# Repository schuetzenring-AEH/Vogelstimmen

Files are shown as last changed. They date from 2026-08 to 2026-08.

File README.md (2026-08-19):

# Vogelstimmenkasten – Waldlehrpfad (Rev 2)

Neubau der Elektronik eines Vogelstimmenkastens für den Waldlehrpfad der Kolpingfamilie.

## Überblick

Besucher können per Knopfdruck (8 beleuchtete Taster) verschiedene Vogelstimmen anhören. Die Elektronik ist auf **null Ruhestrom** optimiert (Hardware-Latch) und wird über eine 12-V-Autobatterie betrieben.

**Architektur:** DY-SV17F (IO-Trigger, integrierter Class-D-Verstärker) + Hardware-Latch (MOSFET-Selbsthaltung)

## Projektstatus

| Phase | Status |
|---|---|
| Anforderungen | ✅ fertig |
| Systemarchitektur (BDD/IBD) | ✅ fertig |
| Schaltplan-Dokumentation Rev 2 | ✅ fertig |
| BOM-Verfügbarkeit (LCSC/JLCPCB) | ✅ geprüft |
| Digitaler Zwilling (Bauteilebene) | ✅ `docs/digitaler_zwilling.md` |
| KiCad-Schaltplan (+ VGS-Zener D11/D12) | ✅ verdrahtet |
| PCB Rev 2.4 + Respin F-01…F-05 | ✅ Working-PCB DRC/ERC 0 Fehler |
| Gerber / BOM / CPL | ✅ `hardware/V2.5-final/` (FREIGABE MIT AUFLAGEN) |
| M04-Review / Adversarial | ✅ F-01…F-09 dispositioniert; Proto-Auflagen |
| Fertigung & Inbetriebnahme | ▶️ JLCPCB bestellbar; Proto messen vor Serie |
| MBSE-Showcase (USB) | ✅ `showcase/` + `dist/Vogelstimmen-MBSE-USB.zip` |

**Reviewer-Einstieg:** [docs/reviewer_handoff.md](docs/reviewer_handoff.md) · Checkliste [docs/review_checkliste_m04.md](docs/review_checkliste_m04.md)  
Details: **[docs/zwischenstand.md](docs/zwischenstand.md)**

## Projektstruktur

| Ordner | Inhalt |
|---|---|
| `docs/` | Lastenheft, Architektur, ADRs, Traceability, Zwilling, Zwischenstand |
| `hardware/V2.5-final/` | Fertigungspaket Rev 2.5 (Gerber, BOM, CPL, KiCad, PDFs) |
| `simulation/` | Interaktive Platinen-Simulation (HTML5) |
| `showcase/` | **MBSE-Präsentation** (offline Website) — `START_SHOWCASE.bat` |
| `mbse/` | Impact-Analyse, Audit, SysML/JSON-Export — URL `/mbse/` |
| `dist/` | USB-ZIP nach `tools/package_mbse_usb.ps1` |
| `rev1_archiv/` | Rev-1-Archiv (Lessons Learned) |

## Technische Eckdaten

- **Audio-Modul:** DY-SV17F (8× IO-Trigger, Mode 0, 5W Class-D, USB-Upload)
- **Versorgung:** 12V Bleiakku → TPS62163 Buck → 5V
- **Stromsparen:** Hardware-Latch — Idle ≈12 µA (R6=470 kΩ, E-RPP-01)
- **Schutz:** Verpolung SI2301+**D11 Zener 6,2 V**, Latch Q1+**D12**, TVS SMAJ15A, PTC 1A/24V
- **Zähler:** Kübler K07.90 (5V DC, elektromechanisch, Anzeige oben, zählt Aufweck-Events)
- **Taster-LEDs:** 8× beleuchtete Taster (6–24V LEDs über 12V_SW Rail)
- **Audioformat:** MP3/WAV direkt per USB auf DY-SV17F laden
- **Digitaler Zwilling:** [docs/digitaler_zwilling.md](docs/digitaler_zwilling.md)

## Rev 1 → Rev 2: Lessons Learned

Rev 1 hatte Probleme mit Spannungsfestigkeit (U4/U5 Burnout bei 12V), Bauteil-Verfügbarkeit und fehlendem Verifikationsansatz. Rev 2 verwendet:
- MBSE / V-Modell mit Traceability
- Durchgängige Spannungsprüfung aller Bauteile
- BOM-Verfügbarkeit vorab bei LCSC geprüft
- Digitaler Zwilling zur Logikverifikation

## Voraussetzungen (Entwicklung)

- [KiCad 10](https://www.kicad.org/) – Schaltplan/PCB
- Python 3 – lokale Simulation (`python simulation/serve.py`) oder `START_SHOWCASE.bat` / `START_MBSE.bat`
- [LTspice](https://www.analog.com/en/resources/design-tools-and-calculators/ltspice-simulator.html) – analoge Teilschaltungen (optional)

## Lizenz

Dieses Projekt ist für den internen Gebrauch der Kolpingfamilie bestimmt.

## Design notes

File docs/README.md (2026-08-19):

# Dokumentation – Vogelstimmenkasten Rev 2.5

Stand: **3. August 2026**

## Showcase / Team-Demo

| Dokument / Ort | Inhalt |
|---|---|
| **[../showcase/](../showcase/)** | Interaktive V-Modell-/MBSE-Website (`START_SHOWCASE.bat`) |
| **[../mbse/](../mbse/)** | Impact-Analyse, Audit, Export (`/mbse/`) |
| **[mbse_pitch.md](mbse_pitch.md)** · **[mbse_pitch_krones.md](mbse_pitch_krones.md)** | Präsentation / Vorstand-Pitch |
| **[mbse_reise.md](mbse_reise.md)** | Abdeckungskarte: vorhanden / teilweise / weggelassen / offen |

## V-Modell — Spezifikation (links)

| Dokument | Inhalt |
|---|---|
| [stakeholder.md](stakeholder.md) | Stakeholder, Needs → Requirements |
| [anforderungen.md](anforderungen.md) | Lastenheft F/E/U/H/M |
| [pflichtenheft.md](pflichtenheft.md) | Implementierungs-Baseline, SYS-* |
| [use_cases.md](use_cases.md) | UC-01…05, Szenarien |
| [funktionsstruktur.md](funktionsstruktur.md) | Blackbox, Funktionsbaum |
| [systemarchitektur.md](systemarchitektur.md) | Blöcke B1–B8, Domänen, Zustände |
| [mbse_sysml.md](mbse_sysml.md) | SysML-Diagrammrollen (Mermaid/Tabellen) |
| [pbs_icd.md](pbs_icd.md) | Product Breakdown + Interface Control |
| [entscheidungen.md](entscheidungen.md) | ADRs |
| [risiko_fmea.md](risiko_fmea.md) | Risiko / Design-FMEA light |

## Design, Twin, Trace (Mitte / Thread)

| Dokument | Inhalt |
|---|---|
| [schaltplan.md](schaltplan.md) | Schaltplan-Blöcke, Netze, BOM-Link |
| [bom_verfuegbarkeit.md](bom_verfuegbarkeit.md) | LCSC / BOM-Gate M01 |
| [digitaler_zwilling.md](digitaler_zwilling.md) | Verhaltens-Twin |
| [traceability.md](traceability.md) | RTM Req → Funktion → Physikalisch → V |
| [digital_thread.md](digital_thread.md) | End-to-End-Verknüpfungskette |
| [kicad_anleitung.md](kicad_anleitung.md) | KiCad 10 Arbeitsfluss |

## V&V, Freigabe, Fertigung (rechts)

| Dokument | Inhalt |
|---|---|
| [vv_testplan.md](vv_testplan.md) | Teststrategie, TC-U/I/T/S/A |
| [reviewer_handoff.md](reviewer_handoff.md) | Einstieg Reviewer |
| [review_checkliste_m04.md](review_checkliste_m04.md) | M04-Checkliste |
| [../hardware/V2.5-final/docs/adversarial_review_v25.md](../hardware/V2.5-final/docs/adversarial_review_v25.md) | Adversarial Review Rev 2.5 |
| [montage_ibn.md](montage_ibn.md) | Montage & Inbetriebnahme |
| [service_betrieb.md](service_betrieb.md) | Service, Wartung, Constraints |
| [konfiguration_baseline.md](konfiguration_baseline.md) | CM / Baseline light |
| [../hardware/V2.5-final/](../hardware/V2.5-final/) | Gerber, BOM, CPL, PDFs, KiCad |

## Weitere / Historie

| Dokument | Inhalt |
|---|---|
| [zwischenstand.md](zwischenstand.md) | Projektstand |
| [pcb_v2.4.md](pcb_v2.4.md) u. a. | Ältere PCB-Stände |
| [datasheets/](datasheets/) | Datenblätter |
| `../rev1_archiv/docs/` | Rev‑1-Archiv |

**Bewusst weggelassen:** Business Case/Markt/ROI, APQP/PPAP, CE-Vollakte, CAD/FEM (Gehäuse Bestand), App-SRS (Modul-Firmware).

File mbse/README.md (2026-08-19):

# Platinen-MBSE App (Impact · Audit · Export)

Eigenständige Web-App unter GitHub Pages: **`/mbse/`**  
Showcase-Teaser: `#/copilot` · Präsentation: `#/pitch` oder [`presentation.html`](presentation.html)

Der Vogelstimmenkasten ist ein **exemplarischer Referenz-Rahmen** — klein, vollständig, übertragbar auf eine Produktlinie. Der Mehrwert ist nicht die Menge der Dokumente, sondern **Konsistenz, Durchgängigkeit und ein Digital Thread**.

## Start

Lokal (Python): `START_MBSE.bat` → http://127.0.0.1:8781/

Oder Showcase-Server: `START_SHOWCASE.bat` → http://127.0.0.1:8877/mbse/

What-if-Demo: [`index.html?demo=e03`](index.html?demo=e03) (E03: 12 → 18 Monate)

## Struktur

| Pfad | Rolle |
|---|---|
| `data/mbse-model.json` | Zentrale Quelle (Knoten + Kanten) |
| `data/impact-rules.json` | What-if-Regeln (battery_life, idle_current) |
| `js/graph-engine.js` | Traversal, Impact-Farben, Zyklen |
| `js/impact.js` | UI Graph + Listenansicht |
| `js/audit.js` | Traceability-Prüfungen |
| `js/export.js` | JSON / PlantUML / SysML v2 Text |
| `tools/build-model.mjs` | Regeneriert das JSON aus strukturierten Artefakten |

```bash
node mbse/tools/build-model.mjs
```

**IDs:** `F01` = Lastenheft-Requirement; `FIND-F-01` = adversarial Finding.

## Export-Grenze (ehrlich)

Phase 1 liefert textuellen SysML-v2-Subset + JSON. Kein zertifizierter Cameo/MagicDraw/Capella-Roundtrip. Modellverluste stehen im Export-Tab.

---

## Roadmap Phase 2–4 (nicht in Phase 1)

### Priorität 3 — KI Requirements Engineer

Eingabe: Freitext-Anforderung. Die KI erzeugt Stakeholder Need, System Requirement, Akzeptanzkriterien, Funktionszuordnung, Verifikationsmethode, Risiken und Traceability-Links — alle mit stabilen IDs.

- Statische App + optional API-Key (OpenAI/Anthropic) **oder** Offline: JSON exportieren → Cursor/CI → re-import
- Geplant: `js/ai-review.js` — Eindeutigkeit, Testbarkeit, Konflikte mit dem bestehenden Graph
- Kein Server auf GitHub Pages nötig für Demo v1 (Key im Browser, Nutzer-Hinweis)
- Human-in-the-loop: keine Auto-Freigabe

### Priorität 4 — Digital Twin + Änderungs-Simulation

„Was passiert wenn …“ (z. B. Batterie halbieren): Laufzeit, Risiko, Kosten, Testauswirkungen.

- Parameter aus Requirements (E03, E02) koppeln an [`../simulation/js/model.js`](../simulation/js/model.js)
- Impact-Graph markiert, welche Tests/Risiken neu bewertet werden
- Dashboard: Laufzeit, Risiko-Ampel, Kosten-Schätzung, Test-Invalidierung

### Priorität 5 — Review- und Freigabe-Cockpit

Governance-Dashboard (`/mbse/#/governance` oder Showcase-Teaser):

- Traceability Coverage, Testabdeckung, Risikoabdeckung
- Offene ADRs / Reviews
- Ampelsystem + Auditbericht (Erweiterung von `audit.js`)
- Management-KPIs: Time-to-Impact, Change-Rework — nicht Folienzahl

---

## Abnahme Phase 1

- [x] Präsentation 7 Folien, Demo-Sprung E03, druckbar (`presentation.html`, `@media print`)
- [x] Kernbotschaft: Mehrwert = Konsistenz/Digital Thread, nicht Dokumentenmenge
- [x] E03 12→18 Monate färbt Wirkungskette
- [x] Audit mit Findings (u. a. Unit-Tests ohne verifies)
- [x] JSON-Export = Modell; SysML/PlantUML enthalten IDs und Trace-Kanten
- [x] Showcase `#/pitch` + `#/copilot` → `/mbse/`

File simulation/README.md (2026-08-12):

# Platinen-Simulation (HTML5 + JS)

Interaktive **Rev-3.0**-Simulation: Taster drücken → Phasenablauf (inkl. Zähler-One-Shot) → Spannungen/Ströme pro Bauteil auf dem Platinen-Abbild.

## Start

**Empfohlen (frische Adresse, kein Cache von alter Session):**

```bash
simulation/start_rev25.bat
```

Öffnet **http://127.0.0.1:8766/**

Alternativ (Port 8765):

```bash
python simulation/serve.py
```

Port wählen: `python simulation/serve.py --port 8766`

## Aufbau

| Datei | Rolle |
|---|---|
| `index.html` | UI (Platine SVG, Taster, Tabelle) |
| `js/parts.js` | Datenblatt-Parameter (Rev 3.0, Laufzeit) |
| `js/model.js` | Verhaltensmodell inkl. One-Shot / Hengstler |
| `js/catalog.js` / `diagrams.js` | Baugruppen-Texte + SVG-Hilfsdiagramme |
| `src/parts.ts` / `src/model.ts` | TypeScript-Spiegel (Pflege parallel zu `js/`) |
| `pcb_layout.json` | Footprint-Positionen aus KiCad **V3.0** |
| `pcb_tracks.json` | Leiterbahnen + Vias |
| `tools/export_layout.py` | Neu-Export Footprints (KiCad-Python) |
| `tools/export_tracks.py` | Neu-Export Tracks/Vias (KiCad-Python) |

Nach PCB-Änderungen beide Exports mit KiCad-Python neu laufen lassen:

```bash
& "C:\Program Files\KiCad\10.0\bin\python.exe" simulation/tools/export_layout.py
& "C:\Program Files\KiCad\10.0\bin\python.exe" simulation/tools/export_tracks.py
```

## Rev 3.0 — Zähler-One-Shot (E-CNT-03/04)

| Ref | Rolle für den Hengstler |
|-----|---|
| **J5** | Hengstler **0.635.128** (12 V, Spule 1860 Ω): Pad1 = `12V_SW`, Pad2 = `CNT_LO` |
| **C20** | 1 µF: koppelt nur die Rising-Edge von `12V_SW` → `CNT_PULSE` |
| **R20** | 100 kΩ: Entladung / Pulsbreite (~R·C ≈ 100 ms, effektiv ~80 ms) |
| **R21** | 100 Ω: Serie zum Gate von Q7 |
| **D23** | Clamp: hält `CNT_PULSE` ≥ −Vf gegen GND |
| **Q7** | AO3400 Low-Side: zieht `CNT_LO` kurz nach GND → Spule zählt +1 |
| **D10** | Freilauf parallel zur Spule (K→`12V_SW`, A→`CNT_LO`) |

Phase `cnt_pulse`: Latch gerade AN, Spulenstrom ≈6,5 mA für ~80 ms, danach Spule aus für den Rest der Session. Idle: `12V_SW` tot → 0 mA.

## Respin (weiterhin gültig)

| Fix | Simulation |
|-----|---|
| F-01 D15–D22 | Serie-Dioden U2↔IOx |
| F-02 R5=0 Ω | VOS direkt 5 V |
| F-03 R13+C4 | RC-Blanking Q3_GATE (~470 ms) |
| F-04 R12 | LED-Strombegrenzung 12V_LED |

## Modellierung

- **Diskret (Ohm/Kirchhoff):** R1–R13, R20/R21, Dioden, Zener-Clamp, FET als Schalter mit Rds(on)/VGS
- **Blöcke:** TPS62163 (η + IQ), DY-SV17F (Boot/BUSY/Play-Strom), Hengstler (Rcoil 1860 Ω @12 V, nur während One-Shot)
- **Kein** SPICE-Transient — DC-Arbeitspunkte pro Phase; RC-Blanking + One-Shot als Timer

## Datenblätter

Siehe `docs/datasheets/`, `hardware/V3.0/docs/` und Parameter in `js/parts.js`.

| Bauteil | Parameter | Quelle |
|---|---|---|
| SI2301CDS | VGS max ±8 V, RDS(on) typ 90 mΩ | Vishay |
| AO3400 (Q7) | Low-Side CNT_LO | AOS / LCSC C20917 |
| Hengstler 0.635.128 | 12 V, 1860 Ω ≈80 mW, min. Impuls 50 ms | Hengstler 634/635 |
| DY-SV17F | Idle **14 mA**; Betrieb **≤60 mA**; V33 max 80 mA | Messung / Spec |
| R6 | 470 kΩ → Idle ≈12 µA | E-RPP-01 |

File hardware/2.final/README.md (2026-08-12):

# Fertigungspaket Rev 2.4 — `2.final`

**Datum:** 3. August 2026  
**Projekt:** Soundplatine Waldlehrpfad / Kolping Alteglofsheim  
**KiCad Working:** `hardware/vogelstimmen_v2.4.*`

> **Hinweis:** Dieses Paket ist **Pre-Respin** (Stand 01.08.2026).  
> Vor JLCPCB-Bestellung aus dem **aktuellen Working-PCB** (Respin F-01…F-05) neu exportieren: Gerber, BOM, CPL, PDFs.

## Respin F-01…F-05 (Working-PCB)

| Änderung | Bauteile |
|---|---|
| Modul-IO-Schutz | D15–D22 |
| VOS direkt | R5 = 0 Ω |
| BUSY-Blanking | R13, C4 |
| LED-Serie | R12, Netz 12V_LED |
| SPK-Breite | ≥ 0,4 mm |

DRC/ERC Working: **0 Fehler** (Stand 03.08.2026).

## Inhalt (Stand Paket)

| Datei / Ordner | Zweck |
|---|---|
| `vogelstimmen_v2.4.kicad_sch` | Schaltplan (KiCad) — **ggf. veraltet** |
| `vogelstimmen_v2.4.kicad_pcb` | Layout — **Pre-Respin** |
| `vogelstimmen_v2.4-Gerber.zip` | Gerber — **Pre-Respin** |
| `JLCPCB_BOM.csv` | SMD-BOM — **Respin-Zahlen aktualisiert** |
| `docs/` | Review-Dokumente |

Aktuelle Quellen: `../vogelstimmen_v2.4.kicad_pcb`, `../../docs/schaltplan.md`

## Manuell (nicht JLCPCB-SMD)

- **U2** DY-SV17F  
- **J5** Kübler `1.130.900.008`  
- **J3/J4/J1/J2/J6** Phoenix MPT  

## Design-Review

[`../../docs/reviewer_handoff.md`](../../docs/reviewer_handoff.md) · [`../../docs/review_checkliste_m04.md`](../../docs/review_checkliste_m04.md)

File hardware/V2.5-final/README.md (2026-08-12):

# Fertigungspaket Rev 2.5 — `V2.5-final`

**Datum:** 3. August 2026  
**Projekt:** Soundplatine Waldlehrpfad · Kolping Alteglofsheim · Konrad Senn  
**KiCad:** 10.0.4 · Quelle: `vogelstimmen_v2.5.kicad_*` (Respin F-01…F-05 + GND-Vias)

## Freigabe-Stand

| Check | Ergebnis |
|---|---|
| **DRC** | **0 Fehler**, 0 unverbunden — 1 Warnung U2 Footprint-Lib (`DRC_v2.5_final.rpt`) |
| **ERC** | **0 Fehler** — 1 Warnung Label `SET_DRV` (`ERC_v2.5_final.rpt`) |
| **F-01…F-09** | Behoben / dispositioniert — `docs/adversarial_review_v25.md` |

## JLCPCB — Upload (nur SMD)

| Datei | Zweck |
|---|---|
| **`vogelstimmen_v2.5-Gerber.zip`** | Gerber + Drill (Ordner `Gerber/`) |
| **`JLCPCB_BOM.csv`** | **nur SMT** — Spalte `Mount=SMT` · kein Modul/Klemmen/Zähler |
| **`JLCPCB_CPL.csv`** | Pick-and-Place **JLCPCB-Format** (Designator/Mid X/Mid Y) — **diese** hochladen |
| `vogelstimmen_v2.5-cpl.csv` | KiCad-Roh-CPL (nicht für Upload — falsche Spaltennamen) |

**Nicht** an JLCPCB hochladen: `HAND_BESTUECKUNG.csv`, `vogelstimmen_v2.5-bom.csv` (KiCad-Voll-BOM mit THT).

**Platinen-Parameter (empfohlen):** 2 Layer · 1,6 mm · HASL oder ENIG · Design-Regeln wie im Projekt (0,2 mm Clearance, Via 0,6/0,3 mm).

## Handbestückung (nicht in JLCPCB-BOM)

Datei: **`HAND_BESTUECKUNG.csv`** — Spalte `Assembly=HAND` bzw. `DNP` (Testpads).

| Ref | Teil | Assembly |
|-----|---|---|
| **U2** | DY-SV17F (optional 2×9-Pin-Sockel) | HAND |
| **J5** | Kübler `1.130.900.008` | HAND |
| **J1, J2, J6** | Phoenix MPT 0,5/2-2,54 (×3) | HAND |
| **J3, J4** | Phoenix MPT 0,5/8-2,54 (×2, z. B. 1725711) | HAND |
| **TP1–TP5** | Testpads | DNP (kein Bauteil) |

## Paketinhalt

| Datei / Ordner | Inhalt |
|---|---|
| `Gerber/` | Einzel-Gerber + `.drl` + `.gbrjob` |
| `vogelstimmen_v2.5-Gerber.zip` | Upload-Paket |
| `JLCPCB_BOM.csv` | **SMT-only** für JLCPCB Assembly |
| `JLCPCB_CPL.csv` | **CPL Upload** (JLCPCB-Spaltennamen) |
| `JLCPCB_CPL_minimal.csv` | Fallback-CPL (nur 5 Spalten), falls volles Format scheitert |
| `HAND_BESTUECKUNG.csv` | **Handteile** + DNP-Testpads (nicht JLCPCB) |
| `vogelstimmen_v2.5-bom.csv` | KiCad-Voll-BOM (SMT+THT — nicht für SMT-Upload) |
| `vogelstimmen_v2.5-cpl.csv` | KiCad-Roh-CPL (nicht hochladen) |
| `vogelstimmen_v2.5-all-pos.csv` | Alle Positionen |
| `vogelstimmen_v2.5-schematic.pdf` | Schaltplan-PDF |
| `vogelstimmen_v2.5-pcb.pdf` | Layout-PDF |
| `vogelstimmen_v2.5.kicad_sch/pcb/pro` | KiCad-Quellen (Stand Export) |
| `docs/` | DRC/ERC, Review, Schaltplan-Doku |
| `simulation/` | HTML5-Platinen-Simulation Rev 2.5 (siehe unten) |

## Simulation

**Empfohlen:** Doppelklick auf `simulation/start_rev25.bat`  
→ **http://127.0.0.1:8766/** (eigener Port, umgeht Browser-Cache von :8765)

Alternativ: `python simulation/serve.py` → http://127.0.0.1:8765/

## Änderungen Rev 2.5 (gegenüber Erstlayout vor Respin, archiviert)

| ID | Änderung |
|----|---|
| F-01 | D15–D22 Serie U2↔IOx |
| F-02 | R5 = 0 Ω |
| F-03 | R13 + C4 BUSY-Blanking |
| F-04 | R12 = 10 Ω → 12V_LED |
| F-05 | SPK ≥ 0,4 mm (Haupt 0,8 mm) |
| Layout | +13 GND-Vias (Stitching U1/C1–C4) |

## IBN-Hinweise

- **USB:** nur Modul abgezogen oder Latch aus (F-09)  
- **Proto optional:** F-03 Oszi, F-04 LED-Strom, F-08 5 V unter Last  

Review: `docs/reviewer_handoff.md` · Checkliste: `docs/review_checkliste_m04.md`

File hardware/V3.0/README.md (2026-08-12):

# Fertigungspaket Rev 3.0

**Datum:** 11. August 2026  
**Projekt:** Soundplatine Waldlehrpfad · Kolping Alteglofsheim  
**KiCad:** 10.0.4 · `vogelstimmen_v3.0.kicad_*`

## Freigabe-Stand

| Check | Ergebnis |
|---|---|
| **DRC** | **0 Fehler**, 0 unverbunden — 1 Warnung U2 Footprint-Lib (`DRC_v3.0_final.rpt`) |
| **ERC** | siehe `ERC_v3.0_final.rpt` |
| **Widerstände** | alle **15×** `R_0603_1608Metric`, Pad-Pitch **1,65 mm** (kein 0402) |
| **Zähler** | Hengstler 0.635.128 + One-Shot (C20/R20/R21/D23/Q7/D10) |

## JLCPCB — Upload (nur SMD)

| Datei | Zweck |
|---|---|
| **`vogelstimmen_v3.0-Gerber.zip`** | Gerber + Drill (auch Ordner `Gerber/`) |
| **`JLCPCB_BOM.csv`** | SMT-BOM inkl. One-Shot + 0603 Basic LCSC |
| **`JLCPCB_CPL.csv`** | Pick-and-Place (52 SMT-Teile) — **diese** hochladen |
| `JLCPCB_CPL_minimal.csv` | Fallback (5 Spalten), falls volles Format scheitert |

**Nicht** an JLCPCB hochladen: `HAND_BESTUECKUNG.csv`, KiCad-Roh-CPL mit Handteilen.

**Platinen-Parameter (empfohlen):** 2 Layer · 1,6 mm · HASL oder ENIG · Clearance 0,2 mm · **Min. Bahnbreite 0,3 mm** · Via 0,6/0,3 mm.

## Handbestückung (nicht in JLCPCB-BOM)

Datei: **`HAND_BESTUECKUNG.csv`**

| Ref | Teil | Assembly |
|-----|---|---|
| **U2** | DY-SV17F | HAND |
| **J5** | Hengstler **0.635.128** (nicht 0.635.132) | HAND |
| **J1, J2, J6** | Phoenix MPT 0,5/2 | HAND |
| **J3, J4** | Phoenix MPT 0,5/8 | HAND |
| **TP1–TP5** | Testpads | DNP |

## Widerstände — Package-Check (E-R0603)

| Refs | Wert | Footprint PCB | LCSC | Package |
|---|---|---|---|---|
| R1,R2,R13,R20 | 100k | R_0603_1608Metric | C25803 | 0603 Basic |
| R3,R4,R9 | 10k | R_0603_1608Metric | C25804 | 0603 Basic |
| R5 | 0R | R_0603_1608Metric | C21189 | 0603 Basic |
| R6 | 470k | R_0603_1608Metric | C23178 | 0603 Basic |
| R7,R8,R11 | 4.7k | R_0603_1608Metric | C23162 | 0603 Basic |
| R10 | 1k | R_0603_1608Metric | C21190 | 0603 Basic |
| R12 | 10R | R_0603_1608Metric | C22859 | 0603 Basic |
| R21 | 100R | R_0603_1608Metric | C25796 | 0603 Basic |

Pads gemessen: **0,80×0,95 mm**, Mittenabstand **1,65 mm** → passt zu 0603 (0402 wäre ~1,0 mm).

## Änderungen gegenüber 2.5

| Thema | 2.5 | 3.0 |
|---|-----|-----|
| Widerstände | Pads oft 0402 / LCSC 0603 → Reject | **0603 Pads + 0603 Basic LCSC** |
| Zähler J5 | Kübler K07.90 | **Hengstler 0.635.128** + One-Shot ~80 ms |
| Form | Panel / groß | Body **25,2×31 mm**, 4 Pins 15,24×25,4 mm |

## Paketinhalt

| Datei / Ordner | Inhalt |
|---|---|
| `Gerber/` | Einzel-Gerber + PTH/NPTH Drill |
| `vogelstimmen_v3.0-Gerber.zip` | **Upload-Paket** |
| `JLCPCB_BOM.csv` / `JLCPCB_CPL.csv` | SMT Assembly |
| `HAND_BESTUECKUNG.csv` | Handteile |
| `vogelstimmen_v3.0-schematic.pdf` | Schaltplan |
| `vogelstimmen_v3.0-pcb.pdf` | Layout |
| `docs/` | ADRs, Schaltplan, BOM-Checkliste |
| `tools/export_fab.py` | Re-Export Gerber/CPL/PDF |

## Re-Export

```powershell
& "C:\Program Files\KiCad\10.0\bin\python.exe" hardware\V3.0\tools\export_fab.py
```

## Parallel bestellen

1. JLCPCB: Gerber.zip + BOM + CPL (SMD Assembly)
2. Hengstler 0.635.128 (Mercateo/RS/Farnell) — Lieferzeit oft Wochen
3. DY-SV17F + Phoenix MPT-Klemmen

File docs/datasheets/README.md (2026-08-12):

# Datenblätter

Lokal gespeicherte PDFs (Stand 01.08.2026) + Simulationsparameter in `simulation/js/parts.js`.

| Datei | Bauteil | Status |
|---|---|---|
| [Si2301CDS.pdf](Si2301CDS.pdf) | Vishay SI2301CDS P-FET | OK |
| [TPS62163.pdf](TPS62163.pdf) | TI TPS62163 Buck 5 V | OK |
| [BZX84C6V2_Nexperia.pdf](BZX84C6V2_Nexperia.pdf) | BZX84 Serie (6,2 V) | OK |
| [SMAJ15A.pdf](SMAJ15A.pdf) | Vishay/SMAJ TVS 15 V | OK |
| [DY-SV17F.pdf](DY-SV17F.pdf) | Audio-Modul Functions (kein Iq; V33 max 80 mA) | OK |
| [Kuebler_K04-K07.pdf](Kuebler_K04-K07.pdf) | Kübler K04–K07 (historisch, E-CNT-01) | Archiv |
| [Kuebler_K04-K07_AK07.pdf](Kuebler_K04-K07_AK07.pdf) | Kübler (älterer Stand) | Archiv |

**Zähler Rev 3.0:** Hengstler **0.635.128** — PDF unter `hardware/V3.0/docs/Hengstler_634_635.pdf` (bzw. Impulse-Automation Datasheet). Kübler gestrichen (E-CNT-02).

**Nicht lokal (CDN-Block):** onsemi 2N7002L / 1N4148WS — Parameter aus Hersteller-Datenblatt übernommen (siehe `simulation/js/parts.js`).

### DY-SV17F — Strom (extern belegt)

| | Wert | Quelle |
|--|---|---|
| Idle | **14 mA** @5 V | Messung (Amp LTK5128 + Flash) — [GitHub arduino12](https://github.com/arduino12/mp3_player_module_wire) |
| Betrieb | **≤60 mA** @5 V | Spec „Потребление тока: до 60мА“ — [compacttool.ru](https://compacttool.ru/mp3wav-pleer-dy-sv17f-s-mono-audiousilitelem-5vt) |
| V33 | max 80 mA | Modul-PDF (**Ausgang**, nicht Modul-Iq) |
| Lautsprecher | zusätzlich | Class-D; Spitzen je nach Pegel höher |

### Bestellhinweis Zähler (Rev 3.0)

**Hengstler 0.635.128** (Typ 635.1, 12 V, 6 Stellen, Spule 1860 Ω ≈80 mW, 4 PCB-Pins). Ansteuerung: One-Shot an `12V_SW` (nicht dauerhaft an 5 V). Details: `hardware/V3.0/docs/entscheidungen_v30.md`.

~~K07.90 1.130.900.008~~ — nicht mehr beschaffbar / ersetzt.

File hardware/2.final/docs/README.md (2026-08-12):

# Dokumentation – Vogelstimmenkasten Rev 2

Stand: **3. August 2026**

## Review vor Fertigung (Start hier)

| Dokument | Inhalt |
|---|---|
| **[reviewer_handoff.md](reviewer_handoff.md)** | **Einstieg für Reviewer** — Lesereihenfolge, Scope, Artefakte |
| **[review_checkliste_m04.md](review_checkliste_m04.md)** | **M04-Checkliste** — abhaken + Signatur Freigabe/Sperre |
| **[adversarial_review_v24.md](adversarial_review_v24.md)** | **Adversarial Review** — F-01…F-09 geschlossen (Respin + Restrisiko) |
| [zwischenstand.md](zwischenstand.md) | Aktueller Projektstand |
| `../hardware/2.final/` | Gerber, BOM, CPL, PDFs |

Canvas (Cursor, neben Chat): `fertigung-readiness-v24.canvas.tsx`

## Dokumente

| Dokument | Inhalt |
|---|---|
| [anforderungen.md](anforderungen.md) | Lastenheft — Muss- und Kann-Anforderungen |
| [systemarchitektur.md](systemarchitektur.md) | BDD, IBD, Zustandsdiagramm, Timing, Spannungsebenen |
| [digitaler_zwilling.md](digitaler_zwilling.md) | Digitaler Zwilling System→Block→**Bauteil** (inkl. VGS-Zener) |
| [schaltplan.md](schaltplan.md) | Schaltplan Rev 2 — Blöcke B1–B8, Netzliste, BOM |
| [bom_verfuegbarkeit.md](bom_verfuegbarkeit.md) | LCSC-Verfügbarkeit aller SMD-Bauteile |
| [traceability.md](traceability.md) | Traceability-Matrix und Verifikationsplan |
| [kicad_anleitung.md](kicad_anleitung.md) | KiCad 10 — Labels, ERC, Footprints, VGS-Verdrahtung |
| [entscheidungen.md](entscheidungen.md) | Designentscheidungen (Latch, VGS, Zähler, MPT) |
| [pcb_v2.4.md](pcb_v2.4.md) | PCB Rev 2.4 |
| [datasheets/](datasheets/) | Datenblätter (Kübler u. a.) |

## Archiv

Rev-1-Dokumentation liegt in `../rev1_archiv/docs/`.

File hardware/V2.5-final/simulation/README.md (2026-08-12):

# Platinen-Simulation (HTML5 + TypeScript/JS)

Interaktive Rev-2.5-Simulation: Taster drücken → Phasenablauf → Spannungen/Ströme pro Bauteil auf dem Platinen-Abbild.

## Start

**Empfohlen (frische Adresse, kein Cache von alter Session):**

```bash
simulation/start_rev25.bat
```

Öffnet **http://127.0.0.1:8766/**

Alternativ (Port 8765):

```bash
python simulation/serve.py
```

Öffnet `http://127.0.0.1:8765/`.

Port wählen: `python simulation/serve.py --port 8766`

## Aufbau

| Datei | Rolle |
|---|---|
| `index.html` | UI (Platine SVG, Taster, Tabelle) |
| `src/parts.ts` | Datenblatt-Parameter (TypeScript-Quelle) |
| `src/model.ts` | Verhaltensmodell (TypeScript-Quelle) |
| `js/parts.js` / `js/model.js` / `js/app.js` | Lauffähige ESM-Module |
| `pcb_layout.json` | Footprint-Positionen aus KiCad v2.5 (63 Bauteile, 32 Vias) |
| `pcb_tracks.json` | Leiterbahnen + Vias |
| `tools/export_layout.py` | Neu-Export Footprints (KiCad-Python) |
| `tools/export_tracks.py` | Neu-Export Tracks/Vias (KiCad-Python) |

Nach PCB-Änderungen beide Exports mit KiCad-Python neu laufen lassen:

```bash
& "C:\Program Files\KiCad\10.0\bin\python.exe" simulation/tools/export_layout.py
& "C:\Program Files\KiCad\10.0\bin\python.exe" simulation/tools/export_tracks.py
```

## Rev 2.5 (Respin)

| Fix | Simulation |
|-----|---|
| F-01 D15–D22 | Serie-Dioden U2↔IOx in `parts.js` / `catalog.js` |
| F-02 R5=0 Ω | VOS direkt 5 V |
| F-03 R13+C4 | RC-Blanking Q3_GATE (~470 ms) in `model.js` |
| F-04 R12 | LED-Strombegrenzung 12V_LED |
| Layout | 32 GND-Vias in `pcb_tracks.json` |

## Modellierung

- **Diskret (Ohm/Kirchhoff):** R1–R13, Dioden, Zener-Clamp, FET als Schalter mit Rds(on)/VGS
- **Blöcke:** TPS62163 (η + IQ), DY-SV17F (Boot/BUSY/Play-Strom), Kübler (Rcoil aus 50 mW @ 4,5 V)
- **Kein** SPICE-Transient — DC-Arbeitspunkte pro Phase; RC-Blanking als einfacher Tiefpass

## Datenblätter

Siehe `docs/datasheets/` und Parameter-Kommentare in `js/parts.js`.

### Wichtige verifizierte Werte

| Bauteil | Parameter | Quelle |
|---|---|---|
| SI2301CDS | VGS max ±8 V, RDS(on) typ 90 mΩ @−4,5 V | Vishay |
| BZX84C6V2 | Vz 6,2 V | Nexperia/Good-Ark |
| 2N7002L | VGS(th) 1–2,5 V, RDS max 7,5 Ω | onsemi |
| TPS62163 | VOUT 5 V fest, IQ typ 17 µA | TI SLVSAM2E |
| SMAJ15A | VRWM 15 V, VBR 16,7–18,5 V | Littelfuse |
| K07.90 | ~50 mW @ Unenn (10 Hz) → @5 V ≈12 mA | Kübler |
| DY-SV17F | Idle **14 mA** (Messung); Betrieb **≤60 mA** (Spec); V33 max 80 mA | siehe unten |
| R6 | 470 kΩ → Idle ≈12 µA | E-RPP-01 |

### DY-SV17F Ströme (Quellen)

| Zustand | Strom | Quelle |
|---|---|---|
| Idle (powered, kein Play) | **14 mA** | Messung inkl. LTK5128 + 32 Mbit Flash; Sleep-Befehl wirkungslos — [arduino12/mp3_player_module_wire](https://github.com/arduino12/mp3_player_module_wire) |
| Betrieb (рабочий режим) | **bis 60 mA** | Händler-Spec — [compacttool.ru](https://compacttool.ru/mp3wav-pleer-dy-sv17f-s-mono-audiousilitelem-5vt) |
| Lautsprecher | extra (Sim: `Ispk_avg`) | Class-D; Spitzen je nach Lautstärke deutlich höher (Foren: ~110 mA … Angaben bis 500 mA) |
| V33-Ausgang | max **80 mA** | Modul-PDF — *Ausgang*, nicht Modul-Iq |

Im Hersteller-Functions-PDF steht **kein** Versorgungsstrom — nur V33-Limit.

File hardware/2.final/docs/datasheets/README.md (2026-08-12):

# Datenblätter

Lokal gespeicherte PDFs (Stand 01.08.2026) + Simulationsparameter in `simulation/js/parts.js`.

| Datei | Bauteil | Status |
|---|---|---|
| [Si2301CDS.pdf](Si2301CDS.pdf) | Vishay SI2301CDS P-FET | OK |
| [TPS62163.pdf](TPS62163.pdf) | TI TPS62163 Buck 5 V | OK |
| [BZX84C6V2_Nexperia.pdf](BZX84C6V2_Nexperia.pdf) | BZX84 Serie (6,2 V) | OK |
| [SMAJ15A.pdf](SMAJ15A.pdf) | Vishay/SMAJ TVS 15 V | OK |
| [DY-SV17F.pdf](DY-SV17F.pdf) | Audio-Modul Functions (kein Iq; V33 max 80 mA) | OK |
| [Kuebler_K04-K07.pdf](Kuebler_K04-K07.pdf) | Kübler K04–K07 / K07.90 | OK |
| [Kuebler_K04-K07_AK07.pdf](Kuebler_K04-K07_AK07.pdf) | Kübler (älterer Stand) | OK |

**Nicht lokal (CDN-Block):** onsemi 2N7002L / 1N4148WS — Parameter aus Hersteller-Datenblatt übernommen (siehe `simulation/js/parts.js`).

### DY-SV17F — Strom (extern belegt)

| | Wert | Quelle |
|--|---|---|
| Idle | **14 mA** @5 V | Messung (Amp LTK5128 + Flash) — [GitHub arduino12](https://github.com/arduino12/mp3_player_module_wire) |
| Betrieb | **≤60 mA** @5 V | Spec „Потребление тока: до 60мА“ — [compacttool.ru](https://compacttool.ru/mp3wav-pleer-dy-sv17f-s-mono-audiousilitelem-5vt) |
| V33 | max 80 mA | Modul-PDF (**Ausgang**, nicht Modul-Iq) |
| Lautsprecher | zusätzlich | Class-D; Spitzen je nach Pegel höher |

### Bestellhinweis K07.90

7-stellig, PCB liegend, Anzeige oben. Bestellnr. **1.130.900.008** (4,5 V DC / 10 Hz). Leistung ≈50 mW → bei 5 V-Rail ≈12 mA.

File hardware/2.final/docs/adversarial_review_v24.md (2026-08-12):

# Adversarial Hardware Review — Rev 2.4

**Rolle:** Senior Hardware / PCB Reviewer (Widerlegung, nicht Bestätigung)  
**Datum:** 1. August 2026  
**Quellen:** `vogelstimmen_v2.4.kicad_sch/pcb`, `docs/schaltplan.md`, TI SLVSAM2, Kübler/SI2301-Annahmen, `hardware/2.final/`

**Gesamtverdict (01.08.): SPERRE vor Fertigung** — mindestens zwei blockierende Schaltungs-/Datenblattfehler.

**Disposition F-01…F-09 (03.08.2026):** Alle Punkte **behoben** oder **Restrisiko bewusst akzeptiert** — siehe Tabelle unten. F-10…F-13 unverändert offen (Moderate/Minor).

| ID | Status | Maßnahme / Begründung |
|----|---|---|
| **F-01** | ✅ **Behoben** | D15–D22 Serie U2↔IOx (Respin) |
| **F-02** | ✅ **Behoben** | R5 = 0 Ω (VOS direkt) |
| **F-03** | ✅ **Behoben** | R13 + C4 BUSY-Blanking; Proto-Oszi empfohlen, nicht blockierend |
| **F-04** | ✅ **Behoben** | R12 = 10 Ω → 12V_LED; Strom/R12-Temp. im Betrieb messen |
| **F-05** | ✅ **Behoben** | SPK-Hauptpfad 0,8 mm; Stubs ≥ 0,4 mm (TP/J2) |
| **F-06** | ✅ **Akzeptiert** | Tasterleitungen **≤ 30 cm im Schrank** — Feld-ESD entfällt praktisch |
| **F-07** | ✅ **Akzeptiert** | SI2301 20 V vs. SMAJ15A ~24 V; Batteriebetrieb, kein Jumpstart |
| **F-08** | ✅ **Akzeptiert** | Hauptpfad 12V 0,5–0,7 mm; U1-Pad-Stubs 0,2–0,3 mm (Platzzwang); 0,2 mm nur Latch-Zweig |
| **F-09** | ✅ **Akzeptiert** | IBN: USB nur Modul abgezogen / Latch aus (Sockel) |

**Respin-Status:** F-01…F-05 im Working-PCB (`hardware/vogelstimmen_v2.4.*`). DRC **0** Fehler / **0** unverbunden; ERC **0** Fehler; Schaltplan-Parität OK. Fertigungspaket `2.final/` noch neu exportieren.

---

## F-01 · BLOCKER — 12 V-Domain an DY-SV17F-IOs (D1–D8) · **FIXED (Respin)**

**Befund (PCB verifiziert):** D1…D8: Pad1 (Kathode) = `/IOx`, Pad2 (Anode) = `/BTN_OR`; R9 = 10 kΩ von `/12V_PROT` → `/BTN_OR`. IOx liegen parallel an U2 und J3.

### 1. Warum Risiko?
Im Idle liegt `BTN_OR` ≈ 12 V. Die Dioden leiten vorwärts in die IO-Pins. Unversorgtes Modul: IO-Spannung / Phantom-Supply über ESD-Dioden → AbsMax verletzt, Latch-up, Zerstörung.  
Bei 5 V an: interne Pull-ups ≈ 3,3 V → Dioden leiten dauernd → `BTN_OR` wird auf ≈ 4 V geklemmt → Q6 bleibt ein → Doku „Idle BTN_OR=12 V, kein Strom“ ist falsch. Zusätzlich ~0,8–1 mA Idle-Pfad möglich → E02 (<100 µA) gebrochen.

### 2. Wahrscheinlichkeit
**Hoch** (Topologie zwingend; nicht spekulativ).

### 3. Schaden
**Kritisch** — Modul tot / unzuverlässig; Idle-Strom-Ziel verfehlt; möglicherweise Dauer-SET über Q6.

### 4. Korrektur
12 V-OR und Modul-IO galvanisch trennen, z. B.:
- Taster-Knoten nur über Transistor/Open-Collector → Q6-Gate/`BTN_OR`, **ohne** Diode von 12 V in IOx, **oder**
- getrennte Leitungen (IO nur 5 V-Domain; Latch-SET eigener Pfad),  
- plus IO-Serien-R + Clamp an 5 V nach Neudesign.  
**Respin Schaltplan+PCB nötig.** Nicht durch BOM-Tausch heilbar.

---

## F-02 · BLOCKER — R5 = 100 kΩ in VOS (TPS62163) · **FIXED (R5→0R)**

**Befund:** R5 zwischen `/5V` und `/VOS` (U1 Pin 6). TI: *„VOS pin should connect in the shortest way to VOUT at the output capacitor.“*

### 1. Warum Risiko?
VOS ist Regelkreis-Sense. 100 kΩ + Rauschen/kapazitive Kopplung → falsche Ausgangsspannung, Jitter, im Extrem IC-Stress. Datenblatt verlangt **kurze direkte** Verbindung, keinen 100 k-Vorwiderstand.

### 2. Wahrscheinlichkeit
**Hoch**, dass Regulation außerhalb Spec oder instabil (Layout+100 k).

### 3. Schaden
**Hoch** — 5 V falsch → Kübler/Modul außerhalb Fenster; Buck kann fehlverhalten.

### 4. Korrektur
R5 → **0 Ω** oder R5 entfernen und VOS direkt an C3/`5V` legen (kurze Trace). Vor Order patchen (Handlöten 0 Ω auf Proto möglich, besser Layout-Fix).

---

## F-03 · MAJOR — Kaltstart / BUSY-Race (Mode 0 Flanke) · **FIXED (R13+C4; Proto-Oszi empfohlen)**

### 1. Warum Risiko?
Latch weckt erst die 5 V-Schiene. Mode 0 braucht **fallende Flanke** an IOx *nachdem* das Modul lebt. Kurzer Tastendruck vor Boot-Ende (~150 ms + CON3-Fenster 30 ms) → kein Play. Danach BUSY=HIGH → Q3 → Latch aus → „tot beim ersten Druck“.  
Zusätzlich: sobald BUSY als Ausgang HIGH ist und noch kein Play läuft, killt Q3 die Versorgung.

### 2. Wahrscheinlichkeit
**Mittel–hoch** (abhängig Tastendauer / Modul-Firmware; in Feld oft reproduzierbar).

### 3. Schaden
**Hoch funktional** (wirkt „defekt“), selten Hardwareschaden.

### 4. Korrektur
BUSY-Release verzögern/qualifizieren (RC + Schmitt, oder Release erst nach BUSY Low→High *nach* Play); oder Level-Trigger-Mode; oder monostabile Verlängerung des IO-Lows über Boot; Prototyp **oszi** Pflicht vor Serie.

---

## F-04 · MAJOR — Keine Strombegrenzung Taster-LEDs (J6) · **FIXED (R12=10Ω; Messung im Betrieb)**

**Verifikation:** Strom am LED-Ring + R12-Temperatur bei Dauerplay messen (Ziel ~50–120 mA gesamt).

### 1. Warum Risiko?
J6 = Roh-`12V_SW` + GND. Annahme „6–24 V LEDs mit Vorwiderstand“ ist **feldabhängig**. Ohne interne R: LED-/Kabelkurzschluss → hoher Strom über Q1 (SI2301), Thermik, PTC erst spät.

### 2. Wahrscheinlichkeit
**Mittel** (hängt von verbauten Tastern).

### 3. Schaden
**Mittel–hoch** — LED kaputt, Q1/Leiterbahn stress, entladene Batterie.

### 4. Korrektur
Serienwiderstand oder Konstantstrom auf Platine; max. LED-Strom spezifizieren; Kurzschlussfestigkeit prüfen; Annahme in Lastenheft verbindlich machen.

---

## F-05 · MAJOR — SPK-Bahnen stellenweise nur 0,2 mm · **FIXED (Hauptpfad 0,8 mm)**

**PCB:** U2→Lautsprecher **0,8 mm**; kurze Stubs zu TP5/J2 **≥ 0,4 mm**.

### 1. Warum Risiko?
Class-D-Peaks ≫ Mittelstrom. 0,2 mm auf `SPK+` (PCB-Auswertung) → I²R, Spannungsabfall, lokal Hitze, EMI durch hohe dI/dt in schmalen Spuren.

### 2. Wahrscheinlichkeit
**Mittel** bei 4 Ω / hoher Lautstärke.

### 3. Schaden
**Mittel** — Verzerrung, Warmstellen, im Extrem Pad-Stress.

### 4. Korrektur
SPK± auf ≥0,5–0,8 mm (besser Kupferfläche); kurze Wege U2→J2.

---

## F-06 · MAJOR — ESD / lange Tasterleitungen ohne Schutz · **AKZEPTIERT (Einsatzkontext)**

**Disposition (03.08.2026):** Review ging von Meter-Kabeln im Wald aus. **Tatsächlicher Aufbau:** Tasterleitungen **max. 30 cm**, **im Schrank** — ESD/EFT-Risiko praktisch vernachlässigbar. D15–D22 schützen Modul vor 12-V-Domain. **Keine TVS an J3.**

### 1. Warum Risiko? (ursprünglich)
Wald/außen, Meter Kabel an IOx → ESD/EFT direkt an Modul-Pins (und Latch-OR). Keine TVS/RC an J3.

### 2. Wahrscheinlichkeit
**Mittel** über Lebensdauer.

### 3. Schaden
**Hoch** — sporadische Resets/Defekte.

### 4. Korrektur
Nach Domain-Trennung (F-01): TVS-Array oder ≥1 kΩ Serie + Clamp 5 V/GND je IO; ggf. Common-Mode-Ferrit am Kabelbund.

---

## F-07 · MAJOR — SI2301 VDS 20 V vs. SMAJ15A Clamp ~24 V · **AKZEPTIERT**

**Disposition (03.08.2026):** 12-V-Batteriebetrieb im Schrank, kein Jumpstart/Lichtmaschine. Transienten-Risiko **bewusst eingegangen**; PTC + TVS bleiben Erstlinie.

### 1. Warum Risiko?
TVS Vc ≈ 24,4 V @ IPP. Q5/Q1 absolut max VDS = 20 V. Bei hartem Transient kann FET vor/mit TVS über VDS gehen.

### 2. Wahrscheinlichkeit
**Niedrig–mittel** (ohne Lichtmaschine selten; Jumpstart/induktive Spikes möglich).

### 3. Schaden
**Hoch** — FET kurz → Folgeschäden.

### 4. Korrektur
40 V P-FET (z. B. höhere VDS-Familie) **oder** TVS mit niedrigerem Vc / SMAJ12A prüfen (vs. Ladespannung); Transienten-Test.

---

## F-08 · MODERAT — Power-Integrität 12V_SW / GND · **AKZEPTIERT**

**Disposition (03.08.2026):** Hauptlastpfad F1→Q1→12V_SW **0,5–0,7 mm**. U1 VIN: Pad-Stubs **0,2–0,3 mm** (WSON-Platzzwang, &lt;1 mm). Lange **0,2-mm-Stellen** nur am Latch-Zweig (R9/Q6), **kein Lastpfad**. Verifikation: 5 V stabil unter Volllast.

### 1. Warum Risiko?
`12V_SW` enthält 0,2 mm-Segmente; Buck-Inrush + LEDs. Nur 12 Vias; GND primär Zone — OK wenn Fill solide, aber Engstellen bleiben.

### 2. Wahrscheinlichkeit
**Mittel** bei LED-Last + Audio-Peak.

### 3. Schaden
**Mittel** — Browout, Reset, EMI.

### 4. Korrektur
Mindestbreite Power ≥0,5 mm durchgängig; Via-Stitching unter U1 CIN/COUT; Inrush auf Scope.

---

## F-09 · MODERAT — USB-Programmierung vs. Board-5 V · **AKZEPTIERT**

**Disposition (03.08.2026):** Modul auf **Sockel** — IBN-Regel: *USB nur zum Programmieren, Modul abgezogen oder Latch aus (kein 12V_SW)*.

### 1. Warum Risiko?
DY-SV17F USB speist Modul. Gleichzeitig Latch/Buck 5 V → zwei Quellen auf V5 möglich Backfeed in Buck-Ausgang.

### 2. Wahrscheinlichkeit
**Mittel** (wenn USB bei eingebautem Modul + Batterie).

### 3. Schaden
**Mittel** — Buck-Ausgang reverse, Modul-Oddities.

### 4. Korrektur
Programmierung nur Modul abgezogen (Sockel — gut) **oder** Schottky/Lastschalter; Arbeitsanweisung „USB nur ohne 12V_SW“.

---

## F-10 · MODERAT — Thermik Kübler dauernd an 5 V während Play

### 1. Warum Risiko?
Spule ~50 mW @4,5 V, hier 5 V für 10–20 s. Spec erlaubt Dauer — thermisch meist OK, aber Gehäuse/Sommer.

### 2. Wahrscheinlichkeit
**Niedrig** für Defekt; Komfort/Drift möglich.

### 3. Schaden
**Niedrig–mittel**.

### 4. Korrektur
Optional Impuls nur auf Power-Up-Edge; Temperaturrauchtest.

---

## F-11 · MODERAT — DFM/DFA Outdoor

### 1. Warum Risiko?
Viele **0402**, steckbares Modul, MPT-Schrauben, Vibration/Feuchte. Silk/Footprint-Warnung U2. Bestückungsreihenfolge THT nach Reflow.

### 2. Wahrscheinlichkeit
**Mittel** für Montage-/Feldprobleme.

### 3. Schaden
**Mittel** — Premature opens, Schraubklemm-Lockering.

### 4. Korrektur
Kritische R auf 0603; Conformal Coating; Schrauben sichern; U2-Lib sync; Montageanweisung.

---

## F-12 · MINOR — BOM / Prozess

| Punkt | Risiko |
|---|---|
| Q6/D13 ohne LCSC im KiCad-Feld | falsche Bestückung wenn nur Roh-BOM |
| `JLCPCB_BOM.csv` patched manuell | Drift zu Schaltplan |
| TPS62163 knapper Stock | Lieferverzögerung |
| Symbol Q teils „BSS84“ in Lib-Text | Verwechslung trotz Value SI2301 |

**Korrektur:** LCSC-Felder in Schaltplan pflegen; eine kanonische BOM; Q6=C10487, D13=C118873.

---

## F-13 · MINOR — Annahmen Datenblatt / Doku

| Annahme | Problem |
|---|---|
| „BTN_OR Idle kein Strom“ | durch **F-01-Fix** behoben (D15–D22) |
| E03 Real case | OK als Analyse; Worst case kommunizieren |
| Kübler 4,5 V @5 V | Spec-mäßig OK (E-CNT-01); Buck-Fehler >5,4 V tödlich → hängt an F-02 |
| LTspice übersprungen | kein Ersatz für F-01/F-02 |

---

## Was relativ robust wirkt (kurz)

- VGS-Zener Q5/Q1/Q6 + Serie-R (Konzept richtig, Polarität PCB plausibel)
- Verpolung Q5-Topologie üblich
- D13 Steering + R10 gegen Q3-Kampf (Verlust begrenzt)
- D10 Freilauf 5 V↔GND für Kübler sinnvoll
- PTC 24 V-Typ (nicht 6 V) richtig gewählt
- DRC 0 open nets

---

## Freigabe-Stand (03.08.2026)

1. ~~F-01…F-05 Respin~~ ✅  
2. ~~F-06…F-09 disposition~~ ✅ (akzeptiert / dokumentiert)  
3. **Proto:** F-03 Oszi optional; F-04 LED-Strom messen; F-08 5 V unter Last  
4. Gerber aus Working-PCB neu exportieren → M04 → Bestellung  
5. F-10…F-13: Moderate/Minor — bei Gelegenheit (DFM, BOM-LCSC, Kübler-Thermik)

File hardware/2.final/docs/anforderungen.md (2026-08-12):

# Lastenheft: Vogelstimmenkasten (Rev 2)

## 1. Projektbezeichnung

Neubau der Elektronik eines Vogelstimmenkastens für den Waldlehrpfad der Kolpingfamilie.

## 2. Ausgangssituation

Auf dem Waldlehrpfad befindet sich ein Vogelstimmenkasten, an dem Besucher per Knopfdruck verschiedene Vogelstimmen anhören können. Der vorhandene Kasten ist technisch veraltet und defekt. Das Gehäuse, die acht Taster und der Lautsprecher sind weiterhin verwendbar.

### Bestandskomponenten

| Komponente | Zustand | Weiterverwendung |
|---|---|---|
| Gehäuse (Holz/Metall) | intakt | ja |
| 8 Taster | intakt | ja, Einzelleitungen (je 2 Adern pro Taster) |
| 2 Lautsprecher (je ca. 2W) | zu prüfen | 1 Lautsprecher genügt, ggf. neuen kaufen |
| Verkabelung Taster | zu prüfen | ggf. neu verlegen |
| 12V Autobatterie (~30 Ah) | vorhanden | ja |

### Lessons Learned aus Rev 1

| # | Fehler in Rev 1 | Maßnahme Rev 2 |
|---|---|---|
| 1 | U4 (TPS62203) und U5 (SGM809) verbrannt — nur bis 6V spezifiziert, aber an 12V angeschlossen | Buck-Converter mit VIN bis 17V (TPS62160); UVLO per Spannungsteiler statt separatem IC |
| 2 | WT588D-16P als Standalone-Chip nicht beschaffbar, WT588DM02 (28-Pin) abgekündigt | DY-SV17F Modul: 8 IO-Trigger, USB Drag&Drop, 5W Amp eingebaut, überall verfügbar |
| 3 | U2 Footprint falsch (SOIC-8 208mil statt 150mil) | Footprint-Verifikation gegen Datenblatt vor Layout (M01) |
| 4 | Keine Montagelöcher auf der Platine | 4x M3 Montagelöcher vorsehen |
| 5 | Bauteilbeschaffbarkeit nicht vorab geprüft | Alle Bauteile bei LCSC/JLCPCB verifizieren vor Layout (M01) |

## 3. Projektziel

Entwicklung einer robusten, energieeffizienten Elektronik, die dauerhaft im Außenbereich betrieben werden kann und Besuchern zuverlässig verschiedene Vogelstimmen wiedergibt.

## 4. Funktionale Anforderungen

| ID | Anforderung | Priorität |
|----|---|---|
| F01 | 8 externe Taster anschließbar (Einzelleitungen, je 2 Adern) | Muss |
| F02 | Jeder Taster startet eine fest zugeordnete Vogelstimme | Muss |
| F03 | Wiedergabebeginn innerhalb 0,5 Sekunden nach Tastendruck | Muss |
| F04 | Jede Tonsequenz dauert ca. 10 Sekunden | Muss |
| F05 | Lautstärke: im Umkreis von 2–3 m gut wahrnehmbar (3W Class-D Verstärker) | Muss |
| F06 | Vogelstimmen austauschbar per USB (Drag & Drop, Modul wird als USB-Stick erkannt) | Muss |
| F07 | Tastendruck während Wiedergabe bricht aktuelle Stimme ab und startet neue | Muss |
| F08 | Keine gleichzeitige Wiedergabe mehrerer Stimmen | Muss |
| F09 | Ein einzelner Lautsprecher wird angesteuert (Mono) | Muss |
| F10 | Elektromechanischer Impulszähler (Printzähler auf PCB) zählt jede Wiedergabe-Session (Aufweck-Event) | Muss |
| F11 | Taster-LEDs (6–24V) leuchten während Wiedergabe — alle LEDs gemeinsam über Latch-12V gespeist | Wunsch |

## 5. Anforderungen an den Energieverbrauch

| ID | Anforderung | Priorität |
|----|---|---|
| E01 | Betrieb über 12V-Autobatterie (Bleiakku, ~30 Ah) | Muss |
| E02 | Ruhestrom unter 100 µA (Ziel ≈0 µA via Latch; siehe E-LATCH-01/02) | Muss |
| E03 | Batterielebensdauer mindestens 1 Jahr ohne Laden (Real case: 12 V-Autobatterie ~30 Ah; Analyse `traceability.md`) | Muss |
| E04 | Aufwachen aus Ruhezustand per Tastendruck (Latch-Schaltung schaltet Modul ein) | Muss |
| E05 | Automatischer Übergang in Ruhezustand nach Wiedergabe-Ende (BUSY-Pin steuert Latch-Abschaltung) | Muss |
| E06 | Audio-Verstärker ist im Modul integriert (DY-SV17F, 5W Class-D) — kein separater PAM8403 nötig | Muss |

## 6. Einsatzbedingungen

| ID | Anforderung | Priorität |
|----|---|---|
| U01 | Betriebstemperatur: -10 °C bis +60 °C | Muss |
| U02 | Hohe Luftfeuchtigkeit / Kondenswasser tolerieren | Muss |
| U03 | Wartungsfreier Betrieb über mindestens 1 Jahr | Muss |
| U04 | Keine beweglichen Teile (keine SD-Karte im Normalbetrieb) | Muss |
| U05 | Keine externe Netzversorgung erforderlich | Muss |

## 7. Hardware-Anforderungen

| ID | Anforderung | Priorität |
|----|---|---|
| H01 | Elektromechanischer Impulszähler (Printzähler, 5V DC, 7-stellig, von vorne ablesbar) direkt auf der Platine montiert | Muss |
| H02 | Alle SMD-Bauteile werden vom Platinen-Lieferanten (JLCPCB) bestückt — kein manuelles SMD-Löten | Muss |
| H03 | Manuell bestückt werden nur: THT-Schraubklemmen (MPT), DY-SV17F-Modul, Printzähler | Muss |
| H04 | 4x M3 Montagelöcher in den Ecken der Platine | Muss |
| H05 | Testpunkte für: 12V (geschützt), 5V, GND, BUSY, Audio | Soll |
| H06 | Zähler von oben ablesbar (K07.90, Anzeige oben; Sichtfenster im Gehäuse) | Muss |
| H07 | Gate-Source-Schutz der P-FETs Q5/Q1: Zener 6,2 V (BZX84C6V2) + Serie-Widerstand, weil SI2301 VGS max ±8 V | Muss |

## 8. Methodik-Anforderungen (Prozess)

| ID | Anforderung | Priorität |
|----|---|---|
| M01 | Bauteilbeschaffbarkeit (LCSC-Verfügbarkeit, korrekter Footprint, JLCPCB DFM-Prüfung) muss VOR dem PCB-Layout vollständig verifiziert und dokumentiert sein | Muss |
| M02 | Jeder IC muss vor Schaltplan-Abschluss eine dokumentierte Spannungsprüfung haben (anliegende Spannung vs. Datenblatt-Maximum) | Muss |
| M03 | LTspice-Simulation der Stromversorgung vor Fertigung | Muss |
| M04 | Review-Checkliste muss vor Bestellung vollständig abgearbeitet sein | Muss |

## 9. Schnittstellen

| Schnittstelle | Beschreibung | Steckverbinder |
|---|---|---|
| Taster (8×) | Einzelleitungen (2 Adern pro Taster), Schließer gegen GND | 2× 8-pol Schraubklemme Phoenix MPT 0,5/8-2,54 (J3/J4) |
| Lautsprecher (1×) | Mono, ca. 2–3 W, 4–8 Ω, BTL-Ausgang | 2-pol Schraubklemme MPT 0,5/2-2,54 (J2) |
| Stromversorgung | 12V Autobatterie (Bleiakku), verpolungsgeschützt | 2-pol Schraubklemme MPT 0,5/2-2,54 (J1) |
| Taster-LEDs | parallel an **12V_LED** (via **R12 10 Ω** von 12V_SW) | 2-pol Schraubklemme MPT 0,5/2-2,54 (J6) |
| Impulszähler | 5V DC Printzähler, direkt auf PCB gelötet | Lötstifte (integriert) |
| Audio-Upload | USB Micro am DY-SV17F — Drag & Drop wie USB-Stick (kein Programmer nötig) | Micro-USB-Buchse am Modul |

## 10. Qualitätsanforderungen

- Alle Bauteile für Temperaturbereich -10 °C bis +60 °C spezifiziert
- Leiterplatte mit Schutzlackierung (Conformal Coating) empfohlen
- TVS-Diode (SMAJ15A) am Batterie-Eingang als Überspannungsschutz
- Verpolungsschutz an der Batterie-Eingangsklemme (P-MOSFET SI2301 **mit VGS-Zener D11**)
- Latch-Leistungsschalter Q1 ebenfalls mit VGS-Zener D12
- Tiefentladeschutz: bewusst entfallen (0 µA-Standby; internes UVLO des Buck reicht als Notfall)

## 11. Abnahmekriterien

1. Alle 8 Taster lösen korrekt die zugeordnete Vogelstimme aus
2. Wiedergabe startet innerhalb 500 ms nach Tastendruck
3. Ruhestrom unter 100 µA (gemessen an der Batterie)
4. Wiedergabelautstärke in 2 m Abstand gut wahrnehmbar
5. Funktion bei -10 °C und +60 °C nachgewiesen
6. 1000 Betätigungszyklen ohne Fehler
7. Tastendruck während Wiedergabe wechselt korrekt zur neuen Stimme
8. Impulszähler auf PCB zählt bei jedem Tastendruck zuverlässig hoch

## 12. Offene Punkte (zu prüfen vor Hardware-Design)

| # | Offener Punkt | Auswirkung auf Design |
|---|---|---|
| O1 | Impedanz der vorhandenen Lautsprecher messen (4 Ω oder 8 Ω?) | Verstärker-Dimensionierung, ggf. neuen Lautsprecher kaufen |
| O2 | Verfügbarer Einbauraum im Gehäuse ausmessen (L × B × H) | Maximale Platinengröße |
| O3 | Batterietyp identifizieren (Nass/Gel/AGM?) und Kapazität ablesen | Spannungsbereich |
| O4 | Gehäuse-Dichtigkeit beurteilen: dringt Feuchtigkeit ein? | Notwendigkeit von Conformal Coating / Verguss |
| O5 | Kabellänge von Tastern zur Platine messen | Entprellung |
| O6 | Vorhandene Befestigungspunkte / Montagelöcher im Gehäuse | Platinenform und Befestigung |
| O7 | Position für Zähler-Sichtfenster im Gehäuse klären | PCB-Ausrichtung |

## 13. Projektfortschritt (Stand 01.08.2026)

| Meilenstein | Status |
|---|---|
| Lastenheft Rev 2 (dieses Dokument) | **erledigt** |
| Systemarchitektur (BDD/IBD) | **erledigt** (`docs/systemarchitektur.md`) |
| Bauteilbeschaffbarkeit verifizieren (M01) | **erledigt** (`bom_verfuegbarkeit.md`) |
| Schaltplan KiCad Rev 2 (ERC 0 Fehler) | **erledigt** (1 Warnung SET_DRV optional) |
| PCB Rev 2.4 Routing / DRC 0 Fehler | **erledigt** (1 Footprint-Warnung U2) |
| HTML-Platinen-Simulation | **erledigt** (`simulation/`) |
| LTspice-Simulation Stromversorgung (M03) | optional — Reviewer entscheidet (G4 in M04) |
| Review-Checkliste (M04) | **Vorlage bereit** — Signatur ausstehend (`review_checkliste_m04.md`) |
| JLCPCB-Bestellung | nach M04-Freigabe |
| DY-SV17F bestücken & Audio laden | ausstehend |

Details: [zwischenstand.md](zwischenstand.md) · Traceability: [traceability.md](traceability.md)

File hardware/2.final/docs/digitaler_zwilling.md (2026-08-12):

# Digitaler Zwilling — Vogelstimmenkasten Rev 2

**Stand:** 3. August 2026  
**Ebenen:** System → Block (B1–B8) → Bauteil  
**PCB:** `hardware/vogelstimmen_v2.4.kicad_pcb` (Respin F-01…F-05)

---

## 1. Systemebene

```mermaid
graph LR
    BAT[12V Batterie] --> B1
    B1 -->|12V_PROT| B2
    B2 -->|12V_SW| B3
    B2 -->|12V_SW| B8
    B3 -->|5V| B4
    B3 -->|5V| B5
    BTN[8 Taster] --> B6
    B6 -->|IOx| B4
    B6 -->|IOx via D1-D8| B2
    B4 -->|IOx_M| B4
    B4 -->|BUSY| B2
    B4 --> B7
    B7 --> SPK[Lautsprecher]
    B8 --> LED[Taster-LEDs via R12]
    B5 --> ANZ[Zähleranzeige]
```

| Rail | Wann aktiv | Verbraucher |
|---|---|---|
| BAT+ | immer (Batterie) | nur Q5 |
| 12V_PROT | bei richtiger Polung | Latch-Logik, TVS, C1 |
| 12V_SW | nur Latch AN | Buck, R4 |
| **12V_LED** | nur Latch AN | R12 → J6 → 8× Taster-LEDs |
| 5V | nur Latch AN | DY-SV17F, K07.90, D10 |
| GND | immer | alles |

**Ruhestrom Ziel:** Latch AUS → ≈0 µA (E-LATCH-01/02). Kein dauerhafter Widerstand 12 V→GND; Zeners nur Leckage.

---

## 2. Blockebene (Kurz)

| Block | Aufgabe | Kritische Bauteile |
|---|---|---|
| B1 | Verpolung, Überstrom, Transient | Q5, D11, R6, R7, F1, D9, C1 |
| B2 | Ein/Aus, Hold, Release | Q1, D12, R1, R8, Q2, Q3, **R13, C4**, D1–D8, R2–R4 |
| B3 | 12V→5V | U1, L1, C2, C3, **R5=0R** |
| B4 | Audio | U2 DY-SV17F, **D15–D22** |
| B5 | Zählen | J5 K07.90, D10 |
| B6 | Taster | J3, J4 |
| B7 | Lautsprecher | J2 |
| B8 | LEDs | J6, **R12** |

---

## 3. Bauteilebene (einzeln)

### B1 — Eingangsschutz

#### Q5 — SI2301CDS (P-MOSFET)
| | |
|--|--|
| **Ref** | Q5 |
| **Funktion** | Verpolungsschutz High-Side |
| **VDS** | 20 V max — 12 V Betrieb OK |
| **VGS** | ±8 V max — **ohne Clamp unzulässig** (Gate→GND wäre −12 V) |
| **LCSC** | C10487 |
| **Paket** | SOT-23 |

#### D11 — BZX84C6V2 (Zener 6,2 V)
| | |
|--|--|
| **Ref** | D11 |
| **Funktion** | VGS-Clamp an Q5: begrenzt \|VGS\| auf ~6,2 V |
| **Polarität** | **Kathode → Q5.Source (BAT+)**, **Anode → Q5.Gate** |
| **LCSC** | C179522 (Suzhou Good-Ark), Bestand >1000, ~$0,03 |
| **JLCPCB** | auch C2832549 / C5155258 u. a. |
| **Paket** | SOT-23 |
| **Bestellbar** | **ja** |

#### R7 — 4,7 kΩ (Serie Gate Q5)
| | |
|--|--|
| **Ref** | R7 |
| **Funktion** | Strombegrenzung für D11 beim Einschalten (~1 mA) |
| **Lage** | zwischen Q5.Gate und R6 (R6 weiter nach GND) |
| **Paket** | 0402 |

#### R6 — 470 kΩ
| | |
|--|--|
| **Ref** | R6 |
| **Funktion** | Gate nach GND (Q5 einschalten bei korrekter Polung); Idle ≈12 µA |
| **Paket** | 0402 |

#### F1 — PTC 1 A / 24 V
| | |
|--|--|
| **Ref** | F1 |
| **LCSC** | C2760272 |
| **Hinweis** | Nicht C20800 (nur 6 V)! |

#### D9 — SMAJ15A (TVS)
| | |
|--|--|
| **Ref** | D9 |
| **Funktion** | Klemmt Spitzen auf ~24 V |
| **LCSC** | C113958 |
| **Hinweis** | Uni-TVS; Kathode an 12V_PROT |

#### C1 — 10 µF / 25 V
Puffer an 12V_PROT.

---

### B2 — Latch

#### Q1 — SI2301CDS
| | |
|--|--|
| **Ref** | Q1 |
| **Funktion** | Leistungsschalter 12V_PROT → 12V_SW |
| **VGS** | wie Q5 — **Clamp D12 Pflicht** |
| **LCSC** | C10487 |

#### D12 — BZX84C6V2
| | |
|--|--|
| **Ref** | D12 |
| **Funktion** | VGS-Clamp an Q1 |
| **Polarität** | **Kathode → Q1.Source (12V_PROT)**, **Anode → Q1.Gate** |
| **LCSC** | C179522 |
| **Bestellbar** | **ja** |

#### R8 — 4,7 kΩ
| | |
|--|--|
| **Ref** | R8 |
| **Funktion** | Serie zwischen Q2.Drain und Q1.Gate (Zenerstrom begrenzen) |
| **Paket** | 0402 |

#### R1 — 100 kΩ
Pull-up Q1.Gate → 12V_PROT (Default AUS).

#### Q2 — 2N7002
SET/Hold-Logik; Gate = LATCH_SET.

#### Q3 — 2N7002
BUSY (über **R13 100 kΩ + C4 4,7 µF** an **Q3_GATE**) HIGH → Latch lösen. RC-Blanking ~470 ms (F-03).

#### R13 / C4 — BUSY-Blanking (Respin F-03)
| | |
|--|--|
| **R13** | 100 kΩ: BUSY → Q3_GATE |
| **C4** | 4,7 µF/16 V: Q3_GATE → GND |
| **Zweck** | Q3-Gate-Anstieg verzögern (Kaltstart/BUSY-Race) |

#### R2, R3, R4
100k Pull-down Q2, 10k BUSY, 10k Selbsthaltung.

#### D1–D8 — 1N4148WS
Latch-OR: **K = IOx** (Kabel/J3), **A = BTN_OR**.

#### D15–D22 — 1N4148WS (Respin F-01)
Modul-Schutz: **A = IOx_M** (U2), **K = IOx** (Kabel). Blockiert 12-V-Rückspeisung ins Modul.

#### Q6 / R9–R11 / D13–D14 — Kaltstart (v2.4, ≈0 µA)
- R9: 12V_PROT → BTN_OR (10 kΩ); Idle: BTN_OR≈12 V, **kein Strom**
- Q6 SI2301 (P): Idle VGS=0 → **aus**; Taster → ein → SET
- R11 + D14: Gate-Serie + VGS-Clamp (wie Q1/Q5)
- R10 1 kΩ + D13: SET nur HIGH; begrenzt Konflikt mit Q3-Release
- Q3.Drain an **LATCH_SET** — Details: `docs/entscheidungen.md` E-LATCH-02

---

### B3 — Buck

| Ref | Bauteil | Rolle |
|-----|---|---|
| U1 | TPS62163DSGR | 12V_SW → 5 V fest, EN=12V_SW |
| L1 | 2,2 µH | SW → 5 V |
| C2 | 10 µF/25 V | VIN |
| C3 | 22 µF/10 V | VOUT |
| R5 | **0 Ω** | VOS → 5 V direkt (TI, F-02) |
| **C4** | **4,7 µF/16 V** | Q3_GATE → GND (F-03) |
| **R13** | **100 kΩ** | BUSY → Q3_GATE (F-03) |

---

### B4 — Audio

| Ref | Bauteil | Rolle |
|-----|---|---|
| U2 | DY-SV17F | Wiedergabe, BUSY, **IOx_M**, SPK |
| **D15–D22** | 1N4148WS | Serie IOx_M ↔ IOx |
| | 5 V an Pin 13 | nur bei Latch AN |
| | Strom @5 V | Idle **14 mA** (Messung); Betrieb **≤60 mA** (Spec); SPK extra; V33 max 80 mA |

---

### B5 — Zähler

| Ref | Bauteil | Rolle |
|-----|---|---|
| J5 | Kübler K07.90 | Anzeige oben, Spule an 5 V |
| D10 | 1N4148WS | Freilauf (K→5 V, A→GND) |

---

### B6–B8 — Schnittstellen

| Ref | Funktion |
|-----|---|
| J1 | Batterie |
| J2 | Lautsprecher BTL |
| J3 / J4 | Taster IO / GND (MPT 0,5/8) |
| J1 / J2 / J6 | BAT / SPK / LED (MPT 0,5/2) |
| J6 | LED **12V_LED** via **R12 10 Ω** |
| TP1–TP5 | 12V_PROT, 5V, GND, BUSY, SPK+ |

---

## 4. VGS-Schutz — Warum Zeners

```
Source = 12V ●── P-FET ── Drain
             │
           Gate ── R_serie ──→ Pull-down nach GND
             │
           Zener 6,2V (K an Source, A an Gate)

Ohne Zener: VGS = −12 V  >  |8 V| Limit SI2301
Mit Zener:  VGS ≈ −6,2 V  → sicher
```

Lastspannungen bleiben **12 V / 5 V** — die Zeners begrenzen nur die Gate-Ansteuerung.

---

## 5. Traceability (neu)

| ID | Aussage | Bauteile |
|----|---|---|
| H07 | VGS-Schutz P-FETs | D11, D12, R7, R8 |
| SF-10 | Eingangsschutz | Q5, D11, R6, R7, F1, D9, C1 |
| SF-02 | Einschalten | Q1, D12, R1, R8, Q2, … |

---

## 6. Offene Punkte

1. ~~PCB v2.4 routen → DRC = 0~~ ✅
2. ~~Respin F-01…F-05~~ ✅ (02.08.2026; DRC/ERC/Parität OK)
3. ~~F-06…F-09 Restrisiko~~ ✅ dispositioniert (03.08.2026)
4. Proto optional: F-03 Oszi; F-04 LED-Strom; F-08 5 V unter Last
5. Gerber/`2.final/` **neu exportieren** aus Working-PCB
6. M04 Review → Bestellung

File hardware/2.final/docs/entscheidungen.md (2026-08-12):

# Designentscheidungen — Vogelstimmenkasten Rev 2

Versionierte Architektur- und Schaltungsentscheidungen. Ältere Einträge bleiben stehen (Historie).

---

## E-LATCH-01 — Hardware-Latch für ≈0 µA Ruhestrom (unverändert gültig)

**Datum:** Rev‑2 Architektur  
**Status:** gültig  

**Kontext:** Batteriebetrieb (Bleiakku), lange Standzeiten, Anforderung E02 (&lt; 100 µA, Ziel ≈0 µA).

**Entscheidung:** Komplette Abschaltung von Buck + DY-SV17F über P-FET-Latch (Q1), der nur bei Tastendruck einschaltet und über BUSY wieder ausfällt. Kein MCU-Sleep, kein Quiescent des Audio-Moduls im Idle.

**Konsequenz:** Im Idle liegt nur `12V_PROT` an (Schutz/TVS/C). `12V_SW` / `5V` sind tot → Ruhestrom ≈ Leckage.

---

## E-LATCH-02 — Kaltstart-SET mit P-FET (v2.4), nicht N-FET-Inverter

**Datum:** 31.07.2026  
**Status:** gültig (ab PCB **v2.4** / Doku Rev 2.4)  
**Ersetzt:** Kurzzeitige v2.3-Lösung mit Q4+R10 (verworfen)

### Problem

- DY-SV17F Mode 0: Taster **Active-Low** (IOx → GND).
- Alter Dioden-OR (Anode=IOx → LATCH_SET) braucht IO=HIGH → **setzt im Kaltstart nicht**.
- Zusätzlich hing Q3.Drain fälschlich an `LATCH_GATE` → Release über BUSY wirkte nicht zuverlässig.

### Verworfene Variante (v2.3 kurz)

Active-Low-OR → N-FET-Inverter Q4 + Pull-up **R10 = 47 kΩ** nach GND am Drain.

| | |
|--|--|
| Vorteil | Kaltstart funktioniert |
| Nachteil | Im Idle leitet Q4 dauernd → **I ≈ 12 V/47 kΩ ≈ 255 µA** |
| Verstoß | Gegen **E-LATCH-01** und E02 (&lt; 100 µA) |

### Gewählte Variante (v2.4)

```
Taster→GND → D1–D8 (K=IOx, A=BTN_OR) → R9 Pull-up an 12V_PROT
BTN_OR → R11 → Q6_GATE
Q6 = SI2301 (P): Source=12V_PROT, Drain→R10(1k)→D13→LATCH_SET
D14 = BZX84C6V2 VGS-Clamp an Q6
Q3.Drain = LATCH_SET (Release)
R4 = Hold von 12V_SW
```

| Zustand | Verhalten | Ruhestrom |
|---|---|---|
| Idle, kein Taster | BTN_OR≈12 V → VGS(Q6)=0 → Q6 **aus** | **≈0 µA** (+Leckage) |
| Taster | BTN_OR low → Q6 **ein** → LATCH_SET high | kurzzeitig |
| Wiedergabe | R4 hält; Q6 ggf. noch „ein“ unkritisch | aktiv |
| Ende (BUSY HIGH) | Q3 zieht LATCH_SET auf GND; R10 begrenzt Konfliktstrom | → Idle |

**Warum P-FET statt Inverter:** Im Ruhezustand darf **kein Widerstand dauerhaft 12 V nach GND** verbinden. Ein P-FET mit Gate=12 V ist einfach aus.

**PCB:** `vogelstimmen_v2.4.kicad_pcb`  
**Siehe:** `docs/pcb_v2.4.md`, `docs/schaltplan.md` B2, `docs/digitaler_zwilling.md`

---

## E-RPP-01 — R6 = 470 kΩ für Idle &lt; 100 µA

**Datum:** 31.07.2026  
**Status:** gültig  

**Problem:** R6 = 10 kΩ am Verpolungs-Gate (Q5) zog ~580 µA Dauerstrom → E02 verletzt, obwohl Latch ≈0 µA.

**Entscheidung:** R6 = **470 kΩ** → Idle ≈ **12 µA** (+ Leckage). Latch unverändert.

**Trade-off:** Q5 schaltet beim Batterieanschluss etwas träger — irrelevant.

---

## E-VGS-01 — Zener-Clamp an SI2301 (Q5, Q1, Q6)

**Status:** gültig  

BZX84C6V2 (6,2 V) + Serie 4,7 kΩ, LCSC **C179522**.  
K=Source, A=Gate. Ohne Clamp wäre \|VGS\|≈12 V &gt; Limit.

---

## E-CNT-01 — Kübler K07.90 Bestellnummer

**Status:** gültig  

| | |
|--|--|
| Typ | K07.90 liegend, Anzeige oben |
| Bestellnr. | **1.130.900.008** (4,5 V DC / 10 Hz, Typ 0) an 5 V-Rail |
| Alternative | 1.130.900.012 (12 V) an 12V_SW |

### Datenblatt — Spannungstoleranz (Typ 0 / 10 Hz)

Kübler K04–K07: **Rated voltage type 0: −10 % / +20 %** der Nennspannung.

| | |
|--|--|
| Nenn | 4,5 V |
| Erlaubt | **4,05 V … 5,4 V** (4,5 × 0,9 … 4,5 × 1,2) |
| Unsere Rail | **5,0 V** fest (TPS62163) → **+11 %** → **innerhalb +20 %** |

Zusätzlich: **Cycle duration factor 100 %** (Dauerbetrieb der Spule bei Nennspannung erlaubt).  
Im Betrieb liegt 5 V nur während Latch AN (~10–20 s pro Play) an — thermisch unkritisch; ohnehin Spec-konform.

**Gefahr bei 5 V?** Keine Spec-Überschreitung. Risiko wäre erst &gt; 5,4 V (Buck-Fehler) oder dauerhaft stark erhöhte Verlustleistung — beides hier nicht gegeben.  
Optional robuster: 12 V-Typ an 12V_SW.

---

## E-CONN-01 — Phoenix MPT-0,5 Schraubklemmen statt Stiftleisten

**Datum:** 01.08.2026  
**Status:** gültig  

**Kontext:** Taster mit Einzelleitungen (2 Adern), Feldverkabelung ohne Crimpgehäuse.

**Entscheidung:** Leiterplatten-Schraubklemmen Phoenix **MPT 0,5** (Raster 2,54 mm, max. 0,5 mm², 6 A / 160 V).

| Stecker | Polzahl | Artikel (Beispiel) | Footprint (KiCad) |
|---|---|---|---|
| J3 (IO), J4 (GND) | 8-pol | **1725711** MPT 0,5/8-2,54 | `TerminalBlock_Phoenix_MPT-0,5-8-2.54_…` |
| J1 Batterie | 2-pol | MPT 0,5/2-2,54 | `…MPT-0,5-2-2.54_…` |
| J2 Lautsprecher | 2-pol | MPT 0,5/2-2,54 | dito |
| J6 Taster-LEDs | 2-pol | MPT 0,5/2-2,54 | dito |

**Hinweis:** „0,5“ = Aderquerschnitt, nicht Pitch. Routing nach Footprint-Wechsel manuell.

---

## E-RESPIN-01 — Adversarial-Review-Fixes F-01…F-05 (02.08.2026)

**Status:** gültig (Working-PCB + Schaltplan Rev 2.4r)

| ID | Änderung | Bauteile / Netze |
|----|---|---|
| F-01 | 12-V-Domain von DY-SV17F-IOs trennen | **D15–D22**: A=IOx_M (U2), K=IOx (J3); D1–D8 bleiben für Latch-OR |
| F-02 | TPS62163 VOS direkt | **R5 → 0 Ω** (5V↔VOS) |
| F-03 | BUSY/Kaltstart-Blanking | **R13 100 kΩ** BUSY→**Q3_GATE**; **C4 4,7 µF** Q3_GATE→GND |
| F-04 | LED-Strombegrenzung | **R12 10 Ω**; Netz **12V_LED** → J6 |
| F-05 | SPK-Leiterbahnen | Hauptpfad **0,8 mm**; Stubs ≥ **0,4 mm** |

**Konsequenz:** Modul-IOs nur über Serie-Diode an Feld-IOx; Latch-SET weiter über D1–D8/BTN_OR. F-03 Oszi am Proto **empfohlen**, nicht blockierend.

**Referenz:** `docs/adversarial_review_v24.md`, `hardware/apply_f01_f05.py`

---

## E-RESPIN-02 — Restrisiko F-06…F-09 (03.08.2026)

**Status:** gültig — **bewusst akzeptiert**, keine PCB-Änderung

| ID | Disposition |
|----|---|
| **F-06** | Tasterleitungen **≤ 30 cm im Schrank** — kein praktisches ESD-Risiko im Feld |
| **F-07** | SI2301 VDS 20 V vs. SMAJ15A ~24 V — Batteriebetrieb, kein Jumpstart |
| **F-08** | Hauptpfad 12V 0,5–0,7 mm ausreichend; 0,2 mm nur Pad-Stubs / Latch-Zweig |
| **F-09** | IBN-Regel: USB nur bei **abgezogenem Modul** oder **Latch aus** |

**Referenz:** `docs/adversarial_review_v24.md` Dispositionstabelle

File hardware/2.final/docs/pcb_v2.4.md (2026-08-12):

# KiCad PCB Rev 2.4 — Latch Kaltstart ≈0 µA

**Projekt:** `hardware/vogelstimmen_v2.4.kicad_pro`  
**Schaltplan:** `hardware/vogelstimmen_v2.4.kicad_sch`  
**PCB:** `hardware/vogelstimmen_v2.4.kicad_pcb`  
**Basis:** `vogelstimmen_v2.3.kicad_pcb`  
**Designentscheidung:** `docs/entscheidungen.md` → E-LATCH-02  
**Stand:** 3. August 2026 — Respin F-01…F-05 im Working-PCB; `2.final/` noch Pre-Respin

## Respin F-01…F-05 (02.08.2026)

| Ref | Wert | Funktion |
|-----|---|---|
| **D15–D22** | 1N4148WS | Serie U2 IOx_M ↔ IOx (F-01) |
| **R5** | **0 Ω** | VOS direkt an 5 V (F-02) |
| **R13** | 100 kΩ | BUSY → Q3_GATE (F-03) |
| **C4** | 4,7 µF/16 V | Q3_GATE → GND (F-03) |
| **R12** | 10 Ω | 12V_SW → 12V_LED → J6 (F-04) |
| — | SPK ≥ 0,4 mm | Leiterbahnbreite (F-05) |

### Netze (neu/geändert)

```
IOx_M: U2 Pin 1–8 ← D15–D22 Anode
IOx:   J3 ← D15–D22 Kathode; D1–D8 Kathode; BTN_OR über D1–D8
Q3_GATE: Q3.G ← R13 ← BUSY; C4 nach GND
12V_LED: R12 → J6.1; 12V_SW → R12
VOS: R5 (0R) zwischen 5V und U1.VOS
```

## Änderung gegenüber v2.3

| Weg | v2.3 (verworfen) | v2.4 |
|-----|---|---|
| Kaltstart | Q4 N-FET-Inverter + R10 47 kΩ nach GND | **Q6 P-FET** von 12V_PROT |
| Ruhestrom | ~255 µA dauernd durch R10 | **≈0 µA** (P-FET aus, kein Lastwiderstand) |

## Neue / geänderte Bauteile

| Ref | Wert | Funktion |
|-----|---|---|
| Q6 | SI2301 | P-FET SET: Source=12V_PROT, Gate über R11, Drain→R10 |
| R11 | 4,7 kΩ | Serie Gate Q6 |
| D14 | BZX84C6V2 | VGS-Clamp Q6 (K=Source, A=Gate) |
| R10 | 1 kΩ | Serie SET_DRV→SET_PULSE (begrenzt Kurzschluss vs. Q3) |
| D13 | 1N4148WS | Steering SET_PULSE→LATCH_SET |
| R9 | 10 kΩ | Pull-up BTN_OR an 12V_PROT |
| — | Q4 entfernt | war 2N7002-Inverter |

## Netze

```
IOx --button-- GND
D1–D8: K=IOx, A=BTN_OR
R9: 12V_PROT → BTN_OR
R11: BTN_OR → Q6_GATE
D14: K=12V_PROT, A=Q6_GATE
Q6: S=12V_PROT, G=Q6_GATE, D=SET_DRV
R10: SET_DRV → SET_PULSE
D13: A=SET_PULSE, K=LATCH_SET
Q3: G=**Q3_GATE** (R13/C4), S=GND, D=LATCH_SET (Release bei BUSY HIGH)
```

## Layout-Feinschliff (01.08.2026)

Bauteile/Bahnen leicht verschoben (keine BOM-/Netzänderung):

| Ref | Anpassung |
|-----|---|
| Q6, R9, R10, R11, D14 | Cluster ~0,5 mm / +1,5 mm |
| C3, R5, D10 | 5 V-Bereich / Freilauf neu ausgerichtet |
| TP2, TP3 | 5 V / GND Testpunkte nachgezogen |

## Steckverbinder → MPT-Schraubklemmen (E-CONN-01)

| Ref | Alt | Neu (Footprint) |
|-----|-----|---|
| J1, J2, J6 | PinHeader 1×02 | `TerminalBlock_Phoenix_MPT-0,5-2-2.54_1x02_…` |
| J3, J4 | PinHeader 1×08 | `TerminalBlock_Phoenix_MPT-0,5-8-2.54_1x08_…` |

Pad-1-Position und Netze beibehalten (Körper größer als Stiftleiste).  
Script: `hardware/replace_connectors_mpt.py`

### Kabelrichtung (Drahtöffnung)

| Ref | Rotation | Kabeleinführung |
|-----|---|---|
| J1, J2, J4, J6 | 0° | von **unten** (Platinenrand +Y) |
| **J3** | **180°** | von **oben** (weg von U2); Netze IO0…IO7 an gleicher XY-Position; Pinnummern im Schaltplan gespiegelt |

Script: `hardware/orient_mpt_j3.py`

Simulation: `simulation/pcb_layout.json` / `pcb_tracks.json`.  
DRC: **0 Fehler / 0 unverbunden** (Respin); Warnungen: U2 lib_mismatch, Silkscreen.

## Fertigungspaket

`hardware/2.final/` — **noch Pre-Respin**; vor Bestellung Gerber/BOM/PDF aus aktuellem Working-PCB neu exportieren.

## Silkscreen-Titel (über Kübler J5)

Drei Zeilen auf **F.SilkS**, zentriert oberhalb J5:

```
Soundplatine Waldlehrpfad
Kolping Alteglofsheim
Konrad Senn 2026
```

Script: `hardware/add_silk_title.py`

## Öffnen / Export

1. Projekt öffnen → `vogelstimmen_v2.4.kicad_pro` (Schaltplan + PCB)
2. Nach Layout-Änderungen Simulation aktualisieren:
   - `python simulation/tools/export_layout.py` (KiCad-Python)
   - `python simulation/tools/export_tracks.py`

## Script

`hardware/make_v24_latch_pfet.py` (initialer Q6-Cluster)

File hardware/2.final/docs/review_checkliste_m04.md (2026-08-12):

# M04 — Review-Checkliste vor Bestellung

**Anforderung:** M04 (`anforderungen.md`)  
**Bezug:** D10 in `traceability.md`  
**Stand Vorlage:** 1. August 2026 · Rev **2.4**  
**Fertigungsdaten:** `hardware/2.final/`

> Reviewer: Kästchen abhaken. Offene Punkte in die Spalte „Notiz“. Am Ende Signatur.  
> **Adversarial Review:** F-01…F-09 geschlossen (03.08.2026) — Respin F-01…F-05 + F-06…F-09 dispositioniert; siehe [`adversarial_review_v24.md`](adversarial_review_v24.md). Vor FREIGABE: Gerber neu exportieren; Proto optional (F-03/F-04/F-08).

---

## A · Dokumente & Scope

| # | Prüfpunkt | OK | Notiz |
|---|---|:--:|---|
| A1 | Lastenheft Rev 2 gelesen (`anforderungen.md`) | ☐ | |
| A2 | Designentscheidungen E-LATCH-01/02, E-RPP-01, E-VGS-01, E-CNT-01, E-CONN-01 akzeptiert | ☐ | |
| A3 | Traceability Phase-1 (D01–D09) nachvollziehbar | ☐ | |
| A4 | Reviewer-Handoff (`reviewer_handoff.md`) als Einstieg genutzt | ☐ | |

## B · Architektur & Sicherheit

| # | Prüfpunkt | OK | Notiz |
|---|---|:--:|---|
| B1 | Idle: Latch aus, Buck/Modul tot; Idle-Pfad ~R6 ≈12 µA &lt; 100 µA (E02) | ☐ | |
| B2 | Kaltstart: Active-Low → BTN_OR → **Q6 P-FET** → SET (nicht N-Inverter) | ☐ | |
| B3 | Release: BUSY → Q3 zieht LATCH_SET; R10 begrenzt Konflikt vs. Q6 | ☐ | |
| B4 | VGS-Clamp BZX84C6V2 an Q5, Q1, Q6 + 4,7 kΩ Serie (H07 / E-VGS-01) | ☐ | |
| B5 | Verpolung Q5 + TVS SMAJ15A + PTC **24 V**-Typ (nicht 6 V) | ☐ | |
| B6 | Kübler `1.130.900.008` an 5 V: Datenblatt −10/+20 % → bis 5,4 V OK (E-CNT-01) | ☐ | |
| B7 | E03 Real-case-Analyse ≥1 Jahr nachvollzogen; Worst-case-Sensitivität bekannt | ☐ | |

## C · Schaltplan / PCB

| # | Prüfpunkt | OK | Notiz |
|---|---|:--:|---|
| C1 | KiCad-Projekt `vogelstimmen_v2.4.kicad_pro` öffnet Schaltplan + PCB | ☐ | |
| C2 | ERC: 0 Fehler; Warnung `SET_DRV` bewertet (akzeptiert / nachziehen) | ☐ | |
| C3 | DRC: 0 unverbunden; U2 Footprint-Warnung bewertet | ☐ | |
| C4 | MPT-Klemmen: J3 180° (Kabel oben), übrige von unten — sinnvoll | ☐ | |
| C5 | DY-SV17F USB / Kübler Anzeige oben / M3-Löcher / Testpunkte vorhanden | ☐ | |
| C6 | Silkscreen-Titel / Polarität Zeners / Pin-1-Markierungen plausibel | ☐ | |

## D · BOM & Beschaffung

| # | Prüfpunkt | OK | Notiz |
|---|---|:--:|---|
| D1 | LCSC-Kernteile laut `bom_verfuegbarkeit.md` (01.08.2026) akzeptiert | ☐ | |
| D2 | TPS62163: begrenzter Bestand → Reserve geplant | ☐ | |
| D3 | Manuelle Teile: DY-SV17F, Kübler, MPT 8×2 + 2×3, optional Sockel U2 | ☐ | |
| D4 | `JLCPCB_BOM.csv` vs. Schaltplan stimmig (Q6/D13 LCSC ergänzt) | ☐ | |

## E · Fertigungsdaten

| # | Prüfpunkt | OK | Notiz |
|---|---|:--:|---|
| E1 | Gerber-ZIP vorhanden und Lagen vollständig (Cu, Mask, Silk, Paste, Edge, Drill) | ☐ | |
| E2 | CPL / Pos für SMD vorhanden | ☐ | |
| E3 | Schaltplan-PDF + PCB-PDF im Paket | ☐ | |
| E4 | Bestellparameter 2-layer / 1,6 mm akzeptiert (Finish nach Wahl) | ☐ | |

## F · Simulation & Rest-Risiken

| # | Prüfpunkt | OK | Notiz |
|---|---|:--:|---|
| F1 | HTML-Sim / digitaler Zwilling für Phasen Idle→Play→Release verstanden | ☐ | |
| F2 | Grenzen der Sim akzeptiert (kein SPICE-Ripple, keine Faults) | ☐ | |
| F3 | M03 LTspice: **entweder** als Auflage nachziehen **oder** bewusst verschieben | ☐ | |
| F4 | Feld O1–O7: nicht PCB-blockierend; Parallelplan OK | ☐ | |

## G · Freigabe-Entscheidungen (explizit)

| # | Entscheidung | Wahl | Notiz |
|---|---|---|---|
| G1 | E03: Real case ≥1 Jahr als Planungsbasis | ☐ akzeptiert / ☐ Nacharbeit | |
| G2 | Kübler 4,5 V-Typ an 5 V-Rail | ☐ akzeptiert / ☐ auf 12 V-Typ wechseln | |
| G3 | ERC/DRC-Warnungen | ☐ akzeptiert / ☐ vor Bestellung fixen | |
| G4 | LTspice M03 | ☐ vor Bestellung / ☐ parallel Prototyp / ☐ entfallen mit Begründung | |

---

## Signatur

| | |
|--|--|
| Reviewer (Name) | |
| Datum | |
| Rolle | (z. B. Elektronik / Projektleitung) |
| **Ergebnis** | ☐ **FREIGABE** · ☐ **FREIGABE MIT AUFLAGEN** · ☐ **SPERRE** |

### Auflagen / Sperrgründe

```
(frei formulieren)

```

### Nächster Schritt nach Freigabe

1. JLCPCB: `hardware/2.final/vogelstimmen_v2.4-Gerber.zip` (+ optional BOM/CPL)  
2. LCSC / manuelle Teile laut `bom_verfuegbarkeit.md`  
3. Bring-up nach Traceability Phase 2/3 (`A01`…)

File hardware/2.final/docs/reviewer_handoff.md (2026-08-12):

# Reviewer-Handoff — vor Fertigung (Rev 2.4)

**Datum:** 3. August 2026  
**Projekt:** Soundplatine Waldlehrpfad · Kolping Alteglofsheim · Konrad Senn  
**Ziel dieses Pakets:** Design-Review und Freigabe **vor** JLCPCB-/Teilebestellung (Anforderung **M04**).

---

## 1. Auftrag an den Reviewer

Bitte prüfen und mit Signatur in [`review_checkliste_m04.md`](review_checkliste_m04.md) abschließen:

1. Architektur und Strompfade (Latch Idle ≈0 µA, Kaltstart Q6, BUSY-Release)
2. Spannungsfestigkeit / VGS-Schutz / Kübler an 5 V
3. BOM + Verfügbarkeit + manuelle Teile
4. PCB/DRC/ERC und Fertigungsdaten in `hardware/2.final/`
5. Offene Risiken akzeptieren oder Nacharbeit fordern

**Gewünschtes Ergebnis:** Freigabe „Bestellung erlaubt“ **oder** Liste blockierender Nacharbeiten.

> **Adversarial Review:** [`adversarial_review_v24.md`](adversarial_review_v24.md) — **F-01…F-09 geschlossen** (03.08.2026): Respin F-01…F-05 + F-06…F-09 dispositioniert. Proto optional (F-03/F-04/F-08).  
> **Fertigung:** `hardware/2.final/` ist **Pre-Respin** — vor Bestellung neu exportieren.

---

## 2. Lesereihenfolge (ca. 45–90 min)

| # | Dokument / Artefakt | Warum |
|---|---|---|
| 1 | **Dieses Dokument** | Überblick + Scope |
| 2 | Cursor-Canvas **fertigung-readiness-v24** (neben Chat öffnen) | Gate-Status, Risiken, Sign-off-Überblick |
| 3 | [`zwischenstand.md`](zwischenstand.md) | Aktueller Projektstatus |
| 4 | [`anforderungen.md`](anforderungen.md) | Lastenheft F/E/H/U/M |
| 5 | [`entscheidungen.md`](entscheidungen.md) | E-LATCH-01/02, E-RPP-01, E-VGS-01, E-CNT-01, E-CONN-01 |
| 6 | [`systemarchitektur.md`](systemarchitektur.md) | BDD / IBD / Timing |
| 7 | [`schaltplan.md`](schaltplan.md) + PDF in `hardware/2.final/` | Blöcke B1–B8 |
| 8 | [`pcb_v2.4.md`](pcb_v2.4.md) + PCB-PDF | Layout-Constraints |
| 9 | [`bom_verfuegbarkeit.md`](bom_verfuegbarkeit.md) | LCSC Stand 01.08.2026 |
| 10 | [`traceability.md`](traceability.md) | Req→Block→Verifikation; E03-Analyse |
| 11 | [`digitaler_zwilling.md`](digitaler_zwilling.md) + `simulation/` | Verhaltensmodell |
| 12 | [`review_checkliste_m04.md`](review_checkliste_m04.md) | Abhaken + Signatur |
| 13 | `hardware/2.final/` | Gerber, BOM, CPL, DRC/ERC |

KiCad öffnen: `hardware/vogelstimmen_v2.4.kicad_pro`  
Simulation: `python simulation/serve.py` → http://127.0.0.1:8765/

---

## 3. System in einem Satz

8 beleuchtete Taster → Hardware-Latch weckt 12 V-Schiene → Buck 5 V → DY-SV17F spielt Vogelstimme → BUSY schaltet Latch ab; Idle-Elektronik ~12 µA (R6); Kübler zählt Sessions.

---

## 4. Fertigungsartefakte

| Artefakt | Pfad |
|---|---|
| Gerber-ZIP (Upload) | `hardware/2.final/vogelstimmen_v2.4-Gerber.zip` |
| SMD-BOM LCSC | `hardware/2.final/JLCPCB_BOM.csv` |
| CPL | `hardware/2.final/vogelstimmen_v2.4-cpl.csv` |
| Schaltplan/PCB PDF | `hardware/2.final/*-schematic.pdf`, `*-pcb.pdf` |
| Gesamtpaket | `hardware/2.final.zip` |
| Anleitung Paket | `hardware/2.final/README.md` |

### Manuell (nicht JLCPCB-SMD)

- DY-SV17F (+ optional 2×9 Sockel)
- Kübler **1.130.900.008**
- Phoenix MPT 0,5/8 ×2 (z. B. 1725711), MPT 0,5/2 ×3

---

## 5. Bekannte Restpunkte (nicht verschweigen)

| Punkt | Schwere | Empfehlung |
|---|---|---|
| DRC: U2 Footprint vs. Lib-Mismatch | Warnung | Akzeptieren oder Lib synchronisieren — kein Open-Net |
| ERC: Label `SET_DRV` isolated | Warnung | Kosmetik; Netz ist verdrahtet |
| M03 LTspice D06/D07 | Prozess offen | HTML-Sim + Analyse vorhanden; LTspice optional vor/parallel Prototyp |
| Feld O1–O7 (Gehäuse, LS-Z, …) | System, nicht PCB | Parallel zur PCB-Bestellung klären |
| TPS62163 Bestand ~510 | Beschaffung | +1 Reserve |
| E03 Worst-case ~9 Monate | Sensitivität | Real case ≥1 Jahr dokumentiert; Worst case akzeptieren oder größere Batterie |

---

## 6. Was der Reviewer *nicht* leisten muss

- Bring-up / Idle-µA-Messung (erst nach Bestückung, Phase A/T in Traceability)
- Gehäuse-CAD oder Audio-Content laden
- Rev-1-Archiv bewerten (nur Historie unter `rev1_archiv/`)

---

## 7. Rückmeldung

Bitte Ergebnis in `review_checkliste_m04.md` § Signatur eintragen:

- **FREIGABE** — Bestellung Gerber + Teile erlaubt  
- **FREIGABE MIT AUFLAGEN** — Bestellung ja, Auflagen dokumentieren  
- **SPERRE** — blockierende Punkte auflisten  

Optional: kurzes Review-Protokoll (1 Seite) zusätzlich ablegen.

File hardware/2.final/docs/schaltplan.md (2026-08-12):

# Schaltplan: Vogelstimmenkasten Rev 2.4 (Respin)

**Architektur:** DY-SV17F + Latch-Schaltung + TPS62163 Buck  
**Basis:** `docs/systemarchitektur.md`, `docs/anforderungen.md`  
**KiCad:** `hardware/vogelstimmen_v2.4.kicad_sch` / `.kicad_pcb`  
**Datum:** 3. August 2026 (Respin F-01…F-05)

---

## Blockschaltbild

```
                           12V_PROT (immer an)
  12V Batterie                │
  ┌──┐   ┌───┐   ┌───┐       │
  │J_BAT│→│Q_RPP│→│PTC│→──────┤
  └──┘   │P-FET│  │1A │       │
         └───┘   └───┘       │
         D_TVS ──┤            │
                 GND          │
                              │
              ┌───────────────▼────────────────┐
              │       B2: LATCH-SCHALTUNG      │
              │  SET ← D1–D8 OR (BTN_OR)       │
              │  HOLD ← R4 Selbsthaltung       │
              │  RELEASE ← BUSY via Q3+RC      │
              └───────┬────────────┬───────────┘
                      │            │
                   12V_SW    12V_SW→R12→12V_LED
                      │            │
              ┌───────▼───┐    ┌───▼───┐
              │ TPS62163  │    │ J_LED │→ 8× Taster-LEDs
              │ Buck 5V   │    └───────┘
              └─────┬─────┘
                    │ 5V
          ┌─────────┼──────────┐
          │         │          │
    ┌─────▼─────┐ ┌─▼────────┐│
    │ DY-SV17F  │ │ Kübler   ││
    │ U2        │ │ K07.90   ││
    │ IOx_M←D15+│ └──────────┘│
    │ BUSY→RC→Q3│              │
    │ SPK→J2    │              │
    └──────────────────────────┘
```

---

## B1: Batterie-Eingangsschutz

(unverändert — siehe Rev 2.4)

```
J_BAT / J1 (Phoenix MPT 0,5/2-2,54)
  Pin 1 (+12V) → Q5 Source (BAT+)
  Pin 2 (GND)  → GND

Q5 (SI2301CDS) — Verpolungsschutz, D11 VGS-Clamp, R7/R6 Gate
F1 PTC 1A/24V → 12V_PROT
D9 SMAJ15A, C1 10µF/25V
```

---

## B2: Latch-Schaltung

```
Taster → GND (IOx LOW, Mode 0)
   D1–D8: K=IOx, A=BTN_OR          (Latch-OR, 12V-Domain)
   R9 10k: 12V_PROT → BTN_OR
   R11 4k7 + D14: BTN_OR → Q6_GATE
   Q6 SI2301 (P): S=12V_PROT, D=SET_DRV
   R10 1k + D13: SET_DRV → LATCH_SET

LATCH_SET → Q2.Gate; R2→GND; R4←12V_SW (Hold)
Q3: G=Q3_GATE, S=GND, D=LATCH_SET (Release bei BUSY HIGH)
   R13 100k: BUSY → Q3_GATE
   C4 4,7µF: Q3_GATE → GND           (Blanking ~470 ms, F-03)

Q2.Drain = LATCH_GATE → R8 → Q1_GATE → Q1 → 12V_SW
```

### Bauteil-Liste Latch

| Ref | Bauteil | Paket | Funktion |
|-----|---|---|---|
| Q1 | SI2301CDS | SOT-23 | P-FET Leistungsschalter (12V_SW) |
| D12 | BZX84C6V2 | SOT-23 | VGS-Clamp Q1 |
| R8 | 4,7 kΩ | 0402 | Serie Q2→Q1.Gate |
| Q2 | 2N7002 | SOT-23 | N-FET Latch-Logik |
| Q3 | 2N7002 | SOT-23 | BUSY → LATCH_SET (Release) |
| **R13** | **100 kΩ** | **0402** | **BUSY → Q3_GATE (Serie, F-03)** |
| **C4** | **4,7 µF/16 V** | **0805** | **Q3_GATE → GND (Blanking, F-03)** |
| Q6 | SI2301 | SOT-23 | P-FET Kaltstart-SET |
| D14 | BZX84C6V2 | SOT-23 | VGS-Clamp Q6 |
| R1 | 100 kΩ | 0402 | Q1 Gate Pull-up |
| R2 | 100 kΩ | 0402 | Q2 Gate Pull-down |
| R3 | 10 kΩ | 0402 | BUSY Pull-down |
| R4 | 10 kΩ | 0402 | Selbsthaltung von 12V_SW |
| R6 | 470 kΩ | 0402 | Q5 Gate→GND |
| R9 | 10 kΩ | 0402 | Pull-up BTN_OR |
| R10 | 1 kΩ | 0402 | Serie SET (vs. Q3) |
| R11 | 4,7 kΩ | 0402 | Serie Gate Q6 |
| D1–D8 | 1N4148WS | SOD-323 | Active-Low OR → BTN_OR |
| D13 | 1N4148WS | SOD-323 | SET_PULSE → LATCH_SET |

### Ablauf

1. **Kaltstart:** IOx→GND → BTN_OR LOW → Q6 ein → D13 → Latch AN (ohne 5 V)
2. **12V_SW da:** R4 hält LATCH_SET
3. **BUSY = LOW:** Q3 sperrt → Hold bleibt
4. **BUSY = HIGH:** Q3 zieht LATCH_SET → Latch AUS (verzögert durch R13/C4)

---

## B3: Buck-Converter (12V → 5V)

```
U1 (TPS62163DSGR, feste 5.0 V)
  VIN/EN → 12V_SW
  FB     → AGND (Fixed-5V-Version)
  VOS    → 5V über R5 = 0 Ω (F-02, direkt an C3)
  SW     → L1 → 5V

C2 10µF/25V (VIN), C3 22µF/10V (VOUT), L1 2,2 µH
```

**Hinweis TI:** VOS direkt und kurz an VOUT/COUT — **kein** Vorwiderstand.

---

## B4: DY-SV17F Audio-Modul (U2)

Modul auf 2× Stiftleisten (je 1×9), **nicht verlötet**.

```
Pin  1–8 (IO0–IO7)  ← IO0_M…IO7_M ← D15–D22 (Serie, F-01)
Pin  9, 10 (GND)    → GND
Pin 11 (CON2)       → V33 (Mode 0)
Pin 12 (BUSY)       → R3 (10k→GND), R13 (→ Q3_GATE)
Pin 13 (V5)         ← 5V
Pin 14 (V33)        → CON2
Pin 17/18 (SPK±)    → J2 (BTL, ≥0,4 mm Leiterbahn)
```

### IO-Domain-Trennung (F-01)

Pro Kanal **zwei Dioden**:

| Diode | Pfad | Funktion |
|---|---|---|
| D1–D8 | K=**IOx**, A=**BTN_OR** | Latch-SET über 12-V-OR |
| D15–D22 | A=**IOx_M**, K=**IOx** | Modul vor 12 V auf Kabelseite schützen |

```
U2.IOx_M ──A── D15+ ──K── IOx ── J3 ── Taster ── GND
                              └── D1 ── BTN_OR (Latch)
```

Tasterdruck: IOx→GND → fallende Flanke an U2 über D15–D22.

### Mode 0

| Pin | Verbindung |
|-----|---|
| CON1 (10) | GND |
| CON2 (11) | V33 |
| CON3 (12) | R3→GND; danach BUSY-Ausgang |

---

## B5: Impulszähler

```
J5 Kübler K07.90 (1.130.900.008, 4,5 V Typ 0 @ 5 V)
  + → 5V,  − → GND
D10 1N4148WS: K=5V, A=GND (Freilauf)
```

Kein Q4 — Zähler direkt an 5-V-Schiene (nur bei Latch AN).

---

## B6: Taster-Interface

```
J3 (IO) / J4 (GND) — Phoenix MPT 0,5/8-2,54

J3 Pin 8…1 → IO0…IO7 (Kabelseite, 12-V-Domain über D1–D8/R9)
J4 Pin 9…16 → GND

D1–D8: Latch-OR (s. o.)
D15–D22: Modul-Schutz (s. B4)

Extern: Metzler P19-TF-W o.ä. (5-pol: C, NO, NC, LED+, LED−)
  IO + GND → J3/J4
  LED+ / LED− → J6 (über R12)
```

---

## B7: Lautsprecher

```
J2: Pin1=SPK+, Pin2=SPK− (BTL — keine Seite an GND!)
SPK-Bahnen PCB: ≥ 0,4 mm (F-05)
```

---

## B8: Taster-LED-Versorgung

```
12V_SW → R12 (10 Ω, 0402) → 12V_LED → J6 Pin 1
J6 Pin 2 → GND

Extern: alle 8 LED+ parallel an Pin 1, LED− an Pin 2.
Leuchten gemeinsam während Wiedergabe (F11).
```

**Annahme:** Metzler-LEDs 6–24 V mit internem Vorwiderstand. R12 begrenzt Kurzschlussstrom.

---

## Steckverbinder

| Ref | Typ | Funktion |
|-----|-----|---|
| J1 | MPT 0,5/2 | Batterie |
| J2 | MPT 0,5/2 | Lautsprecher |
| J3/J4 | MPT 0,5/8 | Taster IO / GND |
| J5 | K07.90 | Impulszähler |
| J6 | MPT 0,5/2 | Taster-LEDs |

---

## Netzliste (aus PCB, Stand 03.08.2026)

| Netz | Verbundene Punkte |
|---|---|
| GND | J1.2, J4.*, J6.2, C1–C4.2, D9.1, D10.2, Q2.S, Q3.S, Q5.1, R3.2, R6.2, TP3, U1 AGND/PGND, U2.9/10, … |
| BAT+ | J1.1, Q5.2, D11.1 |
| 12V_PROT | F1.2, D9.2, D12.1, D14.1, Q1.2, Q6.2, R1.2, R9.1, TP1 |
| 12V_SW | Q1.3, R4.1, R12.1, U1 VIN/EN, C2.1 |
| **12V_LED** | **R12.2, J6.1** |
| 5V | C3.1, L1.2, R5.1, D10.1, J5.1, TP2, U2.13 |
| VOS | R5.2, U1.6 |
| V33 | U2.11, U2.14 |
| BUSY | U2.12, R3.1, R13.1, TP4 |
| **Q3_GATE** | **Q3.1, R13.2, C4.1** |
| IO0…IO7 | J3, D1–D8.1, D15–D22.1 (Kathode) |
| **IO0_M…IO7_M** | **U2.1–8, D15–D22.2 (Anode)** |
| BTN_OR | D1–D8.2, R9.2, R11.1 |
| LATCH_SET | D13.1, Q2.1, Q3.3, R2.1, R4.2 |
| SPK+/SPK− | U2.18/17, J2, TP5 |

---

## Testpunkte

| TP | Netz |
|----|---|
| TP1 | 12V_PROT |
| TP2 | 5V |
| TP3 | GND |
| TP4 | BUSY |
| TP5 | SPK+ |

---

## BOM-Übersicht (SMD + manuell)

| Ref | Wert | LCSC | Anmerkung |
|-----|---|---|---|
| D1–D8, D10, D13 | 1N4148WS | C118873 | Latch-OR / Freilauf |
| **D15–D22** | **1N4148WS** | **C118873** | **Serie U2 IO (F-01)** |
| D11, D12, D14 | BZX84C6V2 | C179522 | VGS-Clamp |
| D9 | SMAJ15A | C113958 | TVS |
| Q1, Q5, Q6 | SI2301 | C10487 | P-FET |
| Q2, Q3 | 2N7002 | C16338 | N-FET |
| U1 | TPS62163 | C97534 | Buck |
| L1 | 2,2 µH | C88527 | |
| C1, C2 | 10 µF/25 V | — | |
| C3 | 22 µF/10 V | — | VOUT |
| **C4** | **4,7 µF/16 V** | — | **Q3 Blanking** |
| R1, R2, **R13** | 100 kΩ | — | |
| **R5** | **0 Ω** | — | **VOS sense (F-02)** |
| R3, R4, R9 | 10 kΩ | — | |
| R6 | 470 kΩ | — | |
| R7, R8, R11 | 4,7 kΩ | — | |
| R10 | 1 kΩ | — | |
| **R12** | **10 Ω** | — | **LED-Serie (F-04)** |
| F1 | PTC 1A/24 V | C2760272 | |
| U2 | DY-SV17F | — | manuell |
| J5 | K07.90 | — | manuell |
| J1–J4, J6 | MPT Phoenix | — | manuell |

**SMD:** ~39 Stück (inkl. Respin) → JLCPCB  
**THT:** Modul, Zähler, Klemmen

---

## Respin F-01…F-05 (02.08.2026)

| ID | Änderung |
|----|---|
| F-01 | D15–D22 Serie U2↔IOx |
| F-02 | R5 → 0 Ω (VOS) |
| F-03 | R13 + C4 BUSY-Blanking → Q3_GATE |
| F-04 | R12 10 Ω, Netz 12V_LED |
| F-05 | SPK ≥ 0,4 mm |

Details: `docs/adversarial_review_v24.md`, `docs/entscheidungen.md` E-RESPIN-01.

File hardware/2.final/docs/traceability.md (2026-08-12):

# Traceability-Matrix & Verifikationsplan

**Datum:** 29. Juli 2026
**Projekt:** Vogelstimmenkasten Rev 2

---

## 1. Direkte Traceability (R → P)

| Req-ID | Anforderung (Kurzform) | Block(s) | Schaltplan-Ref | Verifikation |
|---|---|---|---|---|
| F01 | 8 Taster anschließbar | B6 | J3, J4 (2×8-pol) | V-INS |
| F02 | Feste Zuordnung Taster→Stimme | B4, B6 | IO1–IO8 → DY-SV17F | V-FUN |
| F03 | Wiedergabe < 500ms nach Druck | B2, B3, B4 | Latch + Buck + Boot | V-FUN |
| F04 | Tonsequenz ~10s | B4 | DY-SV17F Audio-Datei | V-FUN |
| F05 | Lautstärke 2–3m, 3W | B4, B7 | SPK+/SPK- (BTL) | V-FUN |
| F06 | Audio per USB austauschbar | B4 | Micro-USB am Modul | V-FUN |
| F07 | Retrigger: neue Stimme ersetzt alte | B4 | Mode 0 (Flanken-Trigger) | V-FUN |
| F08 | Keine gleichzeitige Wiedergabe | B4 | Mode 0 Eigenschaft | V-FUN |
| F09 | Mono-Lautsprecher | B7 | 1× SPK, BTL | V-INS |
| F10 | Impulszähler zählt Sessions | B5 | Kübler K07 an 5V | V-FUN |
| F11 | Taster-LEDs während Wiedergabe | B8 | 12V_SW → LEDs | V-FUN |
| E01 | Betrieb über 12V Batterie | B1, B3 | J1, TPS62163 | V-INS |
| E02 | Ruhestrom < 100 µA | B2 | Latch AUS → 0 µA | V-MES |
| E03 | Batterie ≥ 1 Jahr | B2 | Berechnung | V-ANA |
| E04 | Aufwachen per Taster | B2, B6 | Dioden-OR → Latch SET | V-FUN |
| E05 | Auto-Abschaltung nach Wiedergabe | B2, B4 | BUSY HIGH → Q3 → Latch AUS | V-FUN |
| E06 | Verstärker im Modul integriert | B4 | DY-SV17F intern | V-INS |
| U01 | -10°C bis +60°C | alle | Datenblatt-Prüfung | V-ANA |
| U02 | Feuchtigkeit tolerieren | — | Conformal Coating | V-INS |
| U03 | Wartungsfrei ≥ 1 Jahr | alle | Design-Review | V-REV |
| U04 | Keine beweglichen Teile | B4 | Flash intern, kein SD | V-INS |
| U05 | Kein Netzanschluss | B1 | Nur Batterie | V-INS |
| H01 | Printzähler 5V DC auf PCB | B5 | Kübler K07.90 (5V) | V-INS |
| H02 | SMD durch JLCPCB bestückt | alle SMD | BOM + CPL | V-REV |
| H03 | Manuell: THT + DY-SV17F + Zähler | B4, B5, B6 | THT MPT-Klemmen J1–J4,J6 | V-INS |
| H04 | 4× M3 Montagelöcher | PCB | Layout | V-INS |
| H05 | Testpunkte: 12V, 5V, GND, BUSY, Audio | PCB | TP1–TP5 | V-INS |
| H06 | Zähler von oben ablesbar (K07.90) | B5, PCB | Layout-Constraint | V-INS |
| H07 | VGS-Schutz SI2301 (Q5/Q1) per Zener 6,2 V | B1, B2 | D11, D12, R7, R8 | V-INS |
| M01 | BOM vorab bei LCSC verifiziert | — | `bom_verfuegbarkeit.md` | V-REV |
| M02 | Spannungsprüfung aller ICs | alle | Datenblatt vs. Schaltplan | V-REV |
| M03 | LTspice Simulation Stromversorgung | B3 | Simulation | V-SIM |
| M04 | Review-Checkliste vor Bestellung | — | Review-Dokument | V-REV |

---

## 1a. Funktionale Architektur (RFP-Kette)

MBSE-Referenzbeispiel: vollständige Kette **Requirement → Function → Physical**.

### Tabelle A: Systemfunktionen (F-Ebene)

| SF-ID | Systemfunktion | Beschreibung |
|---|---|---|
| SF-01 | Benutzereingabe erfassen | Tastendruck erkennen und dem zugehörigen Kanal zuordnen |
| SF-02 | System einschalten | Latch aktivieren und Versorgung freigeben |
| SF-03 | Versorgungsspannung bereitstellen | 12 V auf 5 V wandeln für Modul und Zähler |
| SF-04 | Vogelstimme abspielen | Eine zugewiesene Audio-Datei wiedergeben |
| SF-05 | Wiedergabe wechseln | Laufende Stimme beenden und neue starten (Retrigger) |
| SF-06 | System automatisch abschalten | Nach Wiedergabe-Ende Latch lösen und stromlos werden |
| SF-07 | Nutzung zählen | Aufweck-/Wiedergabe-Session am Impulszähler erfassen |
| SF-08 | Betriebszustand anzeigen | Taster-LEDs während aktiver Wiedergabe beleuchten |
| SF-09 | Audiodateien verwalten | MP3/WAV per USB auf das Modul laden |
| SF-10 | Eingangsschutz gewährleisten | Verpolung und Überspannung am Batterieeingang abfangen |
| SF-11 | Ruhestrom minimieren | Im Idle den Verbraucherpfad vollständig trennen |
| SF-12 | Schallwandlung | Mono-Audio über Lautsprecher ausgeben |

### Tabelle B: R → F (Anforderung → Funktion)

| Req-ID | Anforderung | SF-ID(s) |
|---|---|---|
| F01 | 8 Taster anschließbar | SF-01 |
| F02 | Feste Zuordnung Taster→Stimme | SF-01, SF-04 |
| F03 | Wiedergabe < 500ms nach Druck | SF-02, SF-03, SF-04 |
| F04 | Tonsequenz ~10s | SF-04 |
| F05 | Lautstärke 2–3m, 3W | SF-04, SF-12 |
| F06 | Audio per USB austauschbar | SF-09 |
| F07 | Retrigger: neue Stimme ersetzt alte | SF-05 |
| F08 | Keine gleichzeitige Wiedergabe | SF-04, SF-05 |
| F09 | Mono-Lautsprecher | SF-12 |
| F10 | Impulszähler zählt Sessions | SF-07 |
| F11 | Taster-LEDs während Wiedergabe | SF-08 |
| E01 | Betrieb über 12V Batterie | SF-03, SF-10 |
| E02 | Ruhestrom < 100 µA | SF-11 |
| E03 | Batterie ≥ 1 Jahr | SF-11 |
| E04 | Aufwachen per Taster | SF-01, SF-02 |
| E05 | Auto-Abschaltung nach Wiedergabe | SF-06 |
| E06 | Verstärker im Modul integriert | SF-04, SF-12 |
| U01 | -10°C bis +60°C | SF-03, SF-04, SF-10, SF-11 |
| U02 | Feuchtigkeit tolerieren | SF-10 |
| U03 | Wartungsfrei ≥ 1 Jahr | SF-09, SF-11 |
| U04 | Keine beweglichen Teile | SF-04, SF-09 |
| U05 | Kein Netzanschluss | SF-03, SF-10 |
| H01 | Printzähler 5V DC auf PCB | SF-07 |
| H02 | SMD durch JLCPCB bestückt | SF-03, SF-10, SF-11 |
| H03 | Manuell: THT + DY-SV17F + Zähler | SF-01, SF-04, SF-07 |
| H04 | 4× M3 Montagelöcher | SF-07 |
| H05 | Testpunkte: 12V, 5V, GND, BUSY, Audio | SF-03, SF-04, SF-06 |
| H06 | Zähler von oben ablesbar (K07.90) | SF-07 |
| H07 | VGS-Schutz P-FETs (D11/D12) | SF-02, SF-10 |
| M01 | BOM vorab bei LCSC verifiziert | SF-03, SF-10, SF-11 |
| M02 | Spannungsprüfung aller ICs | SF-03, SF-10 |
| M03 | LTspice Simulation Stromversorgung | SF-03, SF-11 |
| M04 | Review-Checkliste vor Bestellung | SF-01–SF-12 |

### Tabelle C: F → P (Funktion → Physisch)

| SF-ID | Systemfunktion | Block(s) | Schlüsselkomponente |
|---|---|---|---|
| SF-01 | Benutzereingabe erfassen | B6, B4 | J3/J4 → IOx → **D15–D22** → **IOx_M** → U2 |
| SF-02 | System einschalten | B2, B6 | D1–D8 → BTN_OR → Q6 → Latch SET |
| SF-03 | Versorgungsspannung bereitstellen | B1, B3 | TPS62163, L1, C2/C3 |
| SF-04 | Vogelstimme abspielen | B4 | DY-SV17F Mode 0 |
| SF-05 | Wiedergabe wechseln | B4 | DY-SV17F Flanken-Trigger |
| SF-06 | System automatisch abschalten | B2, B4 | BUSY → **R13/C4** → Q3 → Latch AUS |
| SF-07 | Nutzung zählen | B5 | Kübler K07.90 an 5V |
| SF-08 | Betriebszustand anzeigen | B8 | 12V_SW → **R12** → 12V_LED → J6 |
| SF-09 | Audiodateien verwalten | B4 | Micro-USB am DY-SV17F |
| SF-10 | Eingangsschutz gewährleisten | B1 | Q5, D11, R6/R7, SMAJ15A, PTC |
| SF-11 | Ruhestrom minimieren | B2 | Q1/Q2 Latch (0 µA Idle) |
| SF-12 | Schallwandlung | B4, B7 | SPK+/SPK− (BTL) |

### Exemplarische RFP-Ketten (Mermaid)

```mermaid
flowchart LR
  subgraph R["Requirement"]
    F07["F07 Retrigger"]
    E02["E02 Ruhestrom &lt; 100 µA"]
    F10["F10 Sessions zählen"]
  end

  subgraph F["Function"]
    SF05["SF-05 Wiedergabe wechseln"]
    SF11["SF-11 Ruhestrom minimieren"]
    SF07["SF-07 Nutzung zählen"]
  end

  subgraph P["Physical"]
    B4["B4 DY-SV17F Mode 0"]
    B2["B2 Latch Q1/Q2"]
    B5["B5 Kübler K07.90"]
  end

  F07 --> SF05 --> B4
  E02 --> SF11 --> B2
  F10 --> SF07 --> B5
```

### Legende Verifikationsmethoden

| Kürzel | Methode | Beschreibung |
|---|---|---|
| V-FUN | Funktionstest | Praktischer Test am aufgebauten Prototyp |
| V-MES | Messung | Messwert mit Multimeter/Oszilloskop erfassen |
| V-INS | Inspektion | Visuelle Prüfung / Augenscheinnahme |
| V-ANA | Analyse | Rechnerischer Nachweis / Datenblatt-Vergleich |
| V-REV | Review | Dokumentenprüfung / Checkliste |
| V-SIM | Simulation | LTspice / Digitaler Zwilling |

---

## 2. Verifikationsplan

### Phase 1: Design-Verifikation (vor Fertigung)

| # | Prüfpunkt | Methode | Referenz | Status |
|---|---|---|---|---|
| D01 | Alle IC-Spannungen vs. Datenblatt-Max | V-REV | M02 | ✅ erledigt |
| D02 | BOM bei LCSC verfügbar + korrekte Footprints | V-REV | M01, `bom_verfuegbarkeit.md` | ✅ erledigt |
| D03 | Systemarchitektur dokumentiert (BDD/IBD) | V-REV | `systemarchitektur.md` | ✅ erledigt |
| D04 | Schaltplan-Dokumentation vollständig | V-REV | `schaltplan.md` | ✅ erledigt |
| D05 | Digitaler Zwilling: Logikfluss korrekt | V-SIM | Canvas Simulation | ✅ erledigt |
| D06 | LTspice: Buck-Converter Ripple < 50mV | V-SIM | M03 | ⏳ offen |
| D07 | LTspice: Latch-Schaltung funktional | V-SIM | M03 | ⏳ offen |
| D08 | KiCad ERC = 0 Fehler | V-REV | KiCad | ✅ erledigt (`ERC_v2_check.rpt`; 1 Warnung SET_DRV) |
| D09 | KiCad DRC = 0 Fehler | V-REV | KiCad | ✅ erledigt (`DRC_v2.4_check.rpt`; 1 Footprint-Warnung U2) |
| D10 | Review-Checkliste komplett | V-REV | M04 | ⏳ Vorlage bereit (`review_checkliste_m04.md`) — Signatur offen |

### Phase 2: Aufbau-Verifikation (nach Bestückung)

| # | Prüfpunkt | Methode | Req-IDs | Akzeptanzkriterium |
|---|---|---|---|---|
| A01 | Visuelle Inspektion Lötqualität | V-INS | H02, H03 | Keine Brücken, alle Teile korrekt |
| A02 | Kurzschlusstest vor Einschalten | V-MES | — | >1 MΩ zwischen 12V und GND |
| A03 | 12V anlegen, 5V messen | V-MES | E01 | 4,9V – 5,1V an TP_5V |
| A04 | Ruhestrom messen (kein Taster) | V-MES | E02 | < 100 µA (Ziel: 0 µA) |
| A05 | Verpolungsschutz testen | V-MES | — | Kein Strom bei falscher Polung |

### Phase 3: Funktionstest (am Prototyp)

| # | Prüfpunkt | Methode | Req-IDs | Akzeptanzkriterium |
|---|---|---|---|---|
| T01 | Taster 1–8 einzeln drücken | V-FUN | F01, F02 | Jeder spielt korrekte Stimme |
| T02 | Wiedergabe-Latenz messen | V-MES | F03 | < 500ms (Oszilloskop: Taster-Flanke → Audio-Ausgang) |
| T03 | Sound-Dauer prüfen | V-FUN | F04 | ~10s pro Stimme |
| T04 | Lautstärke in 2m Abstand | V-FUN | F05 | Gut wahrnehmbar |
| T05 | Retrigger: Taster während Wiedergabe | V-FUN | F07 | Alte Stimme stoppt, neue startet |
| T06 | Keine Doppelwiedergabe | V-FUN | F08 | Nur 1 Stimme gleichzeitig |
| T07 | Zähler inkrementiert bei Aufweck-Event | V-FUN | F10 | +1 pro Latch-AN |
| T08 | LEDs leuchten während Wiedergabe | V-FUN | F11 | Alle 8 LEDs an |
| T09 | Auto-Abschaltung nach Sound-Ende | V-FUN | E05 | System geht in Idle (0 µA) |
| T10 | USB Audio-Upload | V-FUN | F06 | PC erkennt USB-Stick, Dateien kopierbar |
| T11 | 1000-Zyklen Dauertest | V-FUN | — | Kein Fehler nach 1000 Betätigungen |

### Phase 4: Umwelt-Verifikation (optional)

| # | Prüfpunkt | Methode | Req-IDs | Akzeptanzkriterium |
|---|---|---|---|---|
| U01 | Kältetest -10°C | V-FUN | U01 | Funktion OK |
| U02 | Hitzetest +60°C | V-FUN | U01 | Funktion OK |
| U03 | Feuchtigkeitstest (Betauung) | V-FUN | U02 | Kein Ausfall |

---

## 3. Batterie-Lebensdauer (Analyse V-ANA für E03)

**Batterie:** herkömmliche 12 V-Autobatterie (Blei), ~30 Ah.  
**Elektronik-Idle:** ~12 µA (R6 Verpolungsschutz); Latch/Buck/Modul aus — für Jahresbilanz vernachlässigbar (~0,1 mAh/a).

### Real case (Basis für E03 ≥ 1 Jahr) — Stand 01.08.2026

| Annahme | Wert |
|---|---|
| Selbstentladung | ~1,5 %/Monat (gesunde Batterie, gemäßigte Temperatur) |
| Nutzung | ~10×/Tag × ~15 s |
| Aktivstrom Mittel | ~250 mA |
| Nutzbare Kapazität | 50 % DoD → 15 Ah |

- Aktiv/Tag: 10 × 15 s × 250 mA ≈ **10 mAh/Tag**
- Selbstentladung/Tag: 30 000 × 1,5 % / 30 ≈ **15 mAh/Tag**
- Summe ≈ **25 mAh/Tag** → 15 000 / 25 ≈ **600 Tage ≈ 1,5–2 Jahre**
- Mit Puffer (Wetter/Alter): **ca. 1 Jahr+** → **E03 Real case erfüllt**

### Konservativ / Worst case (nur zur Einordnung)

Selbstentladung 3 %/Monat, 20 Plays/Tag, 300 mA → ~55 mAh/Tag → **~9 Monate**.  
Nicht die Planungsbasis; zeigt Sensitivität auf Hitze/hohe Nutzung.

---

## 4. Zusammenfassung

| Kategorie | Gesamt | Erledigt | Offen |
|---|---|---|---|
| Design-Verifikation (D01–D10) | 10 | 6 | 4 |
| Aufbau-Verifikation (A01–A05) | 5 | 0 | 5 |
| Funktionstest (T01–T11) | 11 | 0 | 11 |
| Umwelttest (U01–U03) | 3 | 0 | 3 |
| **Gesamt** | **29** | **6** | **23** |

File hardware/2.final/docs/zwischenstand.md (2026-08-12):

# Zwischenstand: Vogelstimmenkasten Rev 2

**Datum:** 3. August 2026  
**Status:** **F-01…F-09 geschlossen** (Respin + Restrisiko dokumentiert) — DRC/ERC/Parität OK; **Proto + Gerber-Export** vor Serie  
**Reviewer:** [`reviewer_handoff.md`](reviewer_handoff.md) · [`adversarial_review_v24.md`](adversarial_review_v24.md) · [`review_checkliste_m04.md`](review_checkliste_m04.md)

---

## Erledigte Meilensteine

| # | Meilenstein | Dokument |
|---|---|---|
| 1 | Lastenheft Rev 2 | `docs/anforderungen.md` |
| 2 | Systemarchitektur (BDD/IBD/Zustandsdiagramm) | `docs/systemarchitektur.md` |
| 3 | Schaltplan Rev 2 (Block B1–B8) | `docs/schaltplan.md` |
| 4 | BOM-Verfügbarkeit bei LCSC geprüft | `docs/bom_verfuegbarkeit.md` |
| 5 | Traceability-Matrix + Verifikationsplan | `docs/traceability.md` |
| 6 | Digitaler Zwilling (System→Block→Bauteil) | `docs/digitaler_zwilling.md` |
| 7 | Rev-1-Dateien archiviert | `rev1_archiv/` |
| 8 | KiCad-Schaltplan (+ VGS-Teile D11/D12/R7/R8) | `hardware/vogelstimmen_v2.4.kicad_sch` |
| 9 | PCB-Platzierung Rev 2.2 | `hardware/vogelstimmen_v2.2.kicad_pcb` |
| 10 | PCB Rev 2.3 VGS-Zeners platziert | `hardware/vogelstimmen_v2.3.kicad_pcb` |
| 11 | PCB Rev 2.4 Latch Kaltstart ≈0 µA | `hardware/vogelstimmen_v2.4.kicad_pcb` |
| 12 | PCB Rev 2.4 Routing + DRC | `hardware/DRC_v2.4_check.rpt` — 0 Fehler, 0 unverbunden; 1 Footprint-Warnung U2 |
| 13 | Layout-Feinschliff + Sim-Export | `simulation/pcb_layout.json`, `pcb_tracks.json` (01.08.2026) |
| 14 | Steckverbinder → Phoenix MPT 0,5 (E-CONN-01) | J3/J4 = 8-pol; J1/J2/J6 = 2-pol |
| 15 | J3 Klemme 180° (Kabel oben), übrige von unten | Netze XY unverändert |
| 16 | Schaltplan als `vogelstimmen_v2.4.kicad_sch` | passt zu `.kicad_pro` / PCB 2.4 |
| 17 | Fertigungspaket `hardware/2.final/` | Gerber, BOM, CPL, Schaltplan/PCB PDF |
| 19 | **Respin F-01…F-05** (Adversarial Review) | D15–D22, R5=0R, R13/C4, R12, SPK≥0,4 mm |
| 20 | DRC/ERC/Parität nach Respin | `DRC_v2.5_f01f05.rpt`, `ERC_v2.5_f01f05.rpt` |
| 21 | **F-06…F-09 Restrisiko dispositioniert** | Einsatz ≤30 cm Schrank; F-07/08/09 akzeptiert — `adversarial_review_v24.md` |

## Getroffene Entscheidungen

### Audio-Modul: DY-SV17F (statt WT588D)
- 8 IO-Trigger, 5W Class-D Verstärker eingebaut, USB Drag&Drop
- Mode 0 (Flanken-Trigger) — Sound spielt nach kurzem Druck komplett durch
- Kein separater Verstärker, kein Programmer nötig

### Power-Management: Hardware-Latch (≈0 µA Standby)
- SI2301 (P-FET) + 2N7002 als Selbsthaltung — **E-LATCH-01**
- **VGS-Schutz:** BZX84C6V2 an Q5/Q1/Q6 + Serie-R — LCSC C179522
- **Kaltstart v2.4 (E-LATCH-02):** Active-Low-OR → **Q6 P-FET-SET** (nicht N-Inverter) → Latch-Idle ≈0 µA
- **R6 = 470 kΩ (E-RPP-01):** Q5-Gate-Idle ≈12 µA → E02 erfüllt
- **Simulation:** `simulation/` — HTML5 + Verhaltensmodell; Start: `python simulation/serve.py`
- **Release:** Q3.Drain an LATCH_SET
- Entscheidungstabelle: `docs/entscheidungen.md`

### Impulszähler: Kübler K07.90
- **Bestellnummer:** `1.130.900.008` (4,5 V DC / 10 Hz Typ 0) an 5 V-Rail
- Datenblatt Typ 0: **−10 % / +20 %** → 4,05…**5,4 V**; 5,0 V = +11 % → **im Spec** (E-CNT-01)
- Alternative: `1.130.900.012` (12 V) an 12V_SW
- Zählt Sessions; Anzeige oben; Footprint `vogelstimmen:K07.90`

### Batterie / E03
- Herkömmliche 12 V-Autobatterie (~30 Ah Blei)
- **Real case ≥ 1 Jahr** (siehe `traceability.md` §3); Idle-Elektronik ~12 µA vernachlässigbar

### Stromversorgung: TPS62163 (12V → 5V)
- Einzige Spannungsebene: 5V für DY-SV17F + Zähler
- Verpolungsschutz: SI2301+D11, TVS: SMAJ15A, PTC: 1A/24V

### Taster-LEDs
- 6–24V LEDs an `12V_LED` über **R12 = 10 Ω** von `12V_SW` (F-04)
- Alle leuchten gemeinsam während Wiedergabe

## Layout-Constraints

- **DY-SV17F:** Am Platinenrand, Micro-USB nach außen zugänglich
- **Kübler K07.90:** Anzeige oben zum Gehäuse-Sichtfenster (H06); Footprint `vogelstimmen:K07.90`
- **4× M3 Montagelöcher** in den Ecken
- **Testpunkte:** TP_12V, TP_5V, TP_GND, TP_BUSY, TP_AUDIO

## ERC / DRC / Simulation / Fertigung (Stand 02.08.2026)

| Check | Ergebnis |
|---|---|
| **DRC** PCB (Respin F-01…F-05) | **0 Fehler, 0 unverbunden** (`DRC_v2.5_f01f05.rpt`); Parität Schaltplan OK |
| **ERC** Schaltplan | **0 Fehler**; 1 Warnung: Label `SET_DRV` (`isolated_pin_label`) |
| **Respin** | D15–D22 Serie U2; R5=0R; R13+C4 BUSY-Blanking; R12=10Ω J6; SPK≥0,4 mm (Haupt 0,8 mm) |
| **F-01…F-09** | Behoben oder akzeptiert — siehe `adversarial_review_v24.md` Dispositionstabelle |
| **Fertigung** | `hardware/2.final/` — **noch auf Pre-Respin**; Gerber/CPL/PDF neu erzeugen vor Order |

Details: `docs/pcb_v2.4.md`, `docs/bom_verfuegbarkeit.md`, `hardware/2.final/README.md`.

## Nächste Schritte

1. Gerber/CPL/PDF neu aus Working-PCB → `2.final/` aktualisieren + ZIP
2. Proto: optional F-03 Oszi; F-04 LED-Strom/R12-Temp.; F-08 5 V unter Last
3. M04 → Bestellung

## Projektdateien

| Datei | Inhalt |
|---|---|
| `docs/digitaler_zwilling.md` | System→Block→Bauteil (VGS-Schutz dokumentiert) |
| `docs/anforderungen.md` | Lastenheft Rev 2 (+ H07) |
| `docs/systemarchitektur.md` | Systemarchitektur (BDD, IBD, Timing) |
| `docs/schaltplan.md` | Schaltplan Rev 2 (Blöcke, Netzliste, BOM) |
| `docs/bom_verfuegbarkeit.md` | LCSC-Verfügbarkeit inkl. BZX84C6V2 |
| `docs/traceability.md` | Traceability + Verifikationsplan |
| `docs/kicad_anleitung.md` | KiCad + VGS-Verdrahtung |
| `docs/pcb_v2.2.md` | PCB Rev 2.2 Platzierung |
| `docs/entscheidungen.md` | Designentscheidungen (E-LATCH-01/02, …) |
| `docs/pcb_v2.3.md` | PCB Rev 2.3 Zeners |
| `docs/pcb_v2.4.md` | PCB Rev 2.4 — Routing + Feinschliff |
| `hardware/vogelstimmen_v2.4.kicad_pro` | **KiCad-Projekt öffnen** |
| `hardware/vogelstimmen_v2.4.kicad_sch` | Schaltplan Rev 2.4 |
| `hardware/vogelstimmen_v2.4.kicad_pcb` | PCB Rev 2.4 |
| `hardware/vogelstimmen_v2.kicad_sch` | älterer Schaltplan-Name (durch v2.4 ersetzt) |
| `hardware/vogelstimmen_v2.3.kicad_pcb` | PCB Rev 2.3 (Inverter-Kaltstart verworfen) |
| `hardware/DRC_v2.4_check.rpt` | DRC-Lauf |
| `hardware/ERC_v2_check.rpt` | ERC-Lauf |
| `hardware/2.final/` | **Fertigungspaket** (Gerber, BOM, CPL, PDFs) |
| `hardware/2.final.zip` | Gesamtarchiv Fertigung |
| `docs/reviewer_handoff.md` | **Einstieg Reviewer** vor Bestellung |
| `docs/review_checkliste_m04.md` | M04 Checkliste + Signatur |
| `simulation/pcb_layout.json` | Footprint-Positionen (Export) |
| `simulation/pcb_tracks.json` | Leiterbahnen (Export) |
| `rev1_archiv/` | Alle Rev-1-Dateien |

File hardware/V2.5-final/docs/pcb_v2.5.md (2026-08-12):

# KiCad PCB Rev 2.5 — Latch Kaltstart ≈0 µA

**Projekt:** `vogelstimmen_v2.5.kicad_pro`  
**Schaltplan:** `vogelstimmen_v2.5.kicad_sch`  
**PCB:** `vogelstimmen_v2.5.kicad_pcb`  
**Basis:** `vogelstimmen_v2.3.kicad_pcb`  
**Designentscheidung:** `docs/entscheidungen.md` → E-LATCH-02  
**Stand:** 3. August 2026 — Rev 2.5 Fertigpaket (Respin F-01…F-05 + GND-Vias)

## Respin F-01…F-05 (02.08.2026)

| Ref | Wert | Funktion |
|-----|---|---|
| **D15–D22** | 1N4148WS | Serie U2 IOx_M ↔ IOx (F-01) |
| **R5** | **0 Ω** | VOS direkt an 5 V (F-02) |
| **R13** | 100 kΩ | BUSY → Q3_GATE (F-03) |
| **C4** | 4,7 µF/16 V | Q3_GATE → GND (F-03) |
| **R12** | 10 Ω | 12V_SW → 12V_LED → J6 (F-04) |
| — | SPK ≥ 0,4 mm | Leiterbahnbreite (F-05) |

### Netze (neu/geändert)

```
IOx_M: U2 Pin 1–8 ← D15–D22 Anode
IOx:   J3 ← D15–D22 Kathode; D1–D8 Kathode; BTN_OR über D1–D8
Q3_GATE: Q3.G ← R13 ← BUSY; C4 nach GND
12V_LED: R12 → J6.1; 12V_SW → R12
VOS: R5 (0R) zwischen 5V und U1.VOS
```

## Änderung gegenüber v2.3

| Weg | v2.3 (verworfen) | v2.5 |
|-----|---|---|
| Kaltstart | Q4 N-FET-Inverter + R10 47 kΩ nach GND | **Q6 P-FET** von 12V_PROT |
| Ruhestrom | ~255 µA dauernd durch R10 | **≈0 µA** (P-FET aus, kein Lastwiderstand) |

## Neue / geänderte Bauteile

| Ref | Wert | Funktion |
|-----|---|---|
| Q6 | SI2301 | P-FET SET: Source=12V_PROT, Gate über R11, Drain→R10 |
| R11 | 4,7 kΩ | Serie Gate Q6 |
| D14 | BZX84C6V2 | VGS-Clamp Q6 (K=Source, A=Gate) |
| R10 | 1 kΩ | Serie SET_DRV→SET_PULSE (begrenzt Kurzschluss vs. Q3) |
| D13 | 1N4148WS | Steering SET_PULSE→LATCH_SET |
| R9 | 10 kΩ | Pull-up BTN_OR an 12V_PROT |
| — | Q4 entfernt | war 2N7002-Inverter |

## Netze

```
IOx --button-- GND
D1–D8: K=IOx, A=BTN_OR
R9: 12V_PROT → BTN_OR
R11: BTN_OR → Q6_GATE
D14: K=12V_PROT, A=Q6_GATE
Q6: S=12V_PROT, G=Q6_GATE, D=SET_DRV
R10: SET_DRV → SET_PULSE
D13: A=SET_PULSE, K=LATCH_SET
Q3: G=**Q3_GATE** (R13/C4), S=GND, D=LATCH_SET (Release bei BUSY HIGH)
```

## Layout-Feinschliff (01.08.2026)

Bauteile/Bahnen leicht verschoben (keine BOM-/Netzänderung):

| Ref | Anpassung |
|-----|---|
| Q6, R9, R10, R11, D14 | Cluster ~0,5 mm / +1,5 mm |
| C3, R5, D10 | 5 V-Bereich / Freilauf neu ausgerichtet |
| TP2, TP3 | 5 V / GND Testpunkte nachgezogen |

## Steckverbinder → MPT-Schraubklemmen (E-CONN-01)

| Ref | Alt | Neu (Footprint) |
|-----|-----|---|
| J1, J2, J6 | PinHeader 1×02 | `TerminalBlock_Phoenix_MPT-0,5-2-2.54_1x02_…` |
| J3, J4 | PinHeader 1×08 | `TerminalBlock_Phoenix_MPT-0,5-8-2.54_1x08_…` |

Pad-1-Position und Netze beibehalten (Körper größer als Stiftleiste).  
Script: `hardware/replace_connectors_mpt.py`

### Kabelrichtung (Drahtöffnung)

| Ref | Rotation | Kabeleinführung |
|-----|---|---|
| J1, J2, J4, J6 | 0° | von **unten** (Platinenrand +Y) |
| **J3** | **180°** | von **oben** (weg von U2); Netze IO0…IO7 an gleicher XY-Position; Pinnummern im Schaltplan gespiegelt |

Script: `hardware/orient_mpt_j3.py`

Simulation: `simulation/pcb_layout.json` / `pcb_tracks.json`.  
DRC: **0 Fehler / 0 unverbunden** (Respin); Warnungen: U2 lib_mismatch, Silkscreen.

## Fertigungspaket

**Rev 2.5 Fertigpaket** — Gerber, BOM, CPL, PDFs (Export 03.08.2026). Siehe `README.md`.

## Silkscreen-Titel (über Kübler J5)

Drei Zeilen auf **F.SilkS**, zentriert oberhalb J5:

```
Soundplatine Waldlehrpfad
Kolping Alteglofsheim
Konrad Senn 2026
```

Script: `hardware/add_silk_title.py`

## Öffnen / Export

1. Projekt öffnen → `vogelstimmen_v2.5.kicad_pro` (Schaltplan + PCB)
2. Nach Layout-Änderungen Simulation aktualisieren:
   - `python simulation/tools/export_layout.py` (KiCad-Python)
   - `python simulation/tools/export_tracks.py`

## Script

`hardware/make_v24_latch_pfet.py` (initialer Q6-Cluster)

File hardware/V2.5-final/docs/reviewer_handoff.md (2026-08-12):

# Reviewer-Handoff — vor Fertigung (Rev 2.5)

**Datum:** 3. August 2026  
**Projekt:** Soundplatine Waldlehrpfad · Kolping Alteglofsheim · Konrad Senn  
**Ziel dieses Pakets:** Design-Review und Freigabe **vor** JLCPCB-/Teilebestellung (Anforderung **M04**).

---

## 1. Auftrag an den Reviewer

Bitte prüfen und mit Signatur in [`review_checkliste_m04.md`](review_checkliste_m04.md) abschließen:

1. Architektur und Strompfade (Latch Idle ≈0 µA, Kaltstart Q6, BUSY-Release)
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

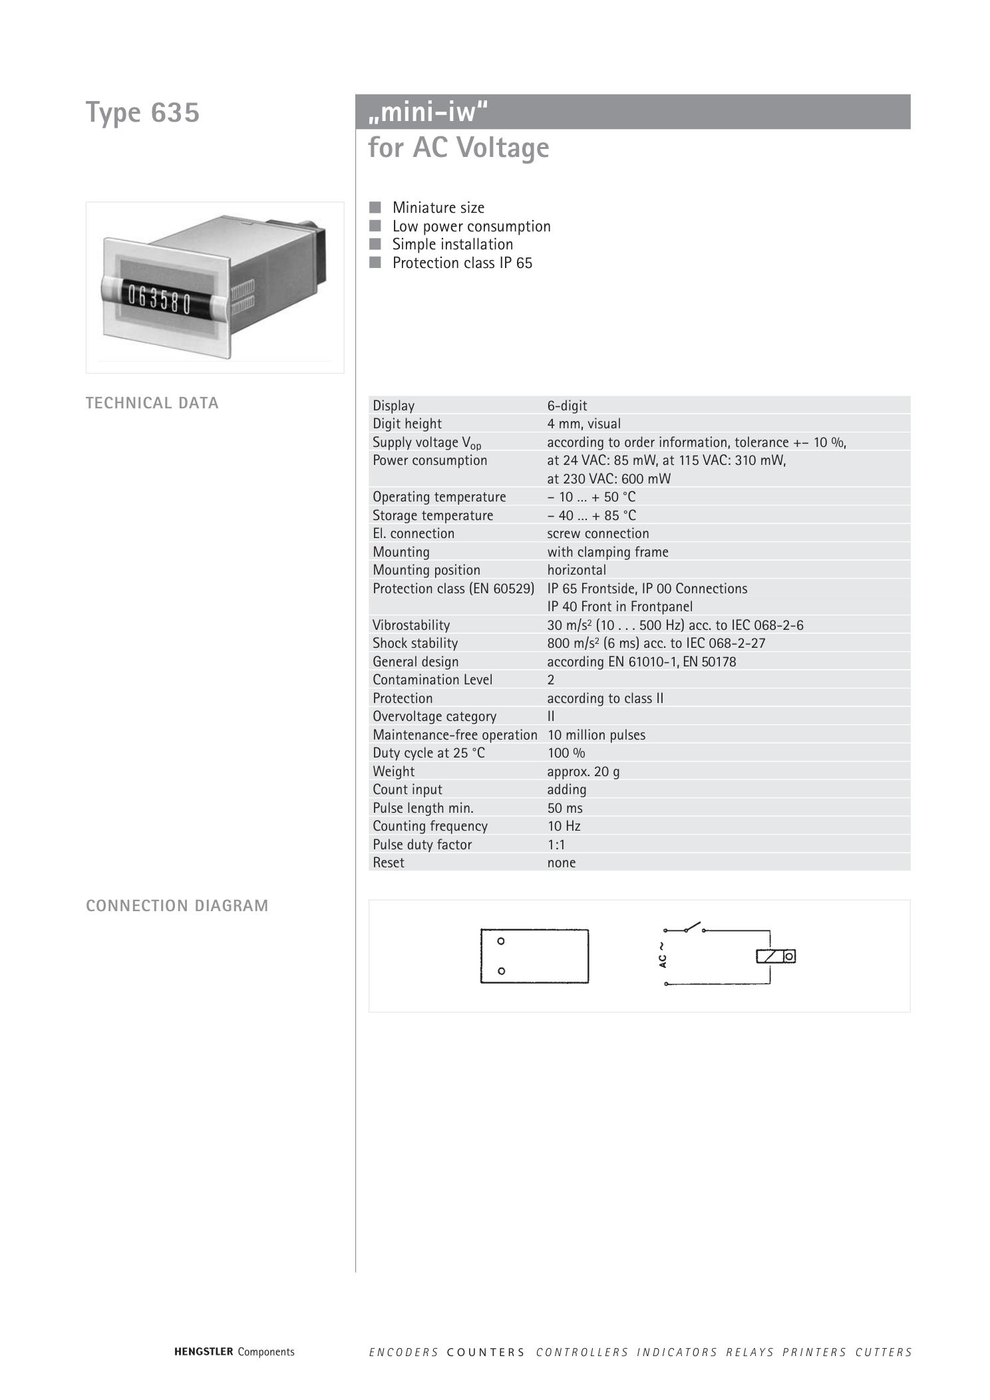
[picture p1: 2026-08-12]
hardware/V3.0/docs/Hengstler_634_635.pdf_3.png

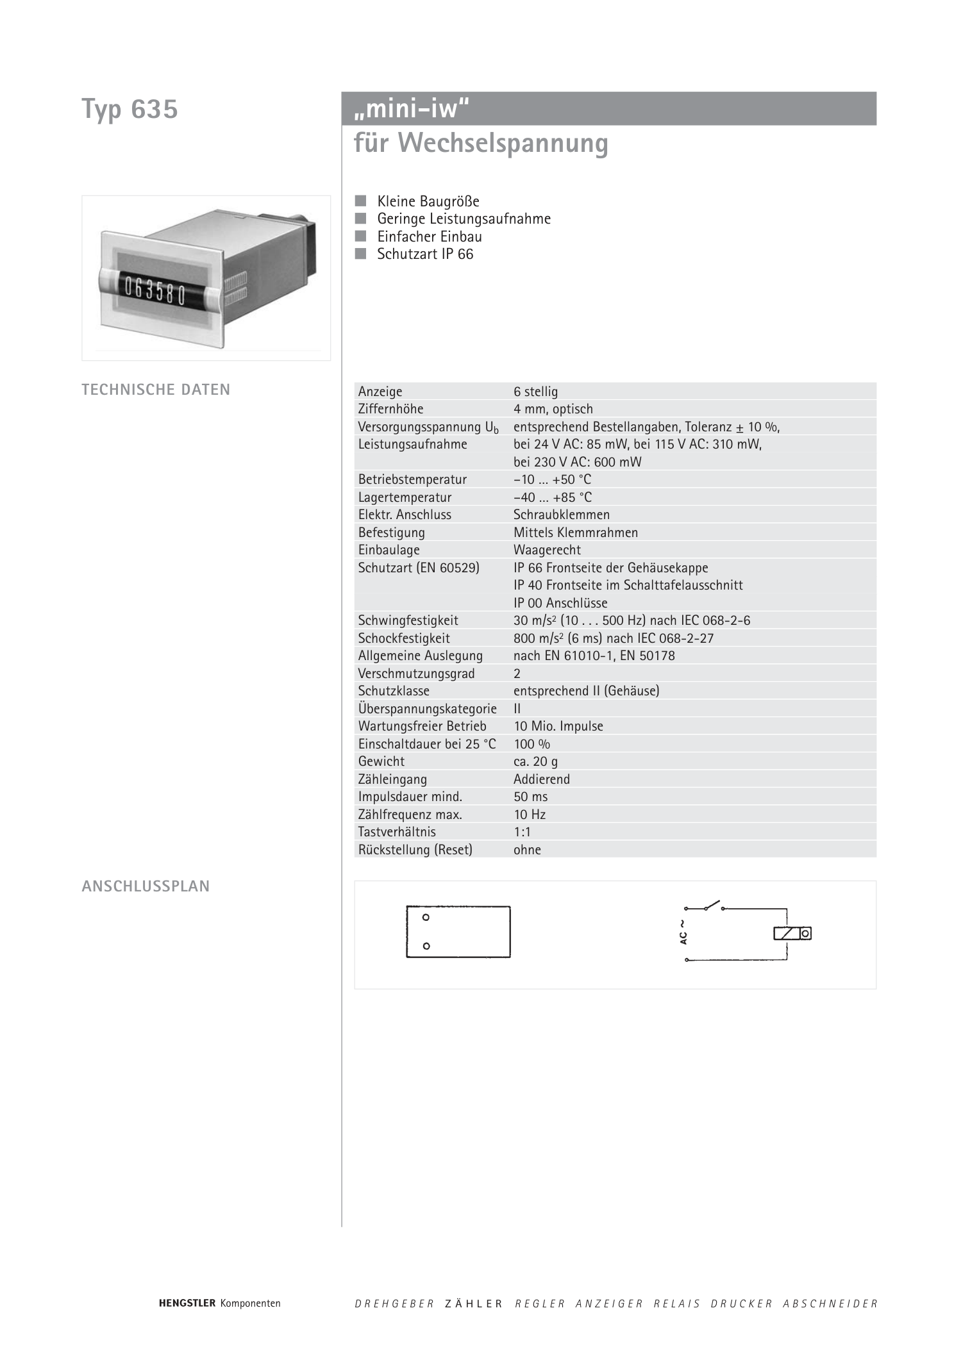
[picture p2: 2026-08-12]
hardware/V3.0/docs/Hengstler_634_635_de.pdf_3.png

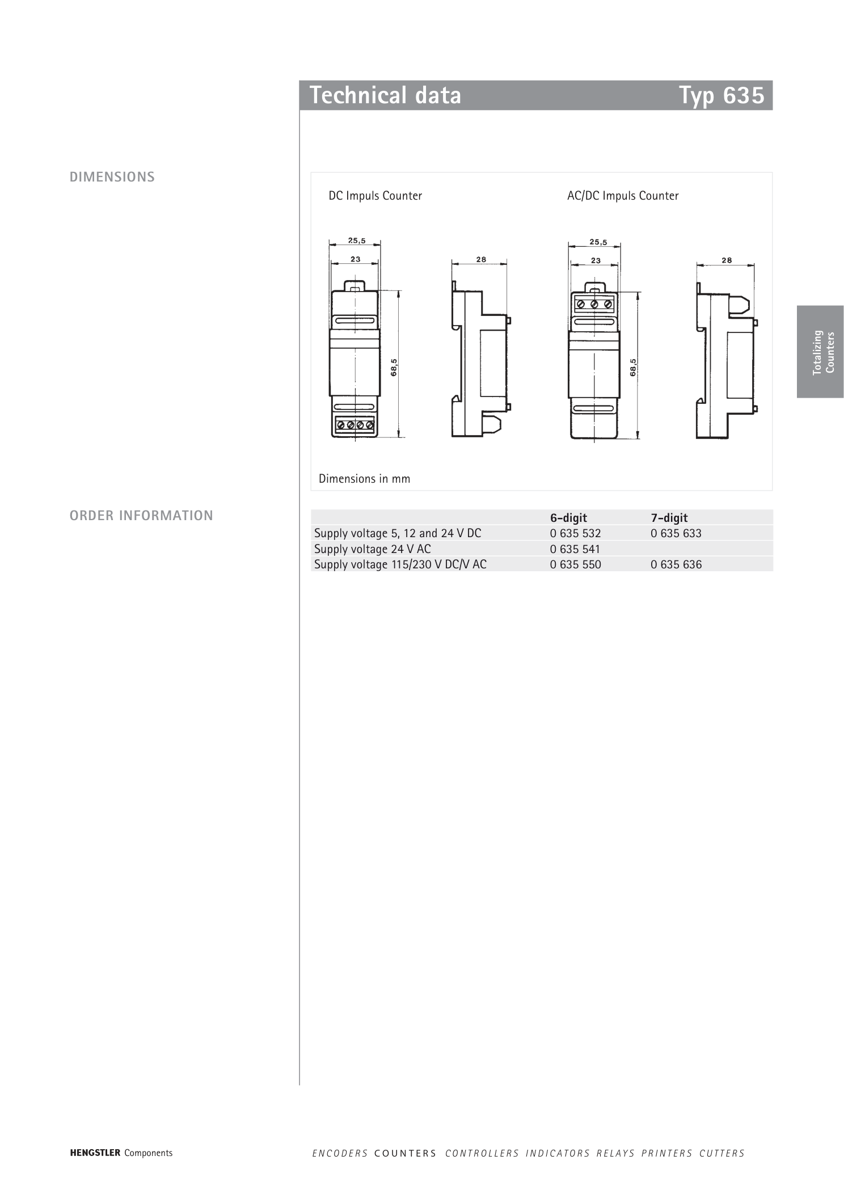
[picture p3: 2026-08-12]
hardware/V3.0/docs/Hengstler_634_635.pdf_6.png

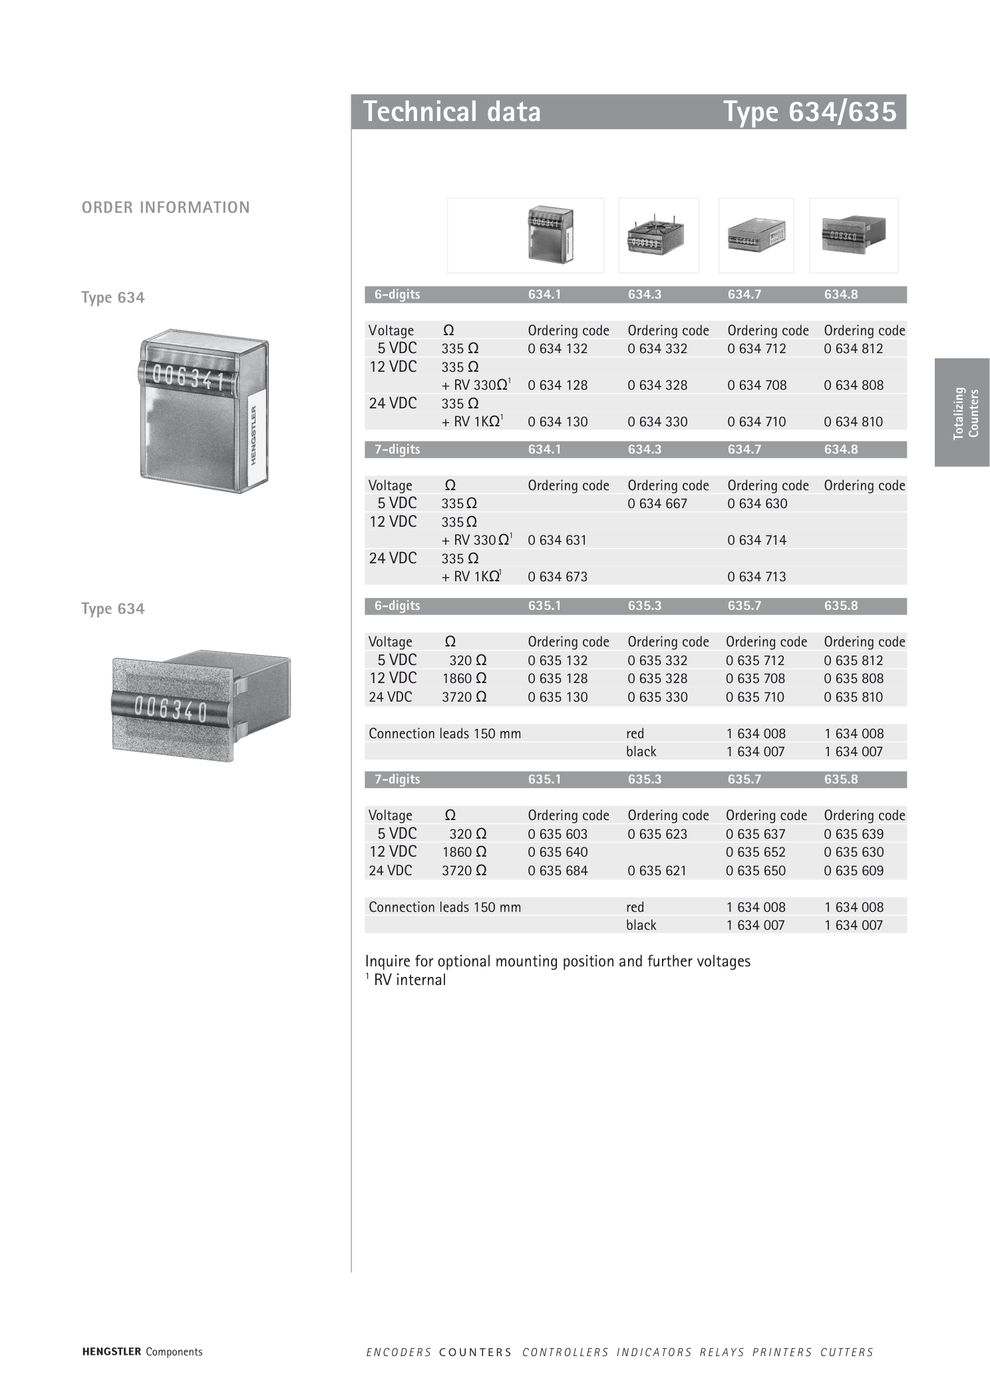
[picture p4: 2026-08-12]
hardware/V3.0/docs/Hengstler_634_635.pdf_2.png

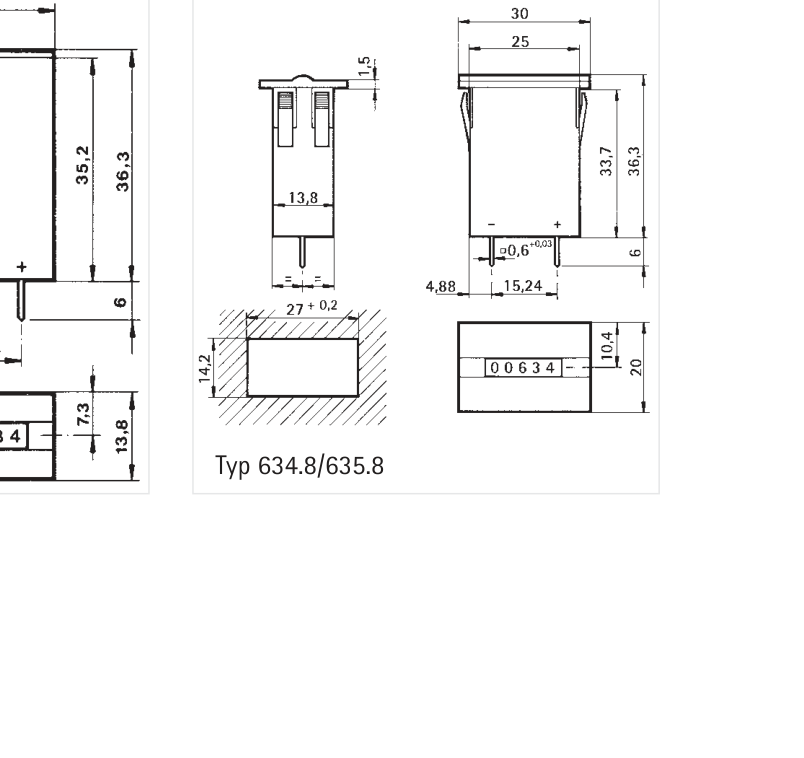
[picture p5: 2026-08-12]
hardware/V3.0/docs/h635_crop_anschluss.png

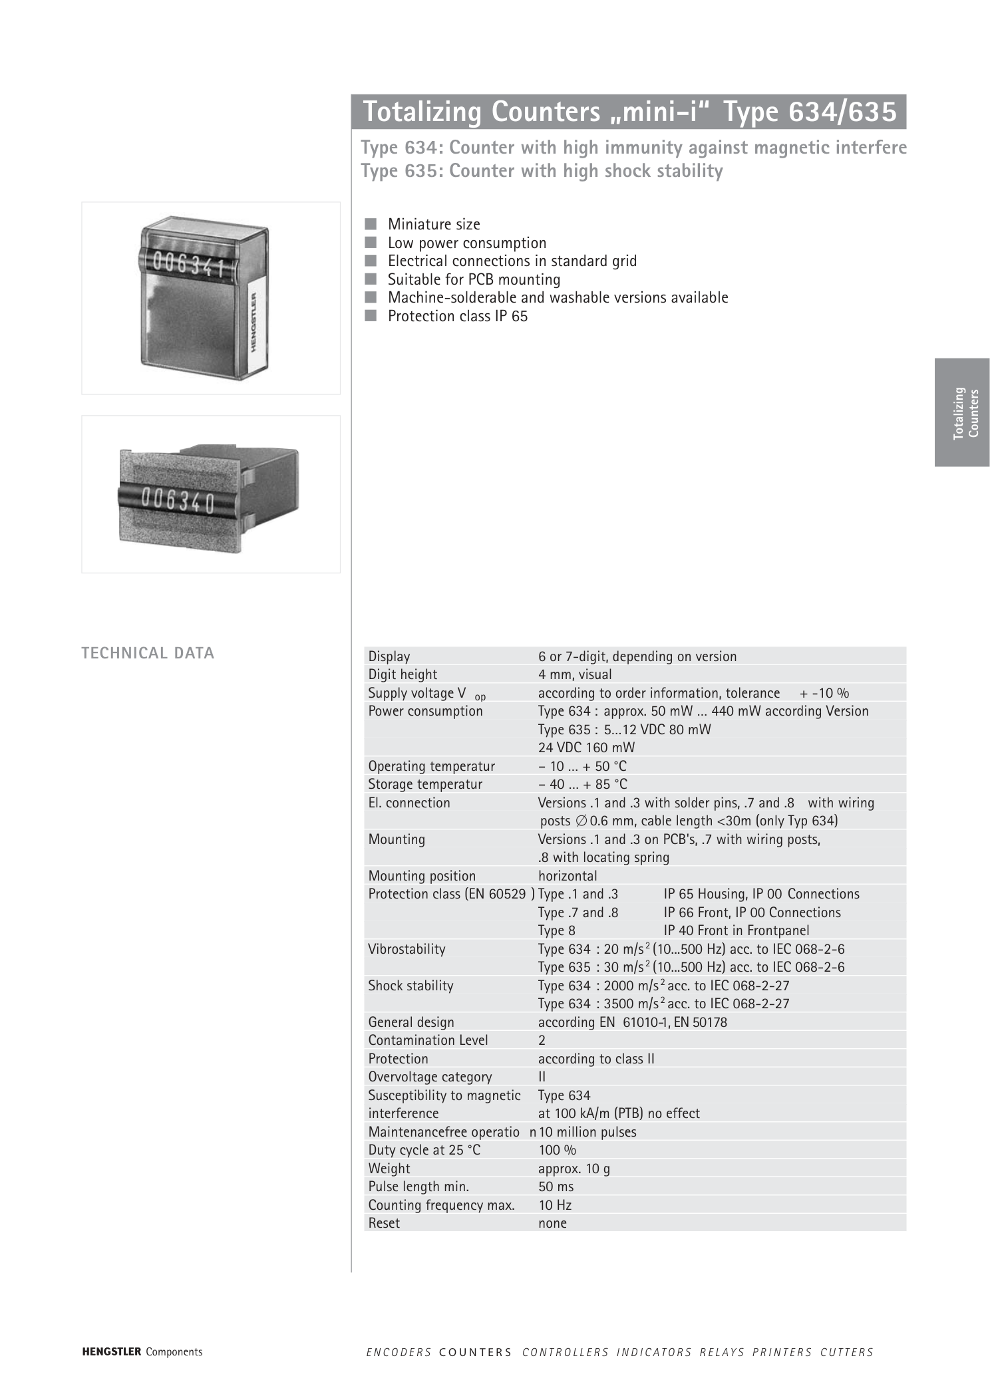
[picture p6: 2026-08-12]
hardware/V3.0/docs/Hengstler_634_635.pdf_0.png

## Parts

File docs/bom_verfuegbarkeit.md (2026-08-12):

# BOM-Verfügbarkeitsprüfung LCSC/JLCPCB

**Datum:** 3. August 2026  
**Status:** Respin F-01…F-05; Working-BOM `hardware/2.final/JLCPCB_BOM.csv`

## Ergebnis: Alle SMD-Kernbauteile verfügbar

| Ref | Bauteil | LCSC # | Bestand (ca.) | Status |
|-----|---|---|---|---|
| Q5, Q1, Q6 | SI2301CDS (P-FET) | C10487 | ~326k | OK |
| D11, D12, D14 | BZX84C6V2 | C179522 | ~1 360 | OK |
| Q2, Q3 | 2N7002LT1G | C16338 | ~463k | OK |
| U1 | TPS62163DSGR | C97534 | ~510 | OK — Reserve |
| D9 | SMAJ15A | C113958 | ~52k | OK |
| **D1–D8, D10, D13, D15–D22** | 1N4148WS | C118873 | ~68k | OK (18×) |
| F1 | PTC 1A/24V | C2760272 | ~14k | OK |
| L1 | 2,2µH TDK 1008 | C88527 | ~2 120 | OK |
| C1, C2 | 10µF/25V 0805 | Standard | >100k | OK |
| C3 | 22µF/10V 0805 | Standard | >100k | OK |
| **C4** | **4,7µF/16V 0805** | Standard | >100k | OK |
| R1, R2, **R13** | 100kΩ 0402 | Standard | >1M | OK |
| **R5** | **0Ω 0402** | Standard | >1M | OK |
| R3, R4, R9 | 10kΩ 0402 | Standard | >1M | OK |
| R6 | 470kΩ 0402 | Standard | >1M | OK |
| R7, R8, R11 | 4,7kΩ 0402 | Standard | >1M | OK |
| R10 | 1kΩ 0402 | Standard | >1M | OK |
| **R12** | **10Ω 0402** | Standard | >1M | OK |

**Geschätzter SMD-Materialpreis:** ~$3,00–3,50 (39 Bauteile)

## Respin-Ergänzungen (F-01…F-05)

| Ref | Wert | LCSC-Hinweis |
|-----|---|---|
| D15–D22 | 1N4148WS | wie D1–D8, C118873 |
| R5 | 0Ω | Jumper-0402 oder 0Ω-Reel |
| R13 | 100kΩ | Standard |
| C4 | 4,7µF/16V 0805 | X7R |
| R12 | 10Ω | Standard |

## Empfohlene LCSC-Bestell-Liste (aktualisiert)

| LCSC # | Bauteil | Menge |
|---|---|---|
| C10487 | SI2301 P-FET | 3 +1 |
| C179522 | BZX84C6V2 | 3 +1 |
| C16338 | 2N7002 | 2 +1 |
| C97534 | TPS62163 | 1 +1 |
| C113958 | SMAJ15A | 1 +1 |
| **C118873** | **1N4148WS** | **18 +4** |
| C2760272 | PTC 1A/24V | 1 +1 |
| C88527 | 2,2µH | 1 +1 |
| — | 10µF/25V 0805 | 2 +2 |
| — | 22µF/10V 0805 | 1 +1 |
| — | **4,7µF/16V 0805** | **1 +1** |
| — | 100kΩ 0402 | 3 +3 |
| — | **0Ω 0402** | **1 +5** |
| — | 10kΩ 0402 | 3 +3 |
| — | 470kΩ 0402 | 1 +1 |
| — | 4,7kΩ 0402 | 3 +2 |
| — | 1kΩ 0402 | 1 +1 |
| — | **10Ω 0402** | **1 +5** |

## Nicht in JLCPCB-BOM (Handbestückung)

Stehen **nicht** in der SMT-BOM. Liste: `hardware/V2.5-final/HAND_BESTUECKUNG.csv`.

| Bauteil | Quelle | Assembly |
|---|---|---|
| DY-SV17F U2 | AliExpress / eBay | HAND |
| Hengstler 0.635.128 | Fachhandel (Mercateo/RS/Farnell) | HAND — siehe V3.0 |
| ~~Kübler 1.130.900.008~~ | — | gestrichen E-CNT-02 |
| Phoenix MPT Klemmen J1–J6 | Phoenix / Reichelt | HAND |
| TP1–TP5 Testpads | — | DNP |
| Metzler-Taster P19-TF-W (Gehäuse) | Amazon B01HQDH2OK | extern / Bestand |

| Datei | Inhalt |
|---|---|
| `hardware/V2.5-final/JLCPCB_BOM.csv` | nur SMT (`Mount=SMT`) |
| `hardware/V2.5-final/HAND_BESTUECKUNG.csv` | nur HAND / DNP |

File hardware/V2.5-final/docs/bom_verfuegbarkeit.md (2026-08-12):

# BOM-Verfügbarkeitsprüfung LCSC/JLCPCB

**Datum:** 3. August 2026  
**Status:** Rev 2.5 · Respin F-01…F-05 + GND-Vias; BOM `JLCPCB_BOM.csv`

## Ergebnis: Alle SMD-Kernbauteile verfügbar

| Ref | Bauteil | LCSC # | Bestand (ca.) | Status |
|-----|---|---|---|---|
| Q5, Q1, Q6 | SI2301CDS (P-FET) | C10487 | ~326k | OK |
| D11, D12, D14 | BZX84C6V2 | C179522 | ~1 360 | OK |
| Q2, Q3 | 2N7002LT1G | C16338 | ~463k | OK |
| U1 | TPS62163DSGR | C97534 | ~510 | OK — Reserve |
| D9 | SMAJ15A | C113958 | ~52k | OK |
| **D1–D8, D10, D13, D15–D22** | 1N4148WS | C118873 | ~68k | OK (18×) |
| F1 | PTC 1A/24V | C2760272 | ~14k | OK |
| L1 | 2,2µH TDK 1008 | C88527 | ~2 120 | OK |
| C1, C2 | 10µF/25V 0805 | Standard | >100k | OK |
| C3 | 22µF/10V 0805 | Standard | >100k | OK |
| **C4** | **4,7µF/16V 0805** | Standard | >100k | OK |
| R1, R2, **R13** | 100kΩ 0402 | Standard | >1M | OK |
| **R5** | **0Ω 0402** | Standard | >1M | OK |
| R3, R4, R9 | 10kΩ 0402 | Standard | >1M | OK |
| R6 | 470kΩ 0402 | Standard | >1M | OK |
| R7, R8, R11 | 4,7kΩ 0402 | Standard | >1M | OK |
| R10 | 1kΩ 0402 | Standard | >1M | OK |
| **R12** | **10Ω 0402** | Standard | >1M | OK |

**Geschätzter SMD-Materialpreis:** ~$3,00–3,50 (39 Bauteile)

## Respin-Ergänzungen (F-01…F-05)

| Ref | Wert | LCSC-Hinweis |
|-----|---|---|
| D15–D22 | 1N4148WS | wie D1–D8, C118873 |
| R5 | 0Ω | Jumper-0402 oder 0Ω-Reel |
| R13 | 100kΩ | Standard |
| C4 | 4,7µF/16V 0805 | X7R |
| R12 | 10Ω | Standard |

## Empfohlene LCSC-Bestell-Liste (aktualisiert)

| LCSC # | Bauteil | Menge |
|---|---|---|
| C10487 | SI2301 P-FET | 3 +1 |
| C179522 | BZX84C6V2 | 3 +1 |
| C16338 | 2N7002 | 2 +1 |
| C97534 | TPS62163 | 1 +1 |
| C113958 | SMAJ15A | 1 +1 |
| **C118873** | **1N4148WS** | **18 +4** |
| C2760272 | PTC 1A/24V | 1 +1 |
| C88527 | 2,2µH | 1 +1 |
| — | 10µF/25V 0805 | 2 +2 |
| — | 22µF/10V 0805 | 1 +1 |
| — | **4,7µF/16V 0805** | **1 +1** |
| — | 100kΩ 0402 | 3 +3 |
| — | **0Ω 0402** | **1 +5** |
| — | 10kΩ 0402 | 3 +3 |
| — | 470kΩ 0402 | 1 +1 |
| — | 4,7kΩ 0402 | 3 +2 |
| — | 1kΩ 0402 | 1 +1 |
| — | **10Ω 0402** | **1 +5** |

## Nicht in JLCPCB-BOM (Handbestückung)

Diese Teile stehen **nicht** in `JLCPCB_BOM.csv` / CPL. Liste: **`HAND_BESTUECKUNG.csv`**.

| Bauteil | Quelle | Assembly |
|---|---|---|
| DY-SV17F U2 | AliExpress / eBay | HAND |
| Kübler 1.130.900.008 | Fachhandel | HAND |
| Phoenix MPT Klemmen J1–J6 | Phoenix / Reichelt | HAND |
| TP1–TP5 Testpads | — | DNP |
| Metzler-Taster P19-TF-W (Gehäuse) | Amazon B01HQDH2OK | extern / Bestand |

| Datei | Inhalt |
|---|---|
| `JLCPCB_BOM.csv` | nur SMT (`Mount=SMT`) |
| `HAND_BESTUECKUNG.csv` | nur HAND / DNP |

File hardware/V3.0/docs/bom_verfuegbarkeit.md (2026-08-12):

# BOM-Verfügbarkeit Rev 3.0 — Package-geprüft

**Härte-Regel vor Bestellung:** Auf der LCSC/JLCPCB-Seite muss **Package** exakt dem Footprint entsprechen.

## SMT — JLCPCB Basic Widerstände (0603)

| Ref | Wert | Footprint | LCSC | Package | Library |
|-----|---|---|---|---|---|
| R1,R2,R13,R20 | 100k | 0603 | **C25803** | 0603 | Basic |
| R3,R4,R9 | 10k | 0603 | **C25804** | 0603 | Basic |
| R5 | 0R | 0603 | **C21189** | 0603 | Basic |
| R6 | 470k | 0603 | **C23178** | 0603 | Basic |
| R7,R8,R11 | 4.7k | 0603 | **C23162** | 0603 | Basic |
| R10 | 1k | 0603 | **C21190** | 0603 | Basic |
| R12 | 10R | 0603 | **C22859** | 0603 | Basic |
| R21 | 100R | 0603 | **C25796** | 0603 | Basic |

## SMT — One-Shot Zähler (E-CNT-03)

| Ref | Teil | Footprint | LCSC | Package |
|-----|---|---|---|---|
| C20 | 1 µF/25 V | 0603 | **C23630** | 0603 Basic |
| Q7 | AO3400 N-MOS | SOT-23 | **C20917** | SOT-23 Basic |
| D23 | 1N4148WS | SOD-323 | **C118873** | (wie D10) |

## Zähler (Hand)

| Priorität | Teil | Größe | Bezug |
|---|---|---|---|
| **1** | **Hengstler 0.635.128** (Typ 635.1, 12 V PCB) | Body **25,2×31 mm**, Pins 15,24×25,4 | Mercateo / RS / Farnell |
| — | 0.635.132 (5 V) | — | **nicht** (Buck-Race) |
| — | CSK / 875 Panel | ~46×74 mm | **gestrichen** |

J5 = Footprint `CNT_HENGSTLER_635`, Pitch 15,24 mm. One-Shot auf der Platine.

## Checkliste vor JLCPCB-Upload

- [x] Gerber.zip + CPL aus **V3.0** exportiert (`vogelstimmen_v3.0-Gerber.zip`)
- [x] Widerstände: PCB = **R_0603_1608Metric**, Pitch 1,65 mm (kein 0402)
- [ ] Jede LCSC-Seite: Package == Footprint (Parts Matching im JLCPCB-Upload)
- [ ] Parts Matching: 0× „Soldering area too small“
- [ ] **Hengstler 0.635.128** parallel bestellt (Lieferzeit oft Wochen)
- [ ] MPT-Klemmen + DY-SV17F parallel bestellt
- [x] DRC: 0 open / 0 short (`DRC_v3.0_final.rpt`)

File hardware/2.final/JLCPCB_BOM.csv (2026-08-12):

Comment | Designator | Footprint | LCSC Part # | Qty | Notes
10uF/25V 0805 | C1,C2 | C_0805_2012Metric |  | 2 | X7R; JLCPCB basic pick
22uF/10V 0805 | C3 | C_0805_2012Metric |  | 1 | X7R; JLCPCB basic pick
4.7uF/16V 0805 | C4 | C_0805_2012Metric |  | 1 | Q3 gate blanking F-03
1N4148WS | D1-D8,D10,D13,D15-D22 | D_SOD-323 | C118873 | 18 | D15-D22 series U2 IOx F-01
SMAJ15A | D9 | D_SMA | C113958 | 1 | TVS 15V uni
BZX84C6V2 | D11,D12,D14 | SOT-23 | C179522 | 3 | VGS clamp 6.2V
PTC 1A/24V 1206 | F1 | Fuse_1206_3216Metric | C2760272 | 1 | not C20800 (6V)
2.2uH 1008 | L1 | L_1008_2520Metric | C88527 | 1 | TDK VLS252010HBX-2R2M-1
SI2301CDS | Q1,Q5,Q6 | SOT-23 | C10487 | 3 | P-FET
2N7002LT1G | Q2,Q3 | SOT-23 | C16338 | 2 | N-FET latch
100k 0402 | R1,R2,R13 | R_0402_1005Metric |  | 3 | R13 BUSY blanking F-03
0R 0402 | R5 | R_0402_1005Metric |  | 1 | VOS sense F-02
10k 0402 | R3,R4,R9 | R_0402_1005Metric |  | 3 | basic
10 0402 | R12 | R_0402_1005Metric |  | 1 | J6 LED series F-04
470k 0402 | R6 | R_0402_1005Metric |  | 1 | Q5 gate pulldown E-RPP-01
4.7k 0402 | R7,R8,R11 | R_0402_1005Metric |  | 3 | VGS series
1k 0402 | R10 | R_0402_1005Metric |  | 1 | basic
TPS62163DSGR | U1 | WSON-8-1EP_2x2mm | C97534 | 1 | order spare (stock limited)

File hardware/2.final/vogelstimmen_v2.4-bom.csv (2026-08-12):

Designator | Comment | Footprint | Qty | LCSC Part # | MPN | Manufacturer | Datasheet | Description
C1,C2 | 10u/25V | Capacitor_SMD:C_0805_2012Metric | 2 |  |  |  |  | Unpolarized capacitor
C3 | 22u/10V | Capacitor_SMD:C_0805_2012Metric | 1 |  |  |  |  | Unpolarized capacitor
C4 | 4.7u/16V | Capacitor_SMD:C_0805_2012Metric | 1 |  |  |  |  | Q3 gate blanking (F-03)
D1-D8,D10,D15-D22 | 1N4148WS | Diode_SMD:D_SOD-323 | 17 | C118873 |  |  |  | Diode; D15-D22 series U2 IOx (F-01)
D9 | SMAJ15A | Diode_SMD:D_SMA | 1 | C113958 |  |  |  | Bidirectional transient-voltage-suppression diode
D11,D12,D14 | BZX84C6V2 | vogelstimmen:BZX84C6V2 | 3 | C179522 |  |  | https://www.lcsc.com/product-detail/C179522.html | VGS clamp Q6 SET P-FET; K=12V_PROT A=Q6_GATE,Zener 6.2V VGS clamp for SI2301; K=Source A=Gate
D13 | 1N4148WS | Diode_SMD:D_SOD-323 | 1
F1 | 1A/24V | Fuse:Fuse_1206_3216Metric | 1 | C2760272 |  |  |  | Resettable fuse, polymeric positive temperature coefficient
J1 | J_BAT | TerminalBlock_Phoenix:TerminalBlock_Phoenix_MPT-0,5-2-2.54_1x02_P2.54mm_Horizontal | 1 |  |  |  |  | Generic connector, single row, 01x02, script generated (kicad-library-utils/schlib/autogen/connector/)
J2 | J_SPK | TerminalBlock_Phoenix:TerminalBlock_Phoenix_MPT-0,5-2-2.54_1x02_P2.54mm_Horizontal | 1 |  |  |  |  | Generic connector, single row, 01x02, script generated (kicad-library-utils/schlib/autogen/connector/)
J3 | J_BTN_IO | TerminalBlock_Phoenix:TerminalBlock_Phoenix_MPT-0,5-8-2.54_1x08_P2.54mm_Horizontal | 1 |  |  |  |  | Generic connector, single row, 01x08, script generated (kicad-library-utils/schlib/autogen/connector/)
J4 | J_BTN_GND | TerminalBlock_Phoenix:TerminalBlock_Phoenix_MPT-0,5-8-2.54_1x08_P2.54mm_Horizontal | 1 |  |  |  |  | Generic connector, single row, 01x08, script generated (kicad-library-utils/schlib/autogen/connector/)
J5 | K07.90 | vogelstimmen:K07.90 | 1 |  |  |  | docs/datasheets/Kuebler_K04-K07_AK07.pdf | Kübler K07.90; Bestellnr 1.130.900.008 (4.5V DC 10Hz) an 5V; Alt 1.130.900.012 (12V)
J6 | J_LED | TerminalBlock_Phoenix:TerminalBlock_Phoenix_MPT-0,5-2-2.54_1x02_P2.54mm_Horizontal | 1 |  |  |  |  | Generic connector, single row, 01x02, script generated (kicad-library-utils/schlib/autogen/connector/)
L1 | 2.2uH | Inductor_SMD:L_1008_2520Metric | 1 | C88527 |  |  |  | Inductor
Q1,Q5 | SI2301 | Package_TO_SOT_SMD:SOT-23 | 2 | C10487 |  |  | http://assets.nexperia.com/documents/data-sheet/BSS84.pdf | -0.13A Id, -50V Vds, P-Channel MOSFET, SOT-23
Q2,Q3 | 2N7002 | Package_TO_SOT_SMD:SOT-23 | 2 | C16338 |  |  | https://www.onsemi.com/pub/Collateral/NDS7002A-D.PDF | 0.115A Id, 60V Vds, N-Channel MOSFET, SOT-23
Q6 | SI2301 | Package_TO_SOT_SMD:SOT-23 | 1
R1,R2,R13 | 100k | Resistor_SMD:R_0402_1005Metric | 3 |  |  |  |  | Resistor; R13 BUSY blanking (F-03)
R5 | 0R | Resistor_SMD:R_0402_1005Metric | 1 |  |  |  |  | VOS sense link (F-02)
R3,R4,R9 | 10k | Resistor_SMD:R_0402_1005Metric | 3 |  |  |  |  | Resistor
R12 | 10 | Resistor_SMD:R_0402_1005Metric | 1 |  |  |  |  | J6 LED series (F-04)
R6 | 470k | Resistor_SMD:R_0402_1005Metric | 1 |  |  |  |  | Resistor
R7,R8,R11 | 4.7k | Resistor_SMD:R_0402_1005Metric | 3 |  |  |  |  | Gate series resistor for VGS zener clamp,Q6 gate series for VGS clamp
R10 | 1k | Resistor_SMD:R_0402_1005Metric | 1
TP1 | 12V_PROT | TestPoint:TestPoint_Pad_D1.0mm | 1 |  |  |  |  | Generic connector, single row, 01x01, script generated (kicad-library-utils/schlib/autogen/connector/)
TP2 | 5V | TestPoint:TestPoint_Pad_D1.0mm | 1 |  |  |  |  | Generic connector, single row, 01x01, script generated (kicad-library-utils/schlib/autogen/connector/)
TP3 | GND | TestPoint:TestPoint_Pad_D1.0mm | 1 |  |  |  |  | Generic connector, single row, 01x01, script generated (kicad-library-utils/schlib/autogen/connector/)
TP4 | BUSY | TestPoint:TestPoint_Pad_D1.0mm | 1 |  |  |  |  | Generic connector, single row, 01x01, script generated (kicad-library-utils/schlib/autogen/connector/)
TP5 | SPK+ | TestPoint:TestPoint_Pad_D1.0mm | 1 |  |  |  |  | Generic connector, single row, 01x01, script generated (kicad-library-utils/schlib/autogen/connector/)
U1 | TPS62163 | Package_SON:WSON-8-1EP_2x2mm_P0.5mm_EP0.9x1.6mm | 1 | C97534 |  |  | https://www.ti.com/lit/ds/symlink/tps62163.pdf | 1A Step-Down Converter, Fixed 5V Output, WSON-8
U2 | DY-SV17F | vogelstimmen:DY-SV17F | 1 |  |  |  |  | MP3/WAV Audio Module with 8 IO triggers, 5W Class-D amp, USB

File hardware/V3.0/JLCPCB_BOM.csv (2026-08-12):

Comment | Designator | Footprint | LCSC Part #
10uF/25V 0805 | C1,C2 | C_0805_2012Metric | C440198
22uF/10V 0805 | C3 | C_0805_2012Metric | C45783
4.7uF/16V 0805 | C4 | C_0805_2012Metric | C1779
1uF/25V 0603 Basic | C20 | C_0603_1608Metric | C23630
1N4148WS | D1,D2,D3,D4,D5,D6,D7,D8,D10,D13,D15,D16,D17,D18,D19,D20,D21,D22,D23 | D_SOD-323 | C118873
SMAJ15A | D9 | D_SMA | C113958
BZX84C6V2 | D11,D12,D14 | SOT-23 | C179522
PTC 1A/24V 1206 | F1 | Fuse_1206_3216Metric | C2760272
2.2uH 1008 | L1 | L_1008_2520Metric | C88527
SI2301CDS | Q1,Q5,Q6 | SOT-23 | C10487
2N7002LT1G | Q2,Q3 | SOT-23 | C16338
AO3400 | Q7 | SOT-23 | C20917
100k 0603 Basic | R1,R2,R13,R20 | R_0603_1608Metric | C25803
0R 0603 Basic | R5 | R_0603_1608Metric | C21189
10k 0603 Basic | R3,R4,R9 | R_0603_1608Metric | C25804
10R 0603 Basic | R12 | R_0603_1608Metric | C22859
100R 0603 Basic | R21 | R_0603_1608Metric | C25796
470k 0603 Basic | R6 | R_0603_1608Metric | C23178
4.7k 0603 Basic | R7,R8,R11 | R_0603_1608Metric | C23162
1k 0603 Basic | R10 | R_0603_1608Metric | C21190
TPS62163DSGR | U1 | WSON-8-1EP_2x2mm | C97534

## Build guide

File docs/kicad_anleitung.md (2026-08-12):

# KiCad 10 — Schaltplan mit Net-Labels (fertig verdrahtet)

**Stand:** Alle 105 Net-Labels und 3 No-Connect-Flags sind programmatisch in
`hardware/vogelstimmen_v2.4.kicad_sch` (Projekt `vogelstimmen_v2.4.kicad_pro`). Die Verdrahtung ist vollständig.

---

## Phase 1: Projekt öffnen und Symbole laden

1. **KiCad 10 → Datei → Projekt öffnen**
   → `C:\Users\Schue\Projects\Vogelstimmen\hardware\vogelstimmen_v2.kicad_pro`

2. **Schaltplaneditor** öffnen (Doppelklick auf `.kicad_sch` oder links oben)

3. Falls KiCad einen **"Rescue Symbols"** Dialog zeigt:
   → **Alle bestätigen / akzeptieren**

4. Falls Symbole als **"?"** angezeigt werden:
   → Menü: **Werkzeuge → Symbole aus Bibliothek aktualisieren**
   → Haken bei "Alle" → OK

5. Die Custom-Symbole (DY-SV17F, TPS62163) liegen in
   `hardware/symbols/vogelstimmen.kicad_sym`, referenziert über
   `hardware/sym-lib-table`.

---

## Phase 2: Visuelle Prüfung

Nach dem Öffnen sollten alle Bauteile Labels an ihren Pins haben.
Prüfe visuell ob die Labels korrekt an den Pin-Endpunkten sitzen.

### Tastenkürzel
- **Mausrad** = Zoom
- **Mittlere Maustaste halten** = Verschieben
- **E** = Bauteil/Label Eigenschaften bearbeiten
- **M** = Bauteil verschieben
- **R** = Bauteil drehen

### Falls ein Label nicht am Pin sitzt

Das kann passieren wenn die Koordinatenberechnung für Rotation/Mirror
leicht abweicht. Lösung:

1. Label anklicken → **M** drücken → auf den Pin-Endpunkt schieben
2. Oder: Label löschen, **L** drücken, gleichen Netznamen eingeben,
   am Pin-Endpunkt platzieren

---

## Phase 3: ERC laufen lassen

1. Menü: **Überprüfen → Electrical Rules Check** (Käfer-Symbol)
2. **ERC starten**
3. Erwartete Ergebnisse:

### Bekannte ERC-Fehler und Lösung

KiCad meldet "Input Power pin not driven" wenn ein Power-Pin keinen
expliziten Power-Ausgang im Netz hat. Lösung: **PWR_FLAG** platzieren.

| ERC-Fehler | Betroffener Pin | PWR_FLAG an Netz |
|---|---|---|
| U1 Pin 2 (VIN) not driven | TPS62163 VIN | **12V_SW** |
| U1 Pin 1 (PGND) not driven | TPS62163 PGND | **GND** |
| U2 Pin 13 (V5) not driven | DY-SV17F V5 | **5V** |

### PWR_FLAG platzieren (ERC-Pflicht)

Drücke **P**, suche "PWR_FLAG", platziere je einen an:
- Einem **GND**-Knoten (z.B. neben U1)
- Dem **12V_SW**-Netz (z.B. neben U1.VIN)
- Dem **5V**-Netz (z.B. neben U2.V5)

Nach dem Platzieren der 3 PWR_FLAGs: ERC erneut laufen lassen → **0 Fehler**.

---

## Phase 4: Footprints prüfen

Menü: **Werkzeuge → Footprint-Zuweisung bearbeiten**

| Ref | Footprint | Paket |
|-----|---|---|
| Q1, Q5 | Package_TO_SOT_SMD:SOT-23 | SOT-23 |
| Q2, Q3 | Package_TO_SOT_SMD:SOT-23 | SOT-23 |
| R1–R6, **R12, R13** | Resistor_SMD:R_0402_1005Metric | 0402 |
| C1, C2, **C4** | Capacitor_SMD:C_0805_2012Metric | 0805 |
| C3 | Capacitor_SMD:C_0805_2012Metric | 0805 |
| D1–D8, D10, **D15–D22** | Diode_SMD:D_SOD-323 | SOD-323 |
| D9 | Diode_SMD:D_SMA | SMA |
| F1 | Fuse:Fuse_1206_3216Metric | 1206 |
| U1 | Package_SON:WSON-8-1EP_2x2mm_P0.5mm_EP0.9x1.6mm | WSON-8 |
| U2 | *(Stiftleisten 2×9 oder Custom-Footprint)* | THT |
| L1 | Inductor_SMD:L_1008_2520Metric | 1008 |
| J1, J2, J6 | Phoenix MPT-0,5-2-2.54 | THT Schraubklemme |
| J3, J4 | Phoenix MPT-0,5-8-2.54 | THT Schraubklemme |
| TP1–TP5 | TestPoint_Pad_D1.0mm | SMD |

---

## Netzliste — Power + Latch (nach VGS-Update)

| # | Label | Punkte |
|---|---|---|
| 1 | **GND** | … R6↓, Q2.S, Q3.S, … |
| 2 | **BAT+** | J1.1, Q5.S, **D11.K** |
| 3 | **Q5_GATE** | Q5.G, **D11.A**, **R7** |
| 4 | **Q5_G_PD** | R7 andere Seite → **R6** → GND |
| 5 | **RPP_OUT** | Q5.D, F1 |
| 6 | **12V_PROT** | F1, D9, C1, R1, Q1.S, **D12.K**, TP1 |
| 7 | **Q1_GATE** | Q1.G, R1, **D12.A**, **R8** |
| 8 | **LATCH_GATE** | **R8** andere Seite, Q2.D, Q3.D |
| 9 | **12V_SW** | Q1.D, R4, U1, C2, **R12** |
| 10 | **12V_LED** | **R12**, J6.1 |
| 11 | **Q3_GATE** | Q3.G, **R13**, **C4** |
| 12 | **IO0_M…IO7_M** | U2.1–8, **D15–D22** Anode |
| … | (Signalnetze unverändert) | |

### Verdrahtung VGS-Schutz in Eeschema (PCB noch nicht)

**Q5:**
1. Alte direkte Verbindung Gate↔R6 trennen
2. D11: Kathode an BAT+/Q5.Source, Anode an Q5.Gate
3. R7 zwischen Q5.Gate und R6; R6 nach GND

**Q1:**
1. Alte Verbindung Q1.Gate↔Q2.Drain (LATCH_GATE) auftrennen
2. D12: Kathode an 12V_PROT/Q1.Source, Anode an Q1.Gate
3. R8 zwischen Q1.Gate und Q2.Drain (LATCH_GATE); R1 bleibt Pull-up Gate↔12V_PROT

Bauteile D11/D12/R7/R8 sind im Schaltplan bereits angelegt (siehe Textnotiz).  
Details: `docs/digitaler_zwilling.md` · BOM: LCSC **C179522**

### No-Connect Flags (3)

| Pin | Bauteil |
|-----|---|
| DACR (Pin 15) | U2 DY-SV17F |
| DACL (Pin 16) | U2 DY-SV17F |
| PG (Pin 8) | U1 TPS62163 |

---

## Koordinaten-Berechnung (Referenz)

Die Labels wurden mit folgender Formel an den exakten Pin-Endpunkten platziert:

```
Rotation im Symbolraum (gegen Uhrzeigersinn):
  0°:   (px, py) → (px, py)
  90°:  (px, py) → (-py, px)
  180°: (px, py) → (-px, -py)
  270°: (px, py) → (py, -px)

Globale Position:
  Ohne Mirror:  (sx + rx, sy - ry)
  Mit Mirror X: (sx + rx, sy + ry)

sx, sy = Bauteil-Platzierung
px, py = Pin-Position im Symbol (Y-up)
rx, ry = Rotierter Pin-Vektor
```

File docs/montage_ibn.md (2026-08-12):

# Montage & Inbetriebnahme (IBN) — Rev 2.5

**Status:** Arbeitsanweisung Entwurf für Proto / Kleinserie.

---

## 1. Lieferumfang PCB

- SMD von JLCPCB bestückt (laut BOM/CPL)
- Manuell: U2 (DY-SV17F, optional Sockel), J5 Hengstler 0.635.128, J1/J2/J6 MPT 0,5/2, J3/J4 MPT 0,5/8

---

## 2. Montagefolge

1. Sichtprüfung SMD (D15–D22 Polarität, R5=0R, R12, R13, C4)  
2. THT-Klemmen löten (Orientierung: J3 Kabelzugang beachten)  
3. Hengstler J5 (Anzeige zum Sichtfenster; Polarität Pad1=+ / Pad2=−)  
4. Modul U2 auf Sockel / löten  
5. Optional: Conformal Coating (außer Stecker, Sockel, Zählerfenster)  
6. Einbau Gehäuse, M3, Verkabelung ≤30 cm  

---

## 3. IBN-Checkliste (Minimum)

| # | Prüfung | Soll |
|---|---|---|
| 1 | Batterie Polarität J1 | Platine lebt, Idle |
| 2 | Multimeter I_BAT Idle | <100 µA |
| 3 | Taste halten ≥400 ms | Audio + LEDs |
| 4 | Track Ende | Latch aus, Idle wieder |
| 5 | Zähler | +1 pro Session |
| 6 | Retrigger | Stimme wechselt |
| 7 | USB-Regel | nur Latch aus / Modul ab |
| 8 | SPK Verkabelung | BTL, kein GND an SPK− |

Messungen Auflagen: Oszi BUSY/Q3_GATE; R12-Temp; 5 V Last — `vv_testplan.md`.

---

## 4. Fertigungsunterlagen

| Dokument | Ort |
|---|-----|
| Gerber ZIP | `hardware/V2.5-final/` |
| BOM / CPL | dasselbe |
| JLCPCB README | `hardware/V2.5-final/README.md` |

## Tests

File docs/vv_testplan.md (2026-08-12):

# Verifikation & Validierung — Testplan Rev 2.5

**V-Modell rechts:** Unit → Integration → Teilsystem → System → Abnahme  
**Status:** Plan vollständig; viele Feld-/Labormessungen noch **offen** (Proto).

---

## 1. Teststrategie

| Ebene | Was | Artefakt / Methode | Status |
|---|-----|---|---|
| **Unit** | Bauteil/Netz-Regeln | DRC/ERC, Footprint-Check, BOM-LCSC | größtenteils done |
| **Integration** | Blöcke B1–B8 zusammen | Schaltplan-Review, Simulation Phasen | done / Sim |
| **Teilsystem** | Latch+Buck+Modul-Logik | HTML-Twin, adversariales Review | done Design-V |
| **System** | Platine bestückt im Aufbau | Messprotokoll Proto | **offen** |
| **Abnahme** | Lastenheft §11 | Abnahmetest mit Betreiber | **offen** |

---

## 2. Verifikationsarten (aus Traceability)

| Code | Bedeutung |
|---|---|
| V-INS | Inspektion / Sicht |
| V-MES | Messung |
| V-FUN | Funktionstest |
| V-ANA | Analyse / Rechnung |
| V-REV | Review |
| V-SIM | Simulation |

---

## 3. Testfälle (Kern)

| TC | Ebene | Titel | Pass-Kriterium | Status |
|----|---|---|---|---|
| TC-U01 | Unit | DRC PCB | 0 Fehler, 0 open nets | PASS (DRC_v2.5_final) |
| TC-U02 | Unit | ERC Schaltplan | 0 Fehler | PASS |
| TC-U03 | Unit | BOM↔CPL↔PCB Refs | 47/47 Match | PASS (Review) |
| TC-I01 | Integration | F-01 Netze IOx_M | U2 nur IOx_M; D15–D22 | PASS (pcbnew) |
| TC-I02 | Integration | F-02 R5=0R | Value+Netze | PASS |
| TC-I03 | Integration | Sim Idle-Strom | ~10–20 µA Latch aus | PASS (Sim) |
| TC-T01 | Teilsystem | Sim UC-01 Happy Path | SET→Play→Release | PASS (Sim) |
| TC-T02 | Teilsystem | Adversarial Disposition | F-01…F-09 geschlossen/akzeptiert | PASS Doku |
| TC-S01 | System | Idle I_BAT real | <100 µA | **OFFEN Proto** |
| TC-S02 | System | Taste halten → Play | Audio <0,5 s nach Boot | **OFFEN** |
| TC-S03 | System | BUSY/Q3_GATE Oszi | Release verzögert, kein Sofort-Kill Boot | **OFFEN A-03** |
| TC-S04 | System | R12 Temp / I_LED | unkritisch heiß | **OFFEN A-02** |
| TC-S05 | System | 5 V unter Play+LED | 5,0±0,25 V | **OFFEN F-08** |
| TC-S06 | System | Retrigger UC-02 | neue Stimme ersetzt alte | **OFFEN** |
| TC-S07 | System | Zähler +1 pro Session | mechanisch sichtbar | **OFFEN** |
| TC-A01 | Abnahme | Lastenheft §11.1–4 | Betreiber OK | **OFFEN** |
| TC-A02 | Abnahme | USB-Audio UC-04 | Dateien abspielbar | **OFFEN** |

---

## 4. Mapping Abnahmekriterien → TC

| Lastenheft §11 | TC |
|---|-----|
| 8 Taster korrekt | TC-S02, TC-A01 |
| <500 ms Start | TC-S02 |
| Idle <100 µA | TC-S01 |
| Lautstärke 2 m | TC-A01 (subjektiv/SPL optional) |
| Temperatur −10…+60 | V-ANA Datenblatt; Feld optional |
| 1000 Zyklen | Dauerlauf nach Proto |
| Retrigger | TC-S06 |
| Zähler | TC-S07 |

---

## 5. Abweichungsprozess (leicht)

1. Fund → Eintrag (Bug/Abweichung) mit TC-ID  
2. Schwere: Blocker / Major / Minor  
3. Fix → Retest TC  
4. Baseline nur bei PASS kritischer TC-S*

---

## 6. Ehrlichkeit

Design-Verifikation (links+Mitte V) ist stark. **Validierung am realen Kasten steht aus** — daher Fertigungsfreigabe „mit Auflagen“, nicht „serie-fertig ohne Proto“.

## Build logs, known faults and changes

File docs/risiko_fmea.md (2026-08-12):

# Risiko & Design-FMEA (leicht) — Rev 2.5

**Scope:** Technische Risiken der Elektronik/Lehrpfad-Einsatz. Keine Automotive-HARA, keine Termin-/Business-Risiken.

**Skala:** S = Schwere 1–10, O = Auftreten 1–10, D = Entdeckung 1–10, RPN = S×O×D.

---

## 1. Risikoregister (Auszug)

| ID | Risiko | S | O | D | RPN | Maßnahme | Status |
|----|---|---|---|---|-----|---|---|
| R-01 | 12 V an Modul-IO (Phantom Supply) | 9 | 8 | 3 | 216 | D15–D22 Serie (F-01) | behoben |
| R-02 | VOS mit 100k → falsche 5 V | 8 | 7 | 4 | 224 | R5=0R (F-02) | behoben |
| R-03 | Kurzdruck → kein Play / „tot“ | 7 | 6 | 5 | 210 | R13/C4 + Hold-Hinweis (F-03) | mitigiert; Proto |
| R-04 | LED-Kurzschluss an J6 | 6 | 4 | 4 | 96 | R12 10Ω (F-04); messen | mitigiert |
| R-05 | SPK zu dünn → Hitze/Drop | 5 | 4 | 5 | 100 | SPK ≥0,4/0,8 (F-05) | behoben |
| R-06 | SI2301 VDS vs. TVS Clamp | 8 | 2 | 6 | 96 | akzeptiert Batterie/Schrank (F-07) | akzeptiert |
| R-07 | USB + Board-5V Backfeed | 6 | 4 | 3 | 72 | IBN-Regel Sockel (F-09) | Prozess |
| R-08 | Feuchte / Kondenswasser | 6 | 5 | 5 | 150 | Coating empfohlen (U02) | Auflage Montage |
| R-09 | Falsche Bestückung Diode | 8 | 3 | 4 | 96 | CPL + Review; Proto Sichtprüfung | offen Proto |

---

## 2. Design-FMEA (Kernzeilen)

| Element | Fehlerart | Folge | Ursache | Detection | Aktion |
|---|---|---|---|---|---|
| D15–D22 | verkehrt bestückt | Modul-Schaden / kein Trigger | Polarität SOD-323 | AOI/Sicht | Bestückungsnotiz Kathode=IOx |
| R5 | offen statt 0R | 5 V Drift | BOM-Verwechslung | Spannung messen | Value 0R in BOM/CPL |
| Q5 | Drain/Source vertauscht | kein Betrieb / Kurz | Footprint | Funktionsprüf | Layout-Review erledigt |
| Latch | Race BUSY | Session bricht sofort ab | Boot vs Release | Oszi Proto | F-03 RC |
| J2 | SPK− an GND | Verstärker-Stress | Verkabelung | IBN Checkliste | Doku BTL |

---

## 3. Was bewusst fehlt

- Prozess-FMEA Fertigungslinie JLCPCB (Lieferant)
- FTA/ETA formell
- Cybersecurity (kein Netz)

Annahmen und akzeptierte Restrisiken: `adversarial_review_v25.md`.

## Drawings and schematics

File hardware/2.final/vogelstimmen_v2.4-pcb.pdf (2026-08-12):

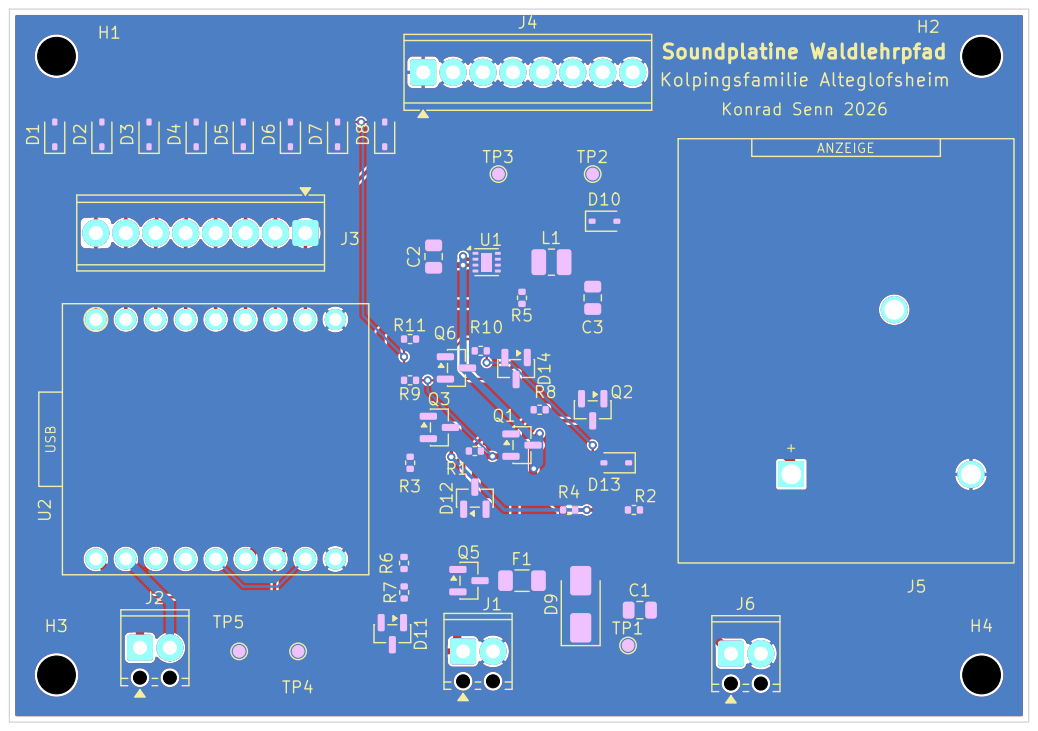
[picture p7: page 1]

Soundplatine Waldlehrpfad
Konrad Senn 2026 Kolpingsfamilie Alteglofsheim

ANZEIGE

Size: A4 | Rev:
KiCad E.D.A. 10.0.4 | Id: 1/1

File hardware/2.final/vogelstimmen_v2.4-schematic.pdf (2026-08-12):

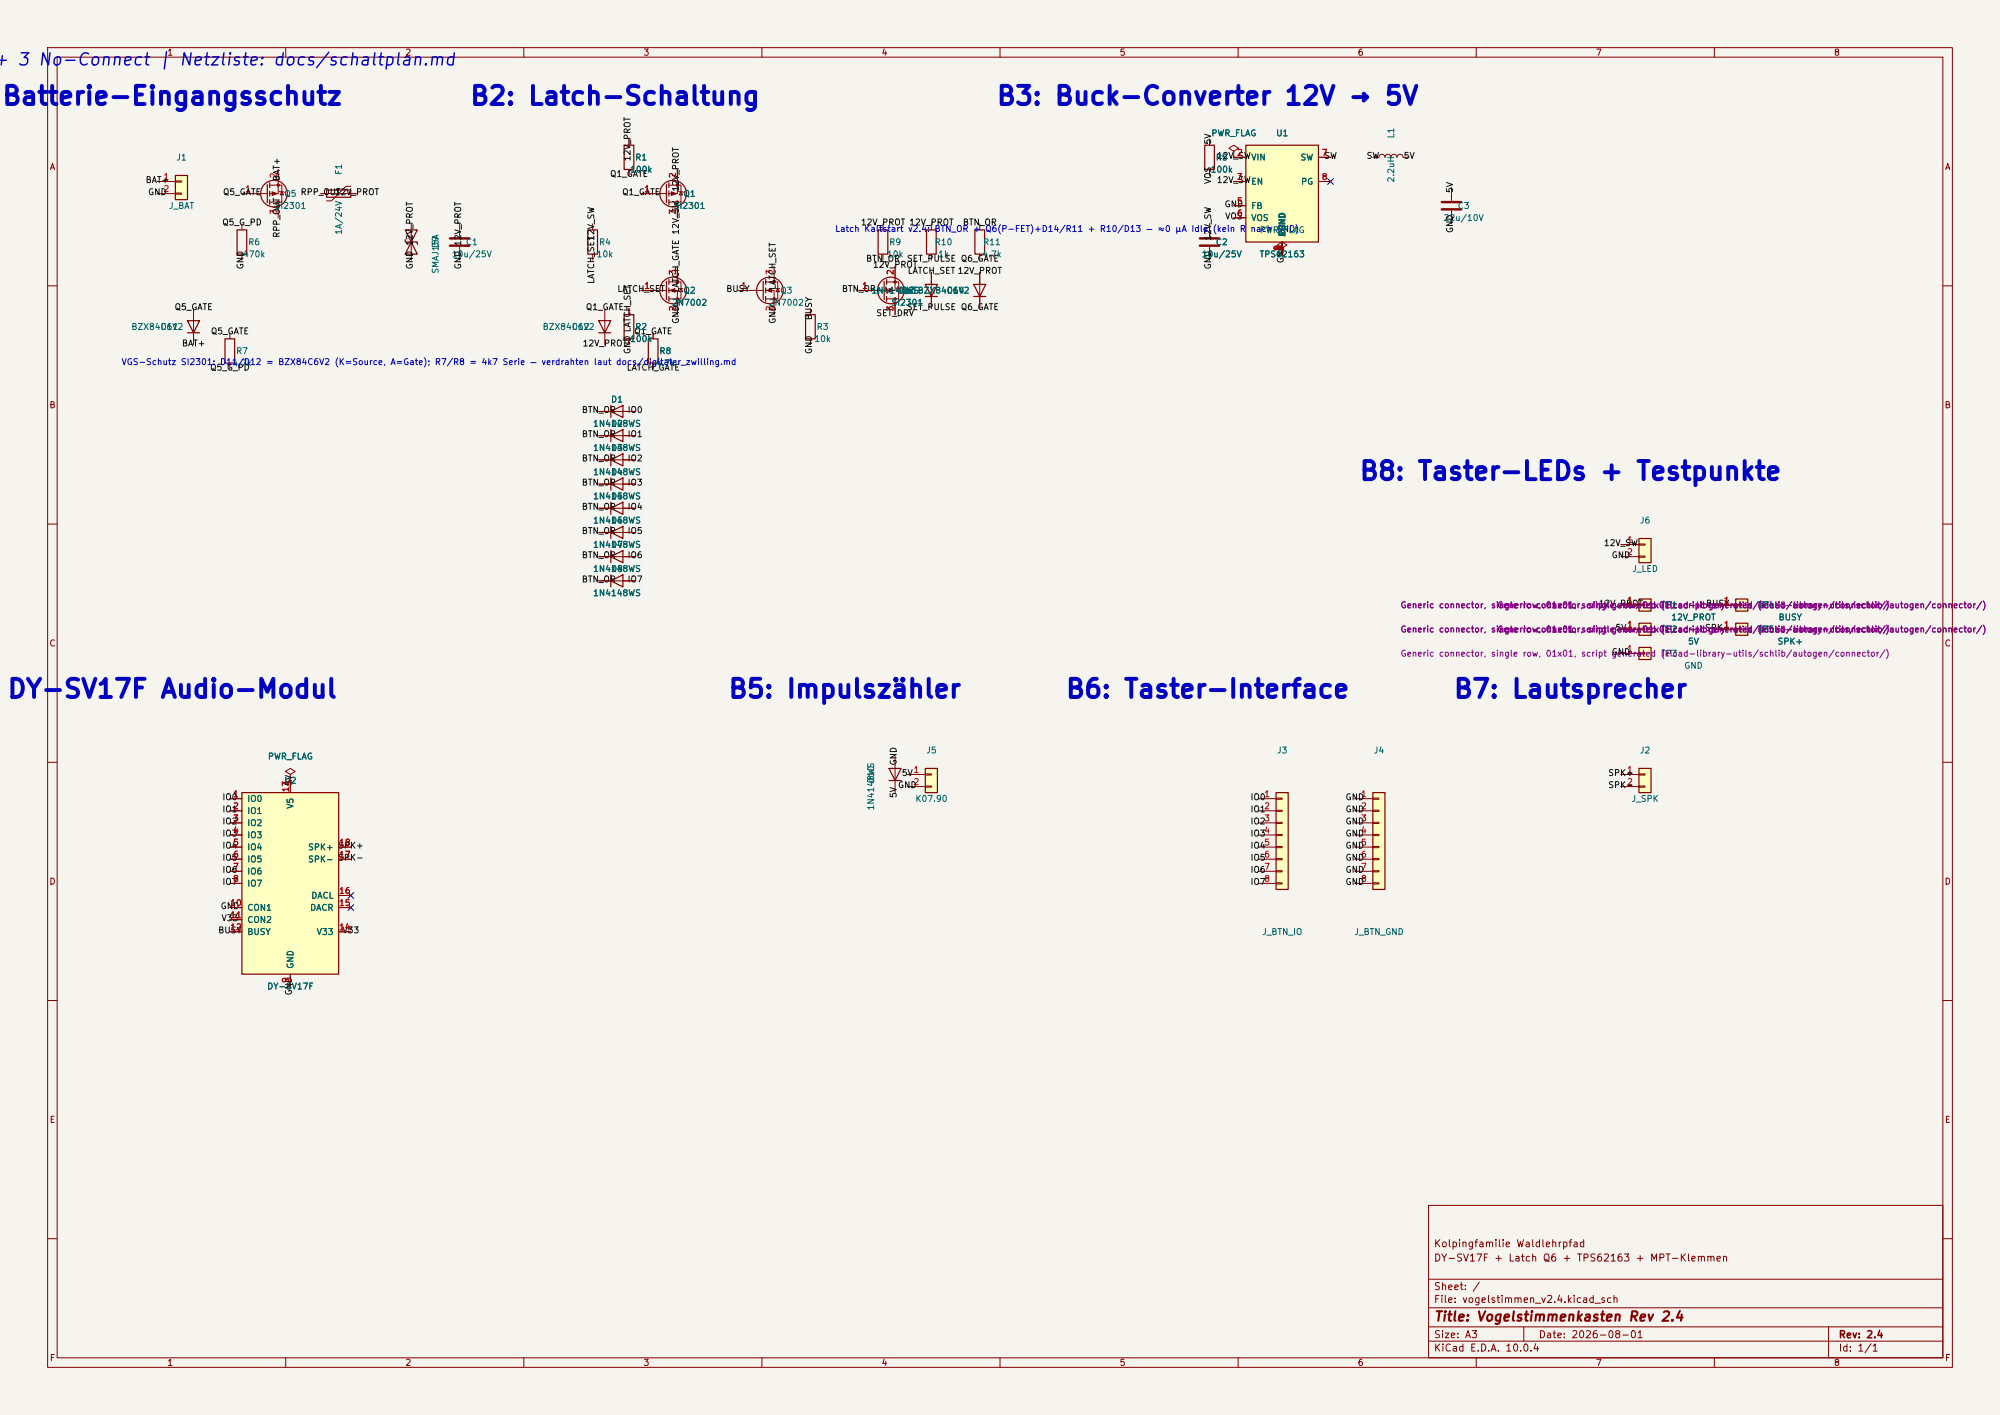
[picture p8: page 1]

105 Net-Labels + 3 No-Connect | Netzliste: docs/schaltplan.md

VGS-Schutz SI2301: D11/D12 = BZX84C6V2 (K=Source, A=Gate); R7/R8 = 4k7 Serie — verdrahten laut docs/digitaler_zwilling.md

Generic connector, single row, 01x01, script generated (kicad-library-utils/schlib/autogen/connector/) 1
12V_PROT Generic connector, single row, 01x01, script generated (kicad-library-utils/schlib/autogen/connector/) 1

5V Generic connector, single row, 01x01, script generated (kicad-library-utils/schlib/autogen/connector/) 1
B7: Lautsprecher

Kolpingfamilie Waldlehrpfad
DY-SV17F + Latch Q6 + TPS62163 + MPT-Klemmen

Size: A3 | Rev: 2.4
KiCad E.D.A. 10.0.4 | Id: 1/1 | F Date: 2026-08-01

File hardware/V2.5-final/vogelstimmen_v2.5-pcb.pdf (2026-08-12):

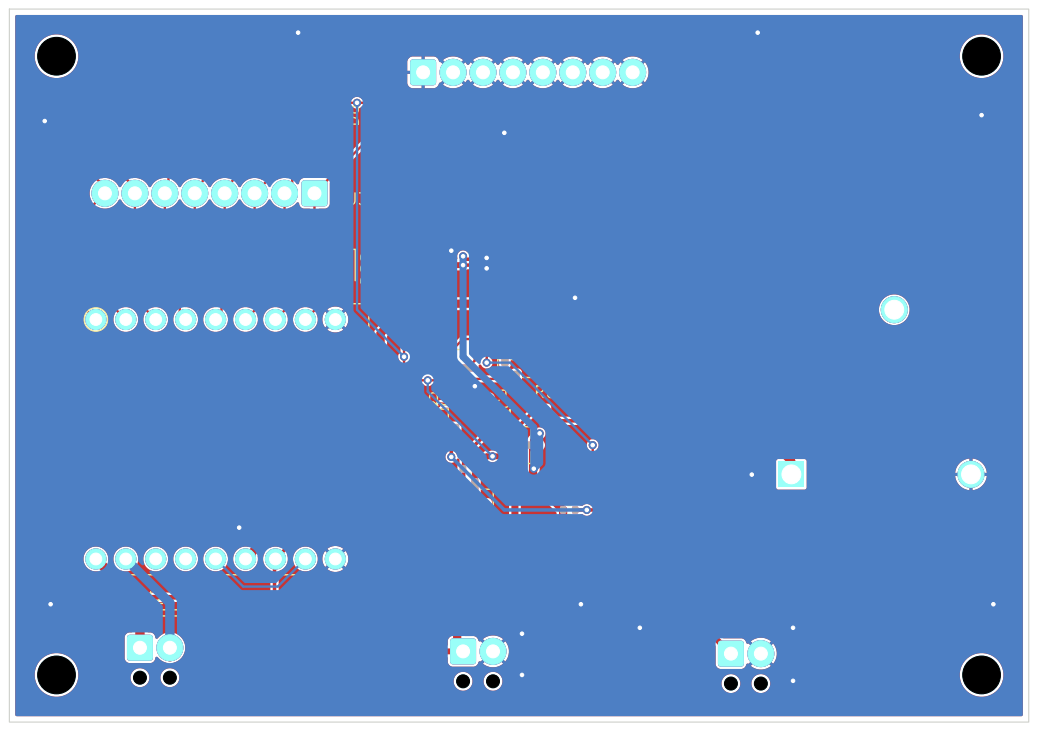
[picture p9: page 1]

Soundplatine Waldlehrpfad
Konrad Senn 2026 Kolpingsfamilie Alteglofsheim

Size: A4 | Rev:
KiCad E.D.A. 10.0.4 | Id: 1/1

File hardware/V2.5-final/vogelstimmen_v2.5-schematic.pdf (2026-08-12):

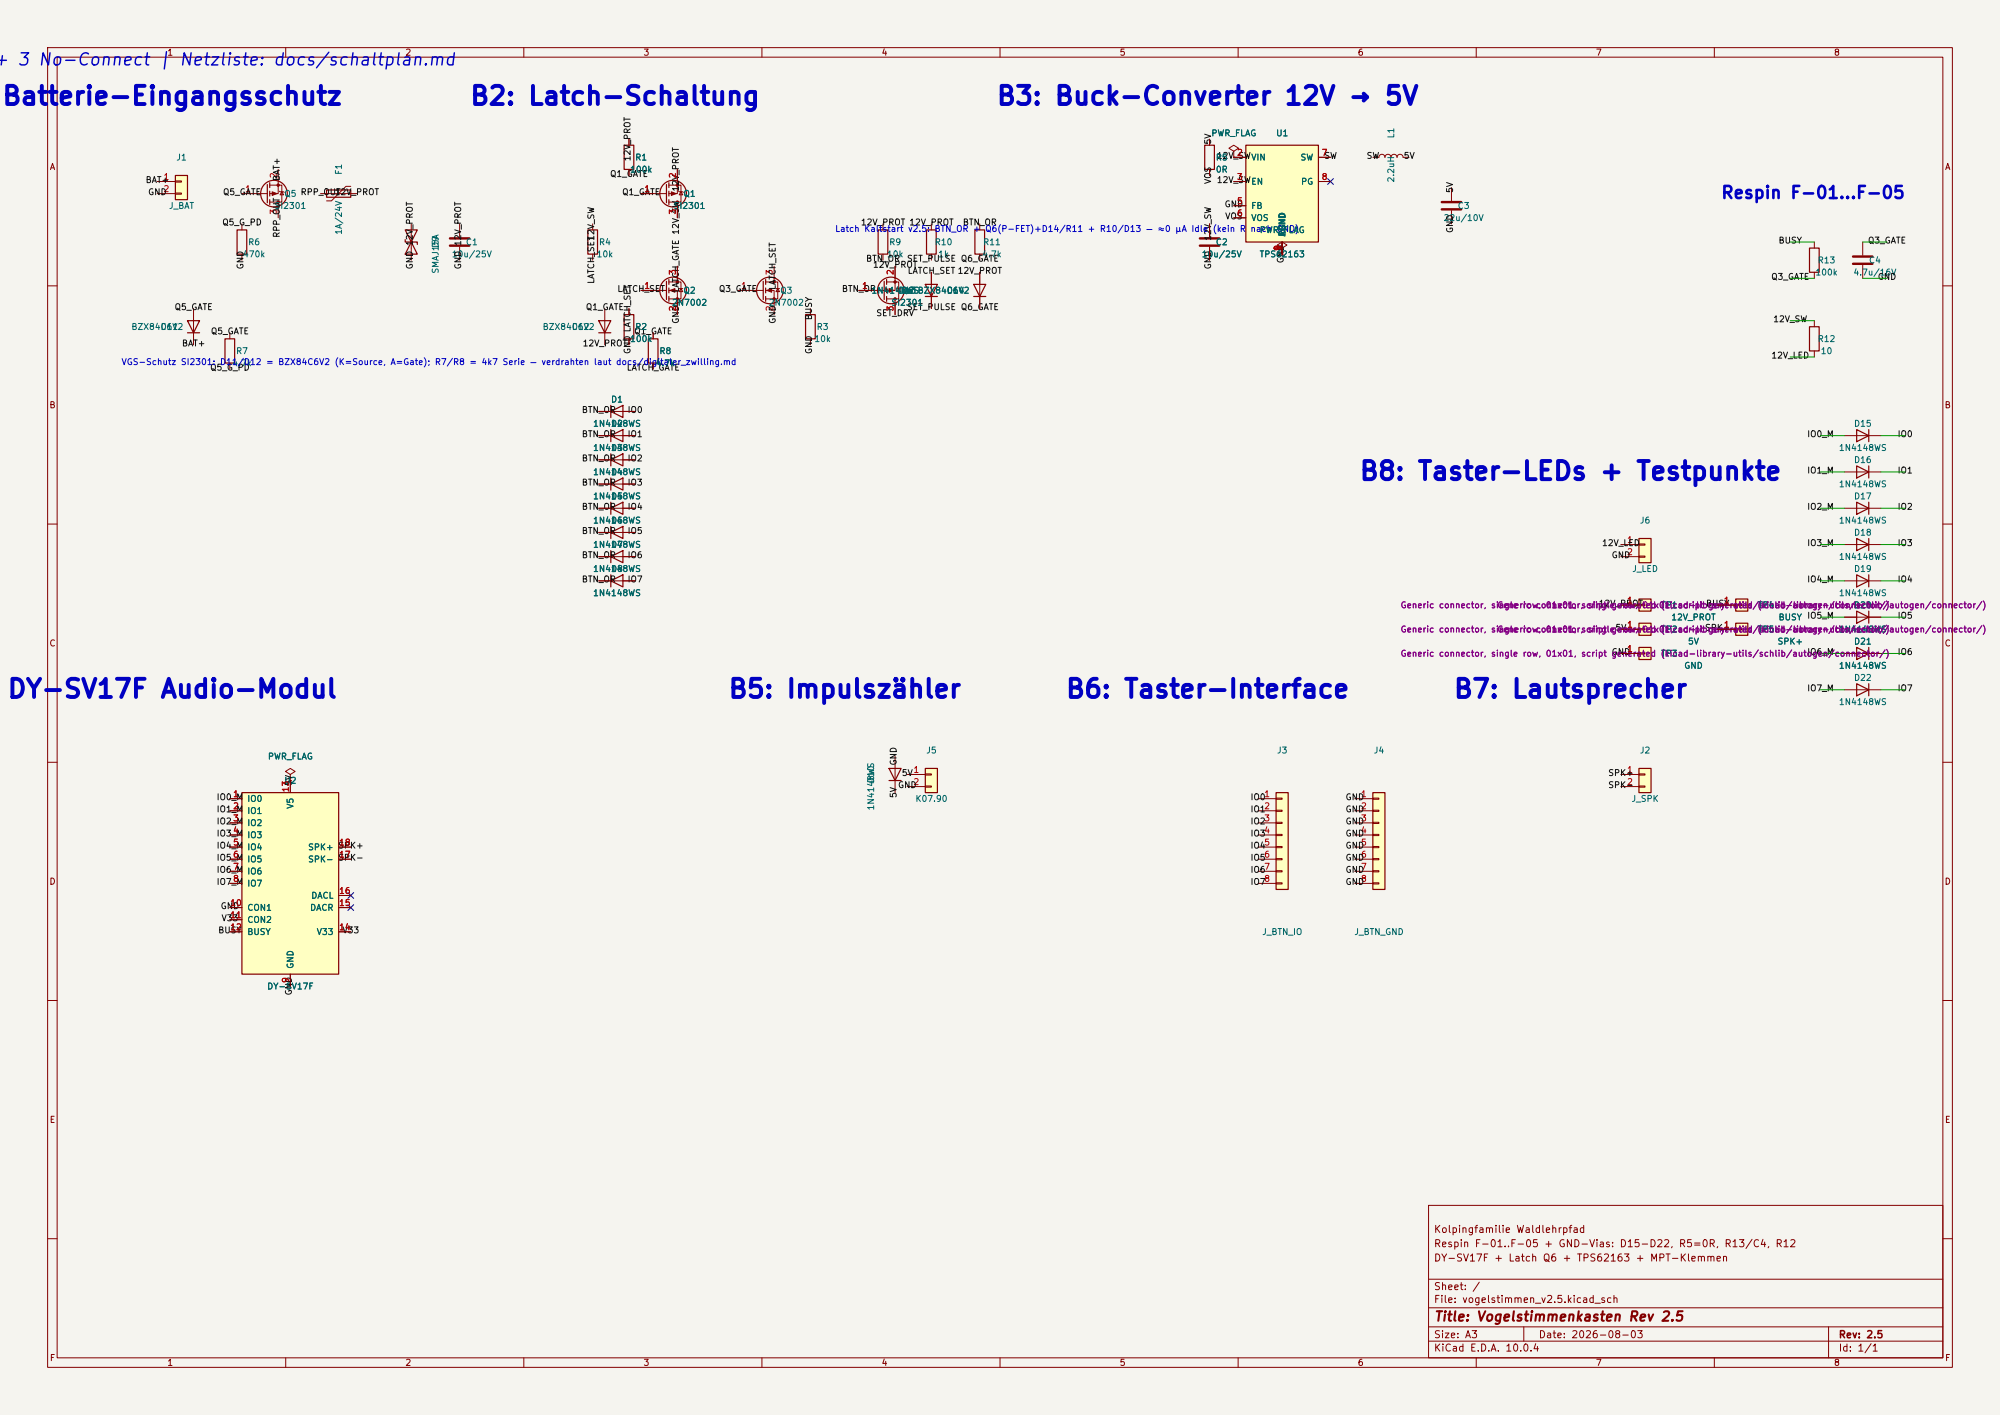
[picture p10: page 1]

12V_SW 105 Net-Labels + 3 No-Connect | Netzliste: docs/schaltplan.md

Generic connector, single row, 01x01, script generated (kicad-library-utils/schlib/autogen/connector/) R9
SET_PULSE SET_PULSE Q6_GATE
LATCH_SET

12V_PROT Generic connector, single row, 01x01, script generated (kicad-library-utils/schlib/autogen/connector/) R2

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

5V Generic connector, single row, 01x01, script generated (kicad-library-utils/schlib/autogen/connector/) D16
B8: Taster-LEDs + Testpunkte

12V_PROT Generic connector, single row, 01x01, script generated (kicad-library-utils/schlib/autogen/connector/) 1

5V Generic connector, single row, 01x01, script generated (kicad-library-utils/schlib/autogen/connector/) 1

Generic connector, single row, 01x01, script generated (kicad-library-utils/schlib/autogen/connector/) 1
B7: Lautsprecher

Kolpingfamilie Waldlehrpfad
Respin F-01..F-05 + GND-Vias: D15-D22, R5=0R, R13/C4, R12
DY-SV17F + Latch Q6 + TPS62163 + MPT-Klemmen

Size: A3 | Rev: 2.5
KiCad E.D.A. 10.0.4 | Id: 1/1 | F Date: 2026-08-03

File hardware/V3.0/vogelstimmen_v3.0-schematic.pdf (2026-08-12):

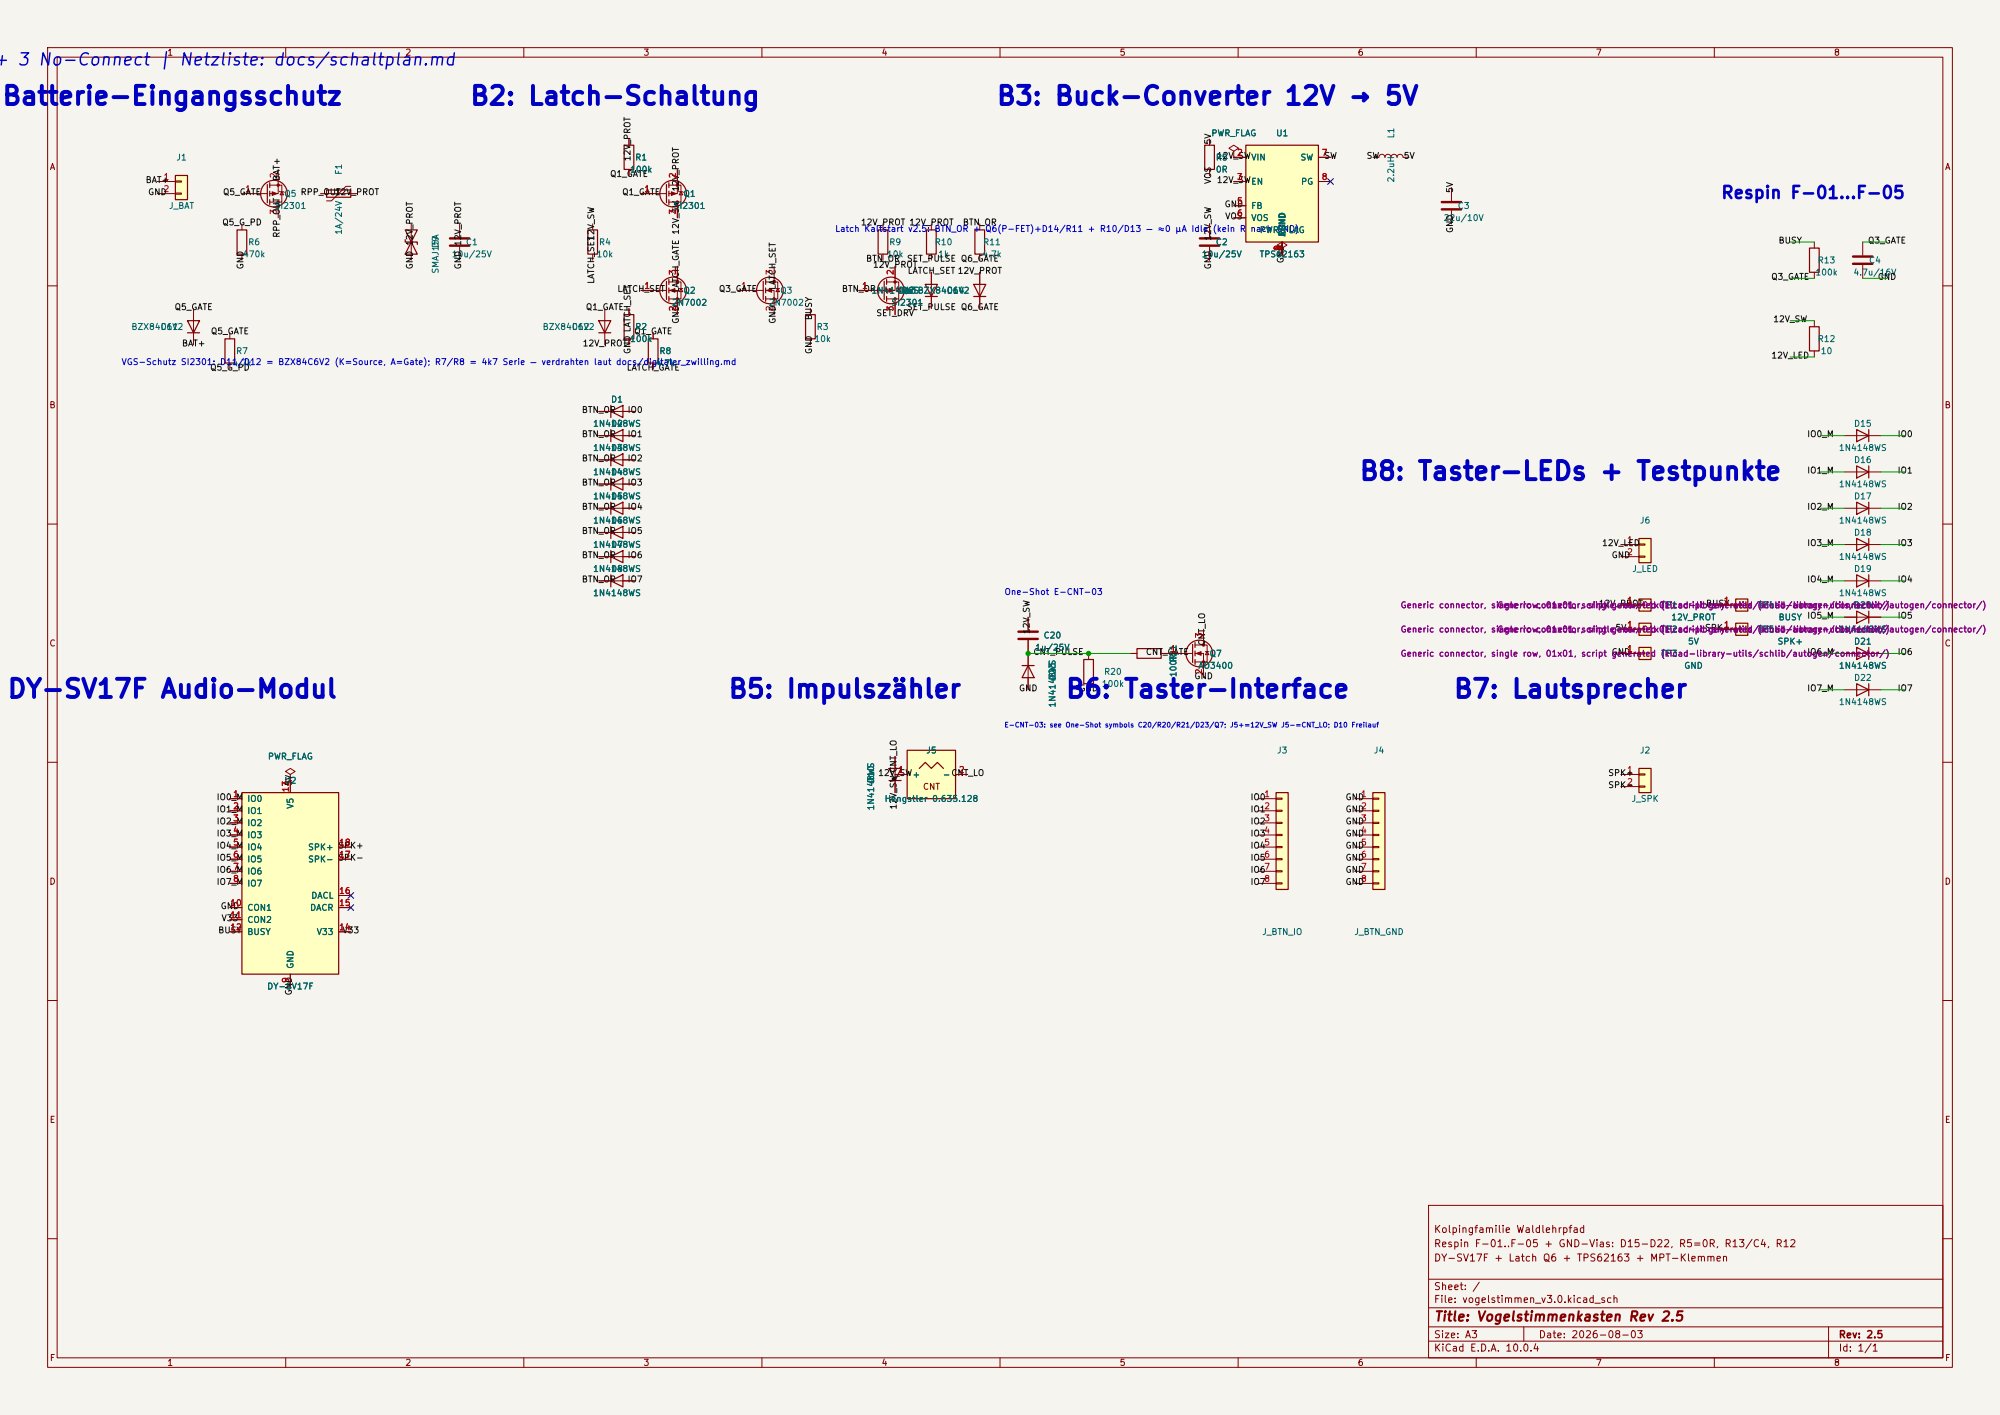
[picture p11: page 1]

E-CNT-03: see One-Shot symbols C20/R20/R21/D23/Q7; J5+=12V_SW J5-=CNT_LO; D10 Freilauf 105 Net-Labels + 3 No-Connect | Netzliste: docs/schaltplan.md

5V Generic connector, single row, 01x01, script generated (kicad-library-utils/schlib/autogen/connector/) R4

12V_PROT Generic connector, single row, 01x01, script generated (kicad-library-utils/schlib/autogen/connector/) C2

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

Generic connector, single row, 01x01, script generated (kicad-library-utils/schlib/autogen/connector/) 1

12V_PROT Generic connector, single row, 01x01, script generated (kicad-library-utils/schlib/autogen/connector/) 1

5V Generic connector, single row, 01x01, script generated (kicad-library-utils/schlib/autogen/connector/) 1

B7: Lautsprecher

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

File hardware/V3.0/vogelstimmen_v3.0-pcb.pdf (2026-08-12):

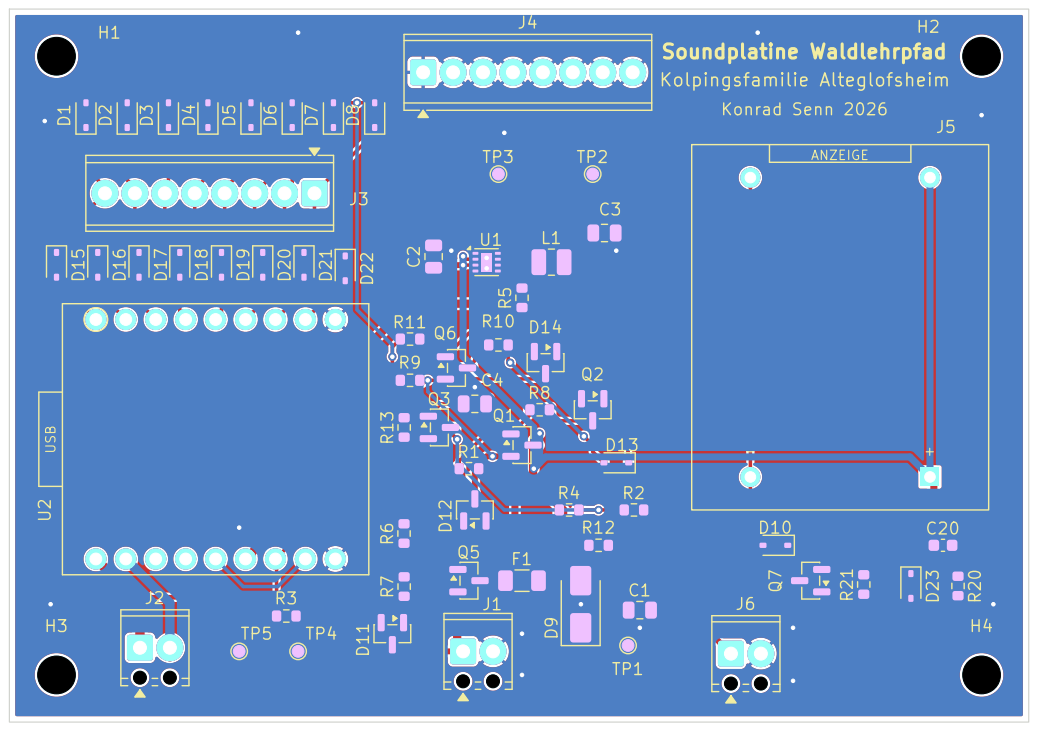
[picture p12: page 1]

Soundplatine Waldlehrpfad
Konrad Senn 2026 Kolpingsfamilie Alteglofsheim

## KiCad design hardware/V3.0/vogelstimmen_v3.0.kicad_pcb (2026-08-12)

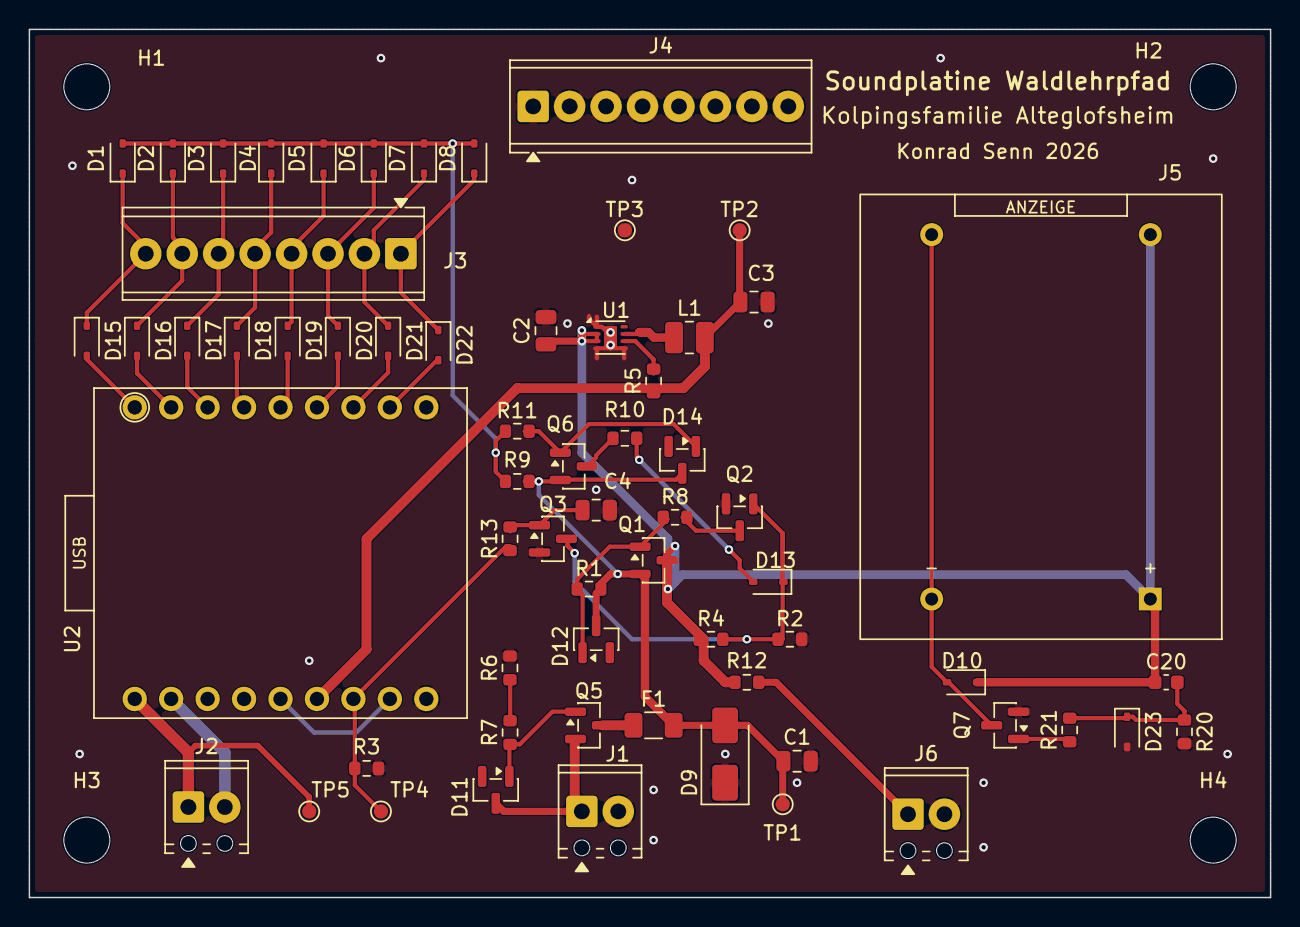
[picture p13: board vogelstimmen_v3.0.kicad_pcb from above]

Board: 2 copper layers, 86.5 x 60.5 mm, 68 parts (0 on the bottom side), 42 nets.

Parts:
C1, C2: 10u/25V; C_0805_2012Metric
C3: 22u/10V; C_0805_2012Metric
C4: 4.7u/16V; C_0805_2012Metric
C20: 1u/25V; C_0603_1608Metric
D1, D2, D3, D4, D5, D6, D7, D8, D10, D13, D15, D16, D17, D18, D19, D20, D21, D22, D23: 1N4148WS; D_SOD-323
D9: SMAJ15A; D_SMA
D11, D12, D14: BZX84C6V2
F1: 1A/24V; Fuse_1206_3216Metric
H1, H2, H3, H4: MountingHole_3.2mm_M3
J1: MPT-0,5/2 BAT; TerminalBlock_Phoenix_MPT-0,5-2-2.54_1x02_P2.54mm_Horizontal
J2: MPT-0,5/2 SPK; TerminalBlock_Phoenix_MPT-0,5-2-2.54_1x02_P2.54mm_Horizontal
J3: MPT-0,5/8 IO; TerminalBlock_Phoenix_MPT-0,5-8-2.54_1x08_P2.54mm_Horizontal
J4: MPT-0,5/8 GND; TerminalBlock_Phoenix_MPT-0,5-8-2.54_1x08_P2.54mm_Horizontal
J5: Hengstler 0.635.128; CNT_HENGSTLER_635
J6: MPT-0,5/2 LED; TerminalBlock_Phoenix_MPT-0,5-2-2.54_1x02_P2.54mm_Horizontal
L1: 2.2uH; L_1008_2520Metric
Q1, Q5, Q6: SI2301; SOT-23
Q2, Q3: 2N7002; SOT-23
Q7: AO3400; SOT-23
R1, R2, R13, R20: 100k; R_0603_1608Metric
R3, R4, R9: 10k; R_0603_1608Metric
R5: 0R; R_0603_1608Metric
R6: 470k; R_0603_1608Metric
R7, R8, R11: 4.7k; R_0603_1608Metric
R10: 1k; R_0603_1608Metric
R12: 10; R_0603_1608Metric
R21: 100R; R_0603_1608Metric
TP1: 12V_PROT; TestPoint_Pad_D1.0mm
TP2: 5V; TestPoint_Pad_D1.0mm
TP3: GND; TestPoint_Pad_D1.0mm
TP4: BUSY; TestPoint_Pad_D1.0mm
TP5: SPK+; TestPoint_Pad_D1.0mm
U1: TPS62163; WSON-8-1EP_2x2mm_P0.5mm_EP0.9x1.6mm
U2: DY-SV17F

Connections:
/5V: C3.1, L1.2, R5.1, TP2.1 (Pin_1_1), U2.13 (V5)
/12V_LED: J6.1, R12.2
/12V_PROT: C1.1, D9.2 (A2), D12.1, D14.1, F1.2, Q1.2 (S), Q6.2, R1.2, R9.1, TP1.1 (Pin_1_1)
/12V_SW: C2.1, C20.1, D10.1 (K), J5.1, Q1.3 (D), R4.1, R12.1, U1.2 (VIN), U1.3 (EN)
/BAT+: D11.1, J1.1, Q5.2 (S)
/BTN_OR: D1.2 (A), D2.2 (A), D3.2 (A), D4.2 (A), D5.2 (A), D6.2 (A), D7.2 (A), D8.2 (A), R9.2, R11.1
/BUSY: R3.1, R13.1, TP4.1 (Pin_1_1), U2.12 (BUSY)
/CNT_GATE: Q7.1, R21.1
/CNT_LO: D10.2 (A), J5.2, Q7.3
/CNT_PULSE: C20.2, D23.1, R20.1, R21.2
/GND: C1.2, C2.2, C3.2, C4.2, D9.1 (A1), D23.2, J1.2, J4.1, J4.2, J4.3, J4.4, J4.5, J4.6, J4.7, J4.8, J6.2, Q2.2 (S), Q3.2 (S), Q7.2, R2.2, R3.2, R6.2, R20.2, TP3.1 (Pin_1_1), U1.1 (PGND), U1.4 (AGND), U1.5 (FB), U1.9 (EP), U2.9 (GND), U2.10 (CON1)
/IO0: D1.1 (K), D15.1 (K), J3.8
/IO0_M: D15.2 (A), U2.1 (IO0)
/IO1: D2.1 (K), D16.1 (K), J3.7
/IO1_M: D16.2 (A), U2.2 (IO1)
/IO2: D3.1 (K), D17.1 (K), J3.6
/IO2_M: D17.2 (A), U2.3 (IO2)
/IO3: D4.1 (K), D18.1 (K), J3.5
/IO3_M: D18.2 (A), U2.4 (IO3)
/IO4: D5.1 (K), D19.1 (K), J3.4
/IO4_M: D19.2 (A), U2.5 (IO4)
/IO5: D6.1 (K), D20.1 (K), J3.3
/IO5_M: D20.2 (A), U2.6 (IO5)
/IO6: D7.1 (K), D21.1 (K), J3.2
/IO6_M: D21.2 (A), U2.7 (IO6)
/IO7: D8.1 (K), D22.1 (K), J3.1
/IO7_M: D22.2 (A), U2.8 (IO7)
/LATCH_GATE: Q2.3 (D), R8.2
/LATCH_SET: D13.1, Q2.1 (G), Q3.3 (D), R2.1, R4.2
/Q1_GATE: D12.2, Q1.1 (G), R1.1, R8.1
/Q3_GATE: C4.1, Q3.1 (G), R13.2
/Q5_GATE: D11.2, Q5.1 (G), R7.1
/Q5_G_PD: R6.1, R7.2
/Q6_GATE: D14.2, Q6.1, R11.2
/RPP_OUT: F1.1, Q5.3 (D)
/SET_DRV: Q6.3, R10.1
/SET_PULSE: D13.2, R10.2
/SPK+: J2.1, TP5.1 (Pin_1_1), U2.18 (SPK+)
/SPK-: J2.2, U2.17 (SPK-)
/SW: L1.1, U1.7 (SW)
/V33: U2.11 (CON2), U2.14 (V33)
/VOS: R5.2, U1.6 (VOS)

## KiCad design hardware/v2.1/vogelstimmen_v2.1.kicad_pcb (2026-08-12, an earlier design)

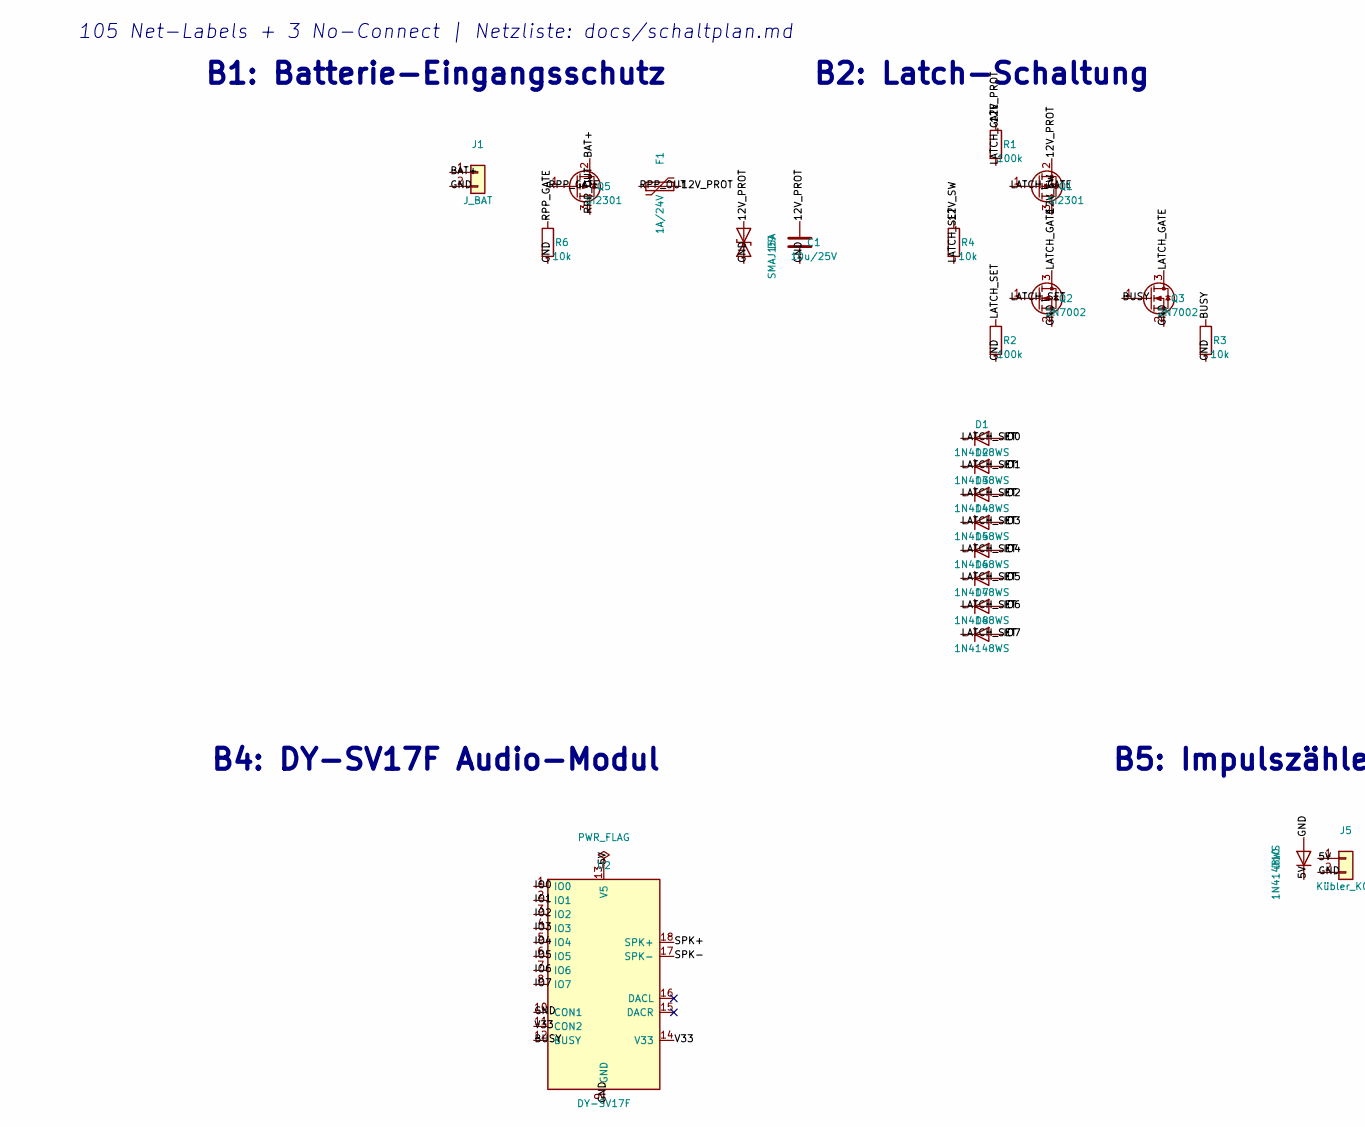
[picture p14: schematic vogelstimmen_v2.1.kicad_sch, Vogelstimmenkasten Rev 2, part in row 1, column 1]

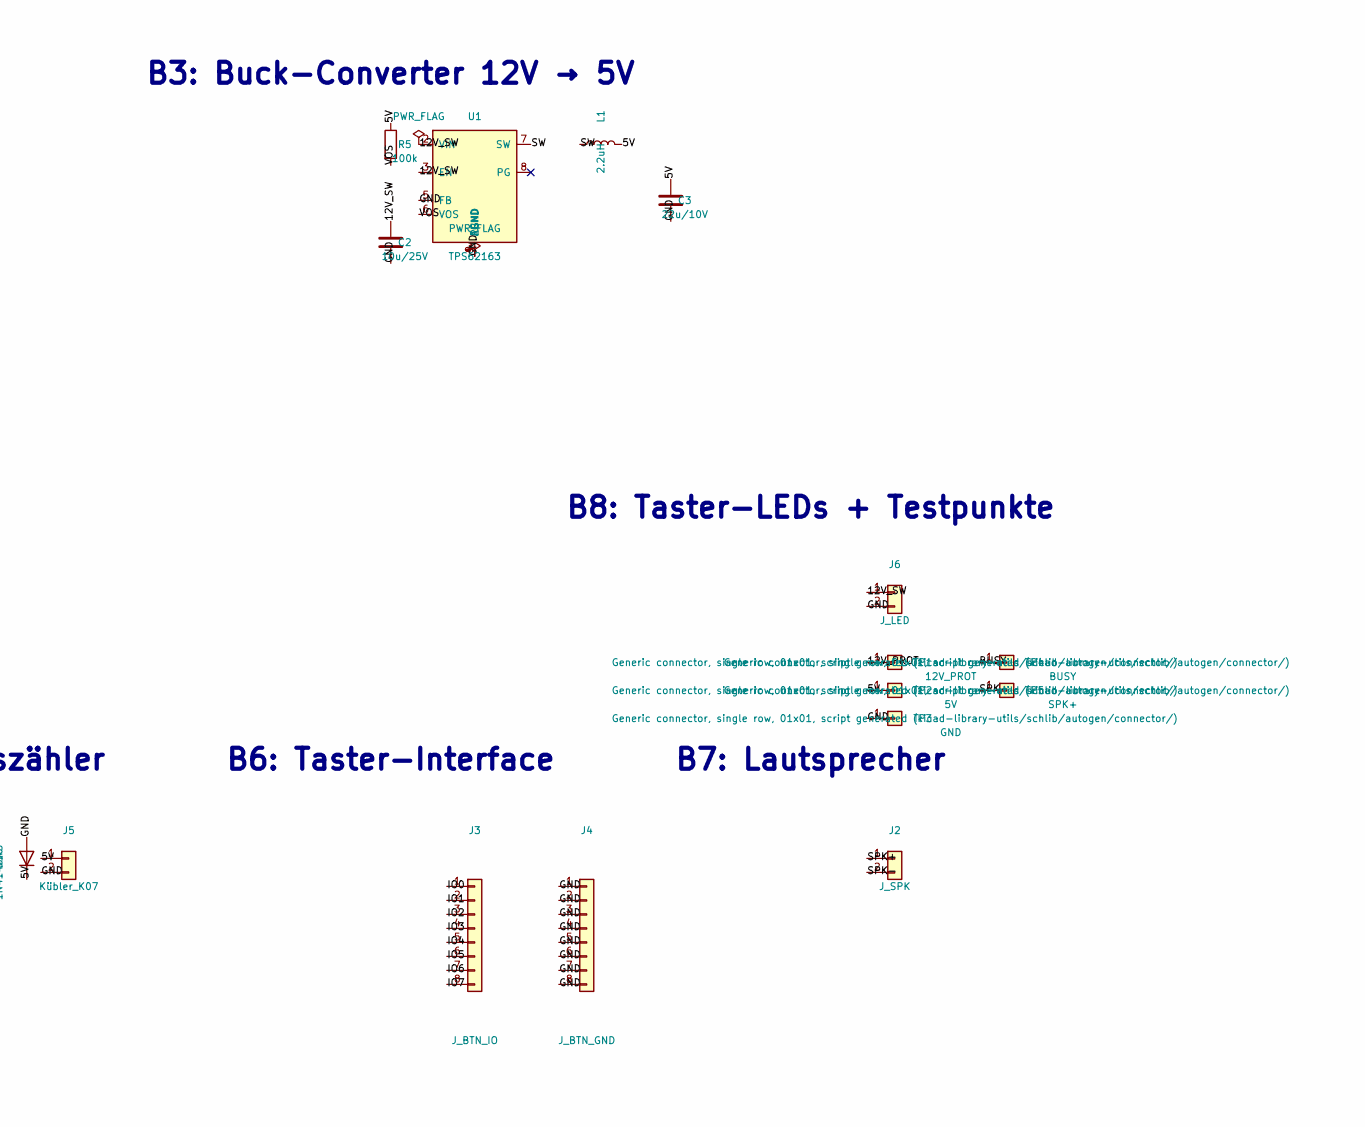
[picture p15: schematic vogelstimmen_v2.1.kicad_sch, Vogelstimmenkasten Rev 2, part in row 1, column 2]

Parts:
C1, C2: 10u/25V; C_0805_2012Metric
C3: 22u/10V; C_0805_2012Metric
D1, D2, D3, D4, D5, D6, D7, D8, D10: 1N4148WS; D_SOD-323; LCSC C118873
D9: SMAJ15A; D_SMA; LCSC C113958
F1: 1A/24V; Fuse_1206_3216Metric; LCSC C2760272
J1: J_BAT; PinHeader_1x02_P2.54mm_Vertical
J2: J_SPK; PinHeader_1x02_P2.54mm_Vertical
J3: J_BTN_IO; PinHeader_1x08_P2.54mm_Vertical
J4: J_BTN_GND; PinHeader_1x08_P2.54mm_Vertical
J5: Kübler_K07; PinHeader_1x02_P2.54mm_Vertical
J6: J_LED; PinHeader_1x02_P2.54mm_Vertical
L1: 2.2uH; L_1008_2520Metric; LCSC C88527
Q1, Q5: SI2301; SOT-23; LCSC C10487
Q2, Q3: 2N7002; SOT-23; LCSC C16338
R1, R2, R5: 100k; R_0402_1005Metric
R3, R4, R6: 10k; R_0402_1005Metric
TP1: 12V_PROT; TestPoint_Pad_D1.0mm
TP2: 5V; TestPoint_Pad_D1.0mm
TP3: GND; TestPoint_Pad_D1.0mm
TP4: BUSY; TestPoint_Pad_D1.0mm
TP5: SPK+; TestPoint_Pad_D1.0mm
U1: TPS62163; WSON-8-1EP_2x2mm_P0.5mm_EP0.9x1.6mm; LCSC C97534
U2: DY-SV17F

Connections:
/5V: C3.1, D10.1 (K), J5.1, L1.2, R5.1, TP2.1 (Pin_1_1), U2.13 (V5)
/12V_PROT: C1.1, D9.2 (A2), F1.2, Q1.2 (S), R1.1, TP1.1 (Pin_1_1)
/12V_SW: C2.1, J6.1, Q1.3 (D), R4.1, U1.2 (VIN), U1.3 (EN)
/BAT+: J1.1, Q5.2 (S)
/BUSY: Q3.1 (G), R3.1, TP4.1 (Pin_1_1), U2.12 (BUSY)
/GND: C1.2, C2.2, C3.2, D9.1 (A1), D10.2 (A), J1.2, J4.1, J4.2, J4.3, J4.4, J4.5, J4.6, J4.7, J4.8, J5.2, J6.2, Q2.2 (S), Q3.2 (S), R2.2, R3.2, R6.2, TP3.1 (Pin_1_1), U1.1 (PGND), U1.4 (AGND), U1.5 (FB), U1.9 (EP), U2.9 (GND), U2.10 (CON1)
/IO0: D1.2 (A), J3.1, U2.1 (IO0)
/IO1: D2.2 (A), J3.2, U2.2 (IO1)
/IO2: D3.2 (A), J3.3, U2.3 (IO2)
/IO3: D4.2 (A), J3.4, U2.4 (IO3)
/IO4: D5.2 (A), J3.5, U2.5 (IO4)
/IO5: D6.2 (A), J3.6, U2.6 (IO5)
/IO6: D7.2 (A), J3.7, U2.7 (IO6)
/IO7: D8.2 (A), J3.8, U2.8 (IO7)
/LATCH_GATE: Q1.1 (G), Q2.3 (D), Q3.3 (D), R1.2
/LATCH_SET: D1.1 (K), D2.1 (K), D3.1 (K), D4.1 (K), D5.1 (K), D6.1 (K), D7.1 (K), D8.1 (K), Q2.1 (G), R2.1, R4.2
/RPP_GATE: Q5.1 (G), R6.1
/RPP_OUT: F1.1, Q5.3 (D)
/SPK+: J2.1, TP5.1 (Pin_1_1), U2.18 (SPK+)
/SPK-: J2.2, U2.17 (SPK-)
/SW: L1.1, U1.7 (SW)
/V33: U2.11 (CON2), U2.14 (V33)
/VOS: R5.2, U1.6 (VOS)

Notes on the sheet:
B1: Batterie-Eingangsschutz
B2: Latch-Schaltung
B3: Buck-Converter 12V → 5V
B4: DY-SV17F Audio-Modul
B5: Impulszähler
B6: Taster-Interface
B7: Lautsprecher
B8: Taster-LEDs + Testpunkte
105 Net-Labels + 3 No-Connect | Netzliste: docs/schaltplan.md

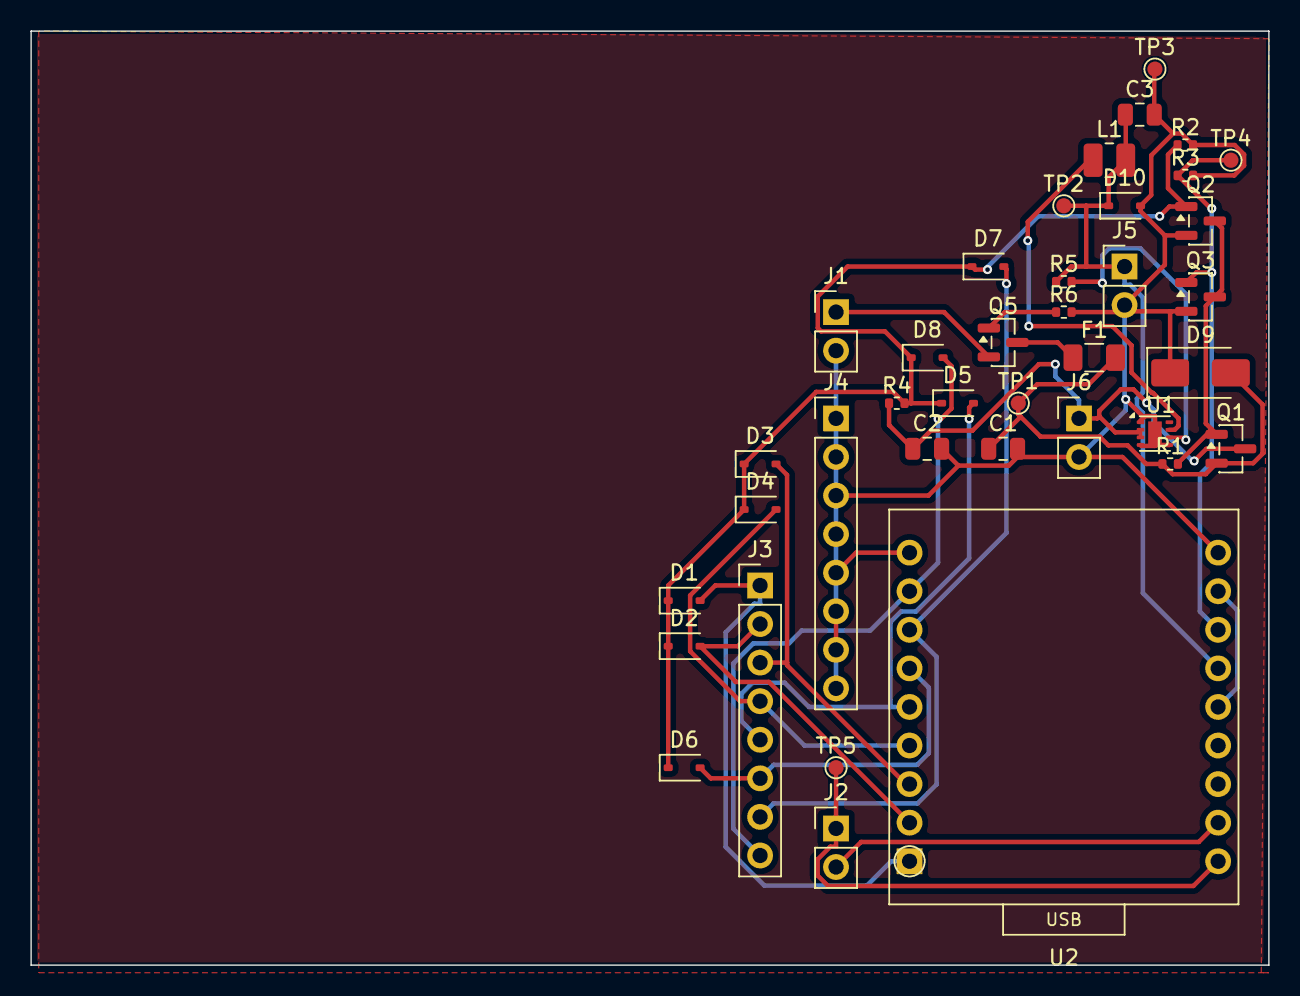
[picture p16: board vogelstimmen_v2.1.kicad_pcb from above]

Board: 2 copper layers, 81.5 x 61.5 mm, 38 parts (0 on the bottom side), 23 nets.

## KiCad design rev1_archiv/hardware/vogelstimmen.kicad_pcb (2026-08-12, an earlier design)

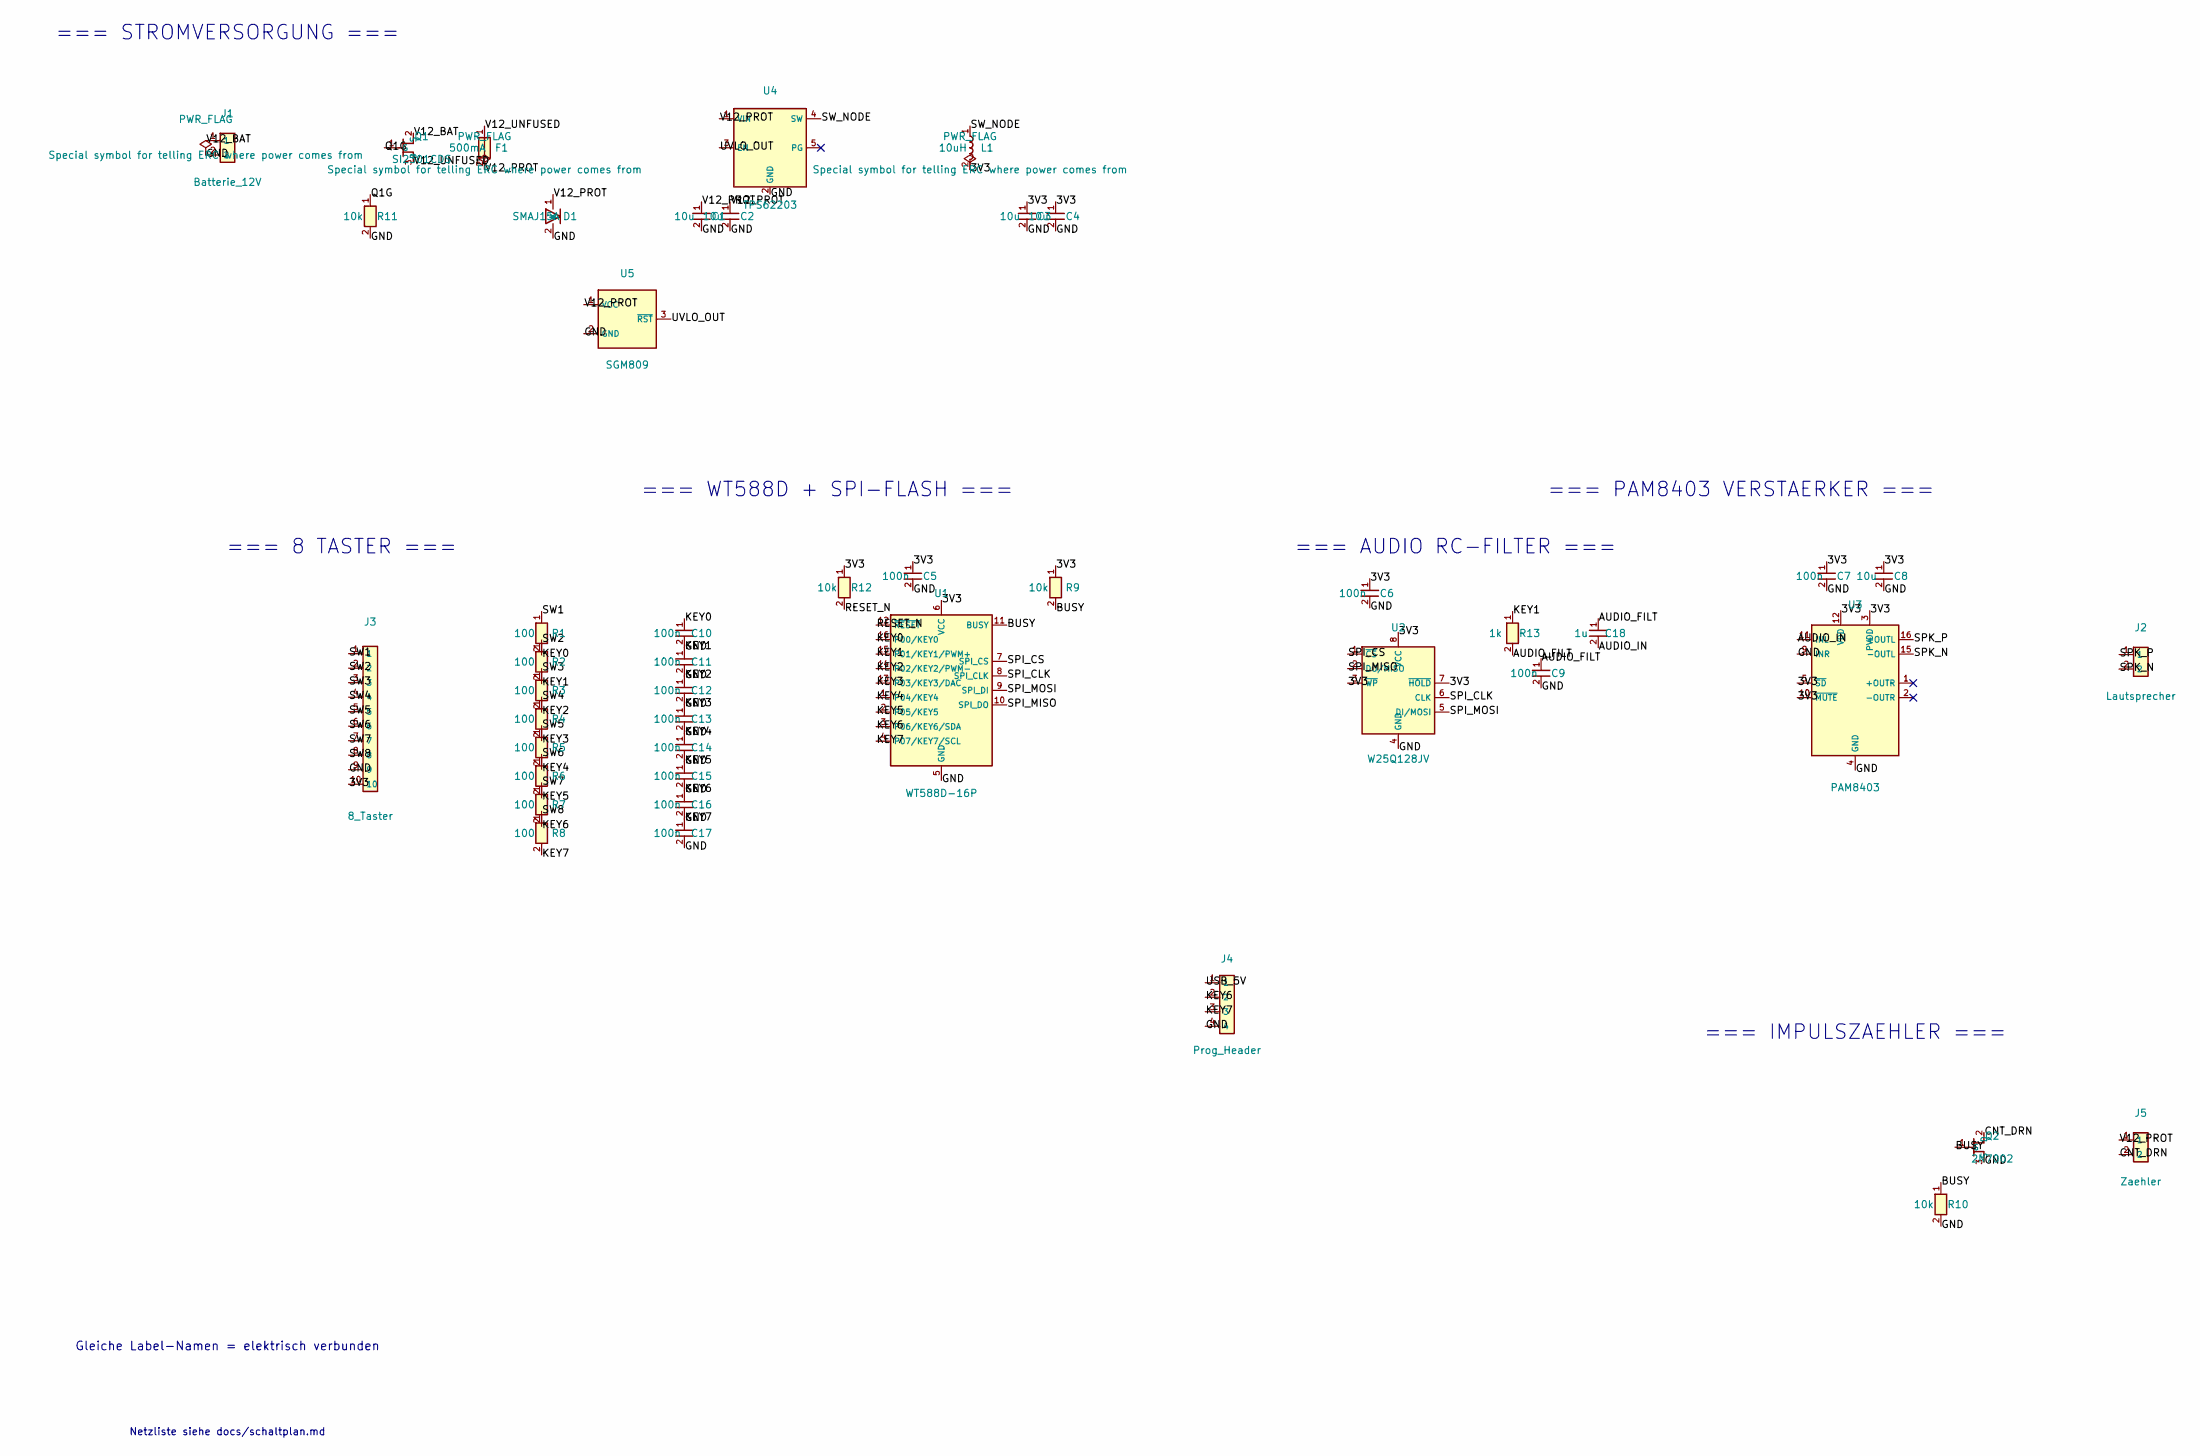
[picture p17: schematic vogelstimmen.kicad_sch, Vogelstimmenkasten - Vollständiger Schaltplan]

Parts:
C1, C2, C3, C4, C8: 10u; C_0805_2012Metric
C5, C6, C7, C9, C10, C11, C12, C13, C14, C15, C16, C17: 100n; C_0805_2012Metric
C18: 1u; C_0805_2012Metric
D1: SMAJ15A; D_SMA
F1: 500mA; Fuse_1206_3216Metric
J1: Batterie_12V; PinHeader_1x02_P2.54mm_Vertical
J2: Lautsprecher; PinHeader_1x02_P2.54mm_Vertical
J3: 8_Taster; PinHeader_1x10_P2.54mm_Vertical
J4: Prog_Header; PinHeader_1x04_P2.54mm_Vertical
J5: Zaehler; PinHeader_1x02_P2.54mm_Vertical
L1: 10uH; L_1210_3225Metric
Q1: SI2301CDS; SOT-23
Q2: 2N7002; SOT-23
R1, R2, R3, R4, R5, R6, R7, R8: 100; R_0805_2012Metric
R9, R10, R11, R12: 10k; R_0805_2012Metric
R13: 1k; R_0805_2012Metric
U1: WT588D-16P; DIP-16_W7.62mm
U2: W25Q128JV; SOIC-8_3.9x4.9mm_P1.27mm
U3: PAM8403; SOP-16_4.4x10.4mm_P1.27mm
U4: TPS62203; SOT-23-5
U5: SGM809; SOT-23

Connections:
/3V3: C3.1, C4.1, C5.1, C6.1, C7.1, C8.1, J3.10, L1.2, R9.1, R12.1, U1.6 (VCC), U2.3 (~WP), U2.7 (~HOLD), U2.8 (VCC), U3.3 (PVDD), U3.5 (~SD), U3.10 (~MUTE), U3.12 (VDD)
/AUDIO_FILT: C9.1, C18.1, R13.2
/AUDIO_IN: C18.2, U3.11 (INL)
/BUSY: Q2.1 (G), R9.2, R10.1, U1.11 (BUSY)
/CNT_DRN: J5.2, Q2.2 (D)
/GND: C1.2, C2.2, C3.2, C4.2, C5.2, C6.2, C7.2, C8.2, C9.2, C10.2, C11.2, C12.2, C13.2, C14.2, C15.2, C16.2, C17.2, D1.2 (A), J1.2, J3.9, J4.4, Q2.3 (S), R10.2, R11.2, U1.5 (GND), U2.4 (GND), U3.4 (GND), U3.9 (INR), U4.2 (GND), U5.2 (GND)
/KEY0: C10.1, R1.2, U1.16 (P00/KEY0)
/KEY1: C11.1, R2.2, R13.1, U1.15 (P01/KEY1/PWM+)
/KEY2: C12.1, R3.2, U1.14 (P02/KEY2/PWM-)
/KEY3: C13.1, R4.2, U1.13 (P03/KEY3/DAC)
/KEY4: C14.1, R5.2, U1.1 (P04/KEY4)
/KEY5: C15.1, R6.2, U1.2 (P05/KEY5)
/KEY6: C16.1, J4.2, R7.2, U1.3 (P06/KEY6/SDA)
/KEY7: C17.1, J4.3, R8.2, U1.4 (P07/KEY7/SCL)
/Q1G: Q1.1 (G), R11.1
/RESET_N: R12.2, U1.12 (~RESET)
/SPI_CLK: U1.8 (SPI_CLK), U2.6 (CLK)
/SPI_CS: U1.7 (SPI_CS), U2.1 (~CS)
/SPI_MISO: U1.10 (SPI_DO), U2.2 (DO/MISO)
/SPI_MOSI: U1.9 (SPI_DI), U2.5 (DI/MOSI)
/SPK_N: J2.2, U3.15 (-OUTL)
/SPK_P: J2.1, U3.16 (+OUTL)
/SW1: J3.1, R1.1
/SW2: J3.2, R2.1
/SW3: J3.3, R3.1
/SW4: J3.4, R4.1
/SW5: J3.5, R5.1
/SW6: J3.6, R6.1
/SW7: J3.7, R7.1
/SW8: J3.8, R8.1
/SW_NODE: L1.1, U4.4 (SW)
/USB_5V: J4.1
/UVLO_OUT: U4.3 (EN), U5.3 (~RST)
/V12_BAT: J1.1, Q1.2 (S)
/V12_PROT: C1.1, C2.1, D1.1 (K), F1.2, J5.1, U4.1 (VIN), U5.1 (VCC)
/V12_UNFUSED: F1.1, Q1.3 (D)

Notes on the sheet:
=== IMPULSZAEHLER ===
=== AUDIO RC-FILTER ===
=== STROMVERSORGUNG ===
Netzliste siehe docs/schaltplan.md
=== WT588D + SPI-FLASH ===
=== 8 TASTER ===
=== PAM8403 VERSTAERKER ===
Gleiche Label-Namen = elektrisch verbunden

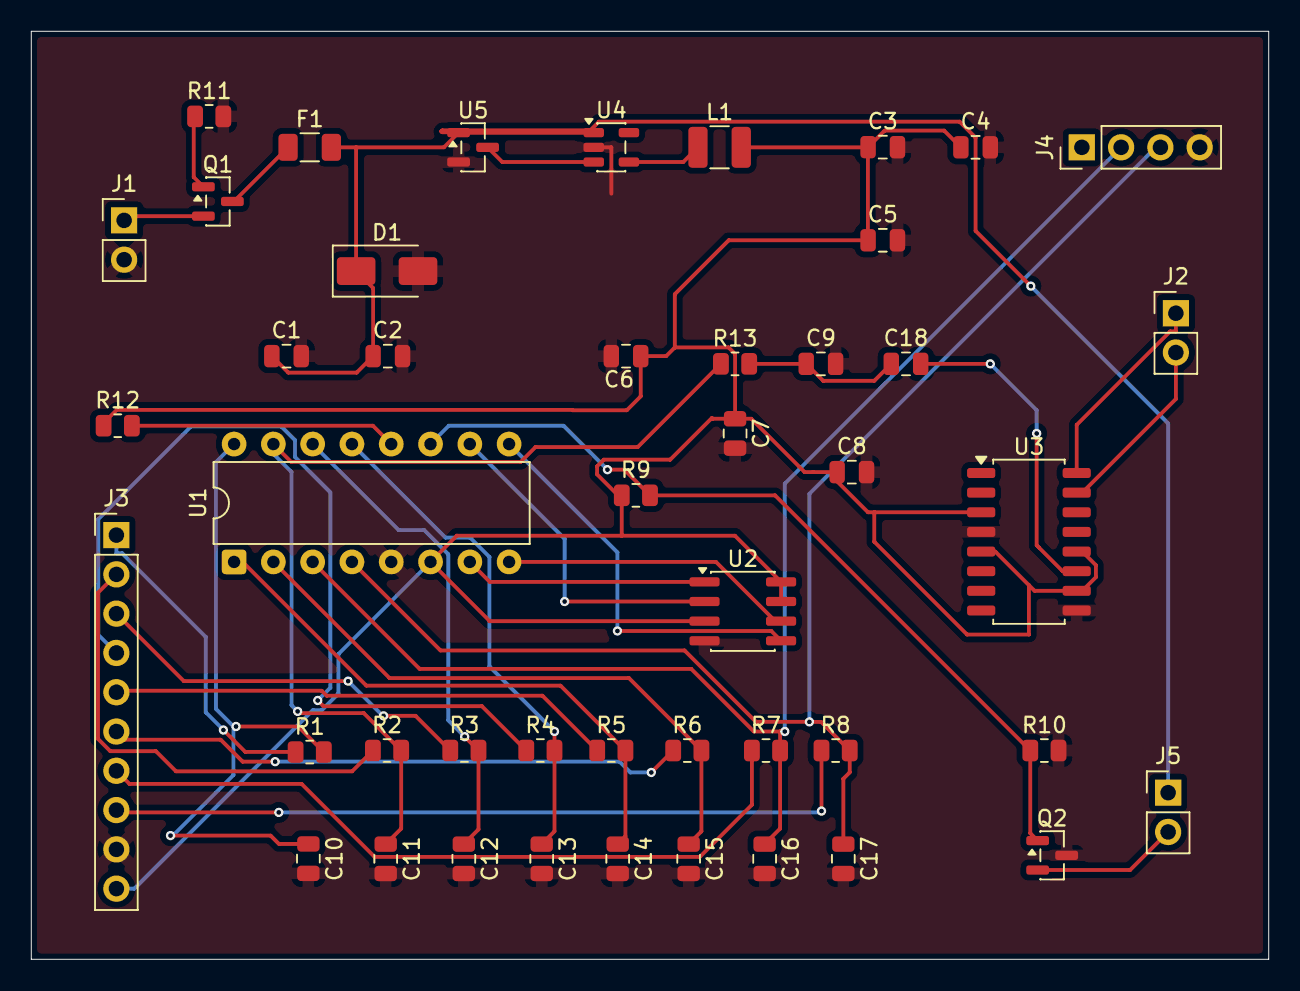
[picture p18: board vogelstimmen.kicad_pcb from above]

Board: 2 copper layers, 80.0 x 60.0 mm, 46 parts (0 on the bottom side), 35 nets.

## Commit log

2026-08-12 Publish Vogelstimmen MBSE showcase and refresh V3.0 fab package.
    Includes interactive presentation (showcase/), docs, simulation, and latest Gerbers after R-07 track update.
    [HAND_BESTUECKUNG.csv, JLCPCB_BOM.csv, _t.kicad_pcb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]
2026-08-19 Add MBSE Engineering Copilot: impact graph, audit, export, pitch
    Introduce a model-backed PoC under mbse-app (GitHub Pages /mbse/) with
    requirement impact analysis (E03 12→18 months), traceability audit,
    JSON/PlantUML/SysML v2 export, and a 7-slide board presentation.
    Showcase gains #/pitch and #/copilot entry points.
2026-08-19 Fix /mbse/ 404: serve the app from the mbse/ folder
    The PowerShell showcase server and GitHub Pages look up /mbse/ as a real
    directory. The app lived in mbse-app/, so the URL 404'd. Rename to mbse/.
